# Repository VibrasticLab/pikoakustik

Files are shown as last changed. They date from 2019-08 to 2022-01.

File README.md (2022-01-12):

This is audiometri tool project (still in heavy development).
Main chip are STM32F401RE and Audio-DAC MAX98357A.

### Update:

After a year or so development struggle, now we move to some higher level development stage.
Therefor this repository will be archived and exist only for documentation.

Next development will be moved into new repository: [Pikoakustik2](https://github.com/VibrasticLab/pikoakustik2)

---

### Short Description:

- [x] Fungsional

Mengukur Ambang Pendengaran secara mandiri tanpa perlu bantuan dokter spesialis dan tanpa datang ke klinik.

- [x] Portabel

Dapat digunakan dimana saja dan kapan saja. Baterai mudah diisi ulang.

- [x] Terstandar

Telah terkalibrasi standar Audiometri dan teruji pada ruang *un-echoic*.

- [x] Ramah Pengguna

Antar Muka hanya berupa Tombol dan Lampu LED tanpa pengaturan tambahan dan bisa langsung digunakan.

- [x] Terintergrasi

Terhubung dengan penyimpanan *dedicated server* sehingga dapat diakses dokter spesialis secara jarak jauh jika diperlukan.

---

### Marking Rules:
- [ ] Unfinished
- [x] Finished but Open to Improve
- [x] ~~Finished~~
- [ ] ~~Unused but Noted~~

---

### Implemented Features:

#### User Interaction:

- [X] ~~LED Run Mode Indicator~~
	- [x] ~~Measurement Mode: Blink fast~~
	- [x] ~~Idle Mode: Blink slow~~
	- [x] ~~No Media Mode: Blink fast every 2s~~
- [X] ~~LED TRUE/FALSE~~
- [X] ~~LED Play/MMC~~
- [x] ~~LED 3 Choices~~
- [X] ~~Button Choices~~
	- [x] ~~3 Button Choices~~
	- [x] 3 Choices Random Generator
	- [x] ~~3 Choice Answer Placement~~
- [x] ~~Button Reset~~
- [x] ~~User-Friendlyness Interface Test~~
- [ ] LCD Non-Input Interface
	- [ ] LCD SPI ILI9xxx series

---

#### Packaging

- [x] ~~Acrilic Protector~~
- [ ] Box Design
	- [x] Print 3D
	- [ ] Plastic Molding
	- [x] Brosur Promo with Good Packaging
- [ ] Battery
	- [x] Regulator TP4056
	- [x] ~~LiPo Battery~~
	- [x] ~~Main Power Button~~
	- [ ] Charge/Discharge Test
	- [ ] Battery Manager
	- [x] No Cap except Run Elco

---

#### Data Communication:

- [ ] Serial Data
	- [x] ~~ACM USB-CDC Protocol~~
	- [x] ~~Basic Serial commands~~
	- [x] ~~Media handling commands~~
	- [x] ~~Audiometri control commands~~
	- [ ] HTTP Data control commands

- [x] ~~Media Storage~~
	- [x] ~~MMC Connector Slot~~
	- [x] ~~MMC readyness checking~~
	- [x] ~~FATFS as FAT32 handler~~
	- [x] ~~Via SPI protocol~~

- [ ] IoT Exchanges
	- [x] ESP-12E slot on PCB
	- [x] ESP-12E power jumper
	- [x] WiFi handling
	- [x] Access Point handling
	- [ ] Wifi/AP switch command
	- [ ] HTTP Data exchange
	- [ ] HTTP Data JSON/Format

---

#### Audiometri:

- [ ] Tone Generator
	- [x] ~~Generic I2S Protocol~~
	- [x] ~~Pure Single Tone~~
	- [x] Calibrated Frequency array
	- [x] Pop-Click Suppression
	- [x] Calibrated SPL range
	- [x] Calibrated SPL scaling
	- [x] Left/Right Isolation
	- [ ] Number Headphones
		- [ ] Embedded Tone Model
		- [ ] External Tone Model

- [ ] Hearing Test
	- [x] User Test Flow
	- [ ] **Convinient Level Test**
	- [ ] Random starting SPL
	- [x] Up/Down SPL scaling
	- [ ] Lowest Tone still too loud
	- [ ] Suffle Block
		- [ ] 1 Block is 1 Freq in 1 Channel
		- [ ] Left/Right suffle

- [ ] Microphone Input
	- [ ] Environment Noise Capture
	- [ ] Environment Noise Compensation

- [ ] Mass Production
	- [ ] PCB Electronic
		- [ ] Seeed Studio
		- [ ] ~~DigiKey~~
		- [ ] Xirca
		- [ ] Gerai-Cerdas
		- [ ] ~~Maxtron~~
	- [ ] Packaging

---

### Future Development:

- [ ] Migrate to ESP32
	- [ ] Advantage: Bluetooth Audio A2DP Sources
	- [ ] Advantage: Dual Core CPU as fast as ARM
	- [ ] Advantage: Touch Sensor (replace button)
	- [ ] Disadvantage: Less GPIO pin available
	- [ ] Disadvantage: Re-working all current design
	- [ ] Disadvantage: Re-calibrate and re-test everything

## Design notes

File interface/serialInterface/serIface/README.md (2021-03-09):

# serIface

A new Flutter project.

## Getting Started

This project is a starting point for a Flutter application.

A few resources to get you started if this is your first Flutter project:

- [Lab: Write your first Flutter app](https://flutter.dev/docs/get-started/codelab)
- [Cookbook: Useful Flutter samples](https://flutter.dev/docs/cookbook)

For help getting started with Flutter, view our
[online documentation](https://flutter.dev/docs), which offers tutorials,
samples, guidance on mobile development, and a full API reference.

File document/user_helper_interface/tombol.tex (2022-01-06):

\documentclass[12pt,]{article}
\usepackage[utf8]{inputenc}
\usepackage[T1]{fontenc}
\usepackage{mathptmx}
\usepackage{geometry}
\usepackage{mathtools}
\usepackage[english]{babel}
\usepackage{graphicx}
\usepackage{stackengine}
\usepackage[os=win]{menukeys}
\usepackage{hyperref}
\usepackage{minted}
\usepackage{xcolor}
\usepackage{tikz}
\usepackage[yyyymmdd,hhmmss]{datetime}
\usepackage{etoolbox}
\usepackage{booktabs}

\patchcmd{\thebibliography}{\section*{\refname}}{}{}{}

\newcommand{\ShowOsVersion}{
	\immediate\write18{\unexpanded{foo=`uname -sro` && echo "${foo}" > tmp.tex}}
	\input{tmp}\immediate\write18{rm tmp.tex}
}

\newcommand{\ShowTexVersion}{
	\immediate\write18{\unexpanded{foo=`pdflatex -version | head -n1 | cut -d' ' -f1,2` && echo "${foo}" > tmp.tex}}
	\input{tmp}\immediate\write18{rm tmp.tex}
}

\addto\captionsenglish{\renewcommand{\contentsname}{Daftar Isi}}

\hypersetup{
	colorlinks=true, %set true if you want colored links
	linktoc=all,     %set to all if you want both sections and subsections linked
	linkcolor=blue,  %choose some color if you want links to stand out
	urlcolor=blue,	 %url color
}

\geometry{
	legalpaper,
	left=15mm,
	right=10mm,
	top=10mm,
	bottom=15mm,
}

\title{\Large \bf
	Draft Design Tombol\\
}

\author{Achmadi ST MT}

\date{}

\hypersetup{citecolor=black}

\definecolor{LightGray}{gray}{0.95}

%\pagecolor[rgb]{0.1,0.1,0.1}
%\color[rgb]{1,1,1}

\begin{document}
	\maketitle
	\thispagestyle{empty}
	
	\vspace*{600pt}
	
	\noindent This document written using: \\
	OS : \ShowOsVersion \\
	TeX : \ShowTexVersion \\
	Update: {\today} at \currenttime \\
	
	%%%%%%%%%%%%%%%%%%%%%%%%%%%%%%%%%%%%%%%%%%%%%%%%%%%%%%%%%%%%%%%%%
	
	\newpage
	\begin{figure}[!ht]
		\centering
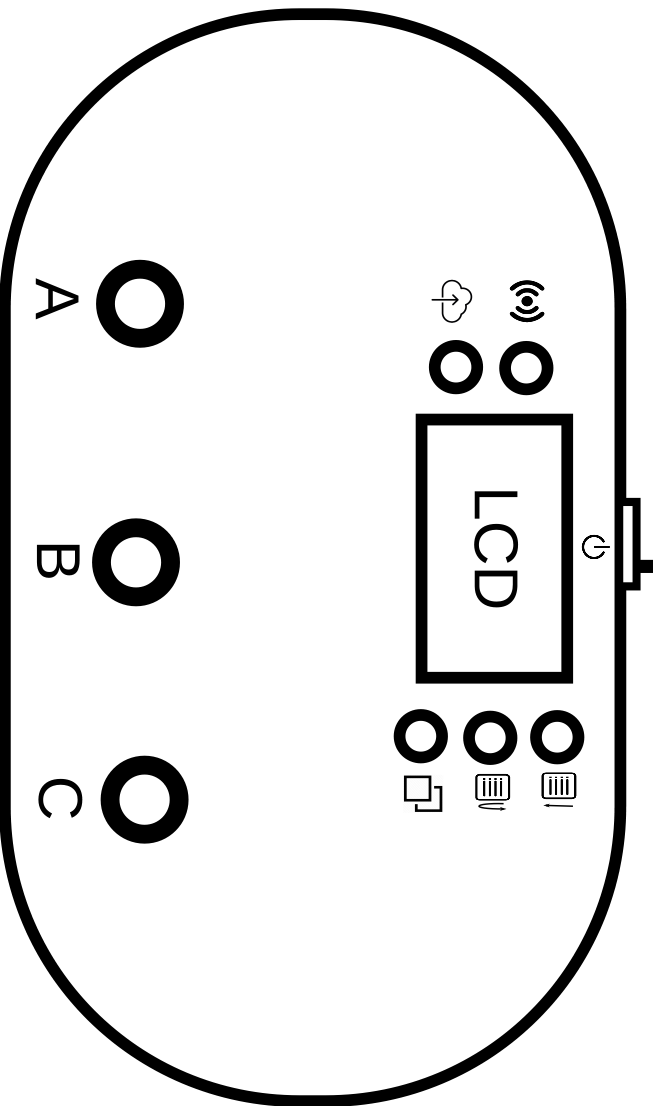
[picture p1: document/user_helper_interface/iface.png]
		
		\caption{Tombol Pengguna}
	\end{figure}

	%%%%%%%%%%%%%%%%%%%%%%%%%%%%%%%%%%%%%%%%%%%%%%%%%%%%%%%%%%%%%%%%%
	
	\newpage
	\section{Daftar Tombol}
	
	Berikut Daftar Tombol untuk Pengguna (diluar Tombol Audiometri):
	
	\begin{table}[H]
		\begin{tabular}{|c|c|}
			\toprule
			
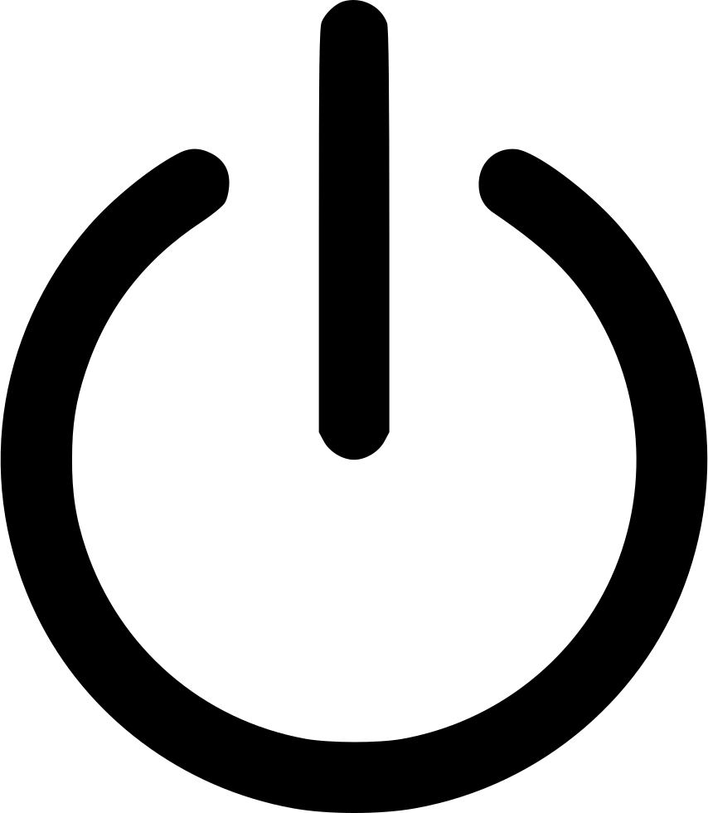
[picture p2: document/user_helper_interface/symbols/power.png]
			\raisebox{-\totalheight}{} & SMD Slide Switch untuk power\textbf{*}
			\\ \midrule
			
			\raisebox{-\totalheight}{} & Seleksi file rekaman langsung memilih rekaman terakhir
			\\ \midrule
			
			\raisebox{-\totalheight}{} & Seleksi file rekaman secara berurutan berulang
			\\ \midrule
			
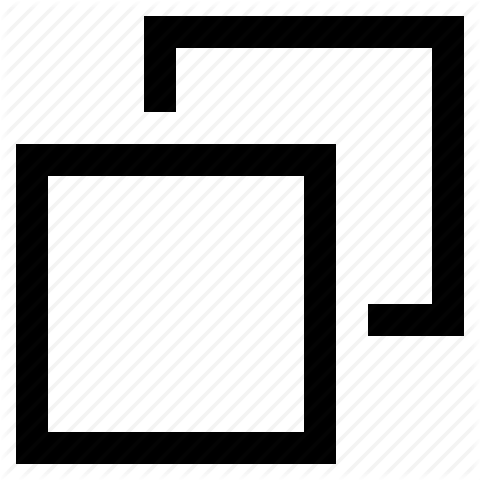
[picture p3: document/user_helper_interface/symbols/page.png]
			\raisebox{-\totalheight}{} & Berpindah halaman yang ditampilkan LCD\textbf{**}
			\\ \midrule
			
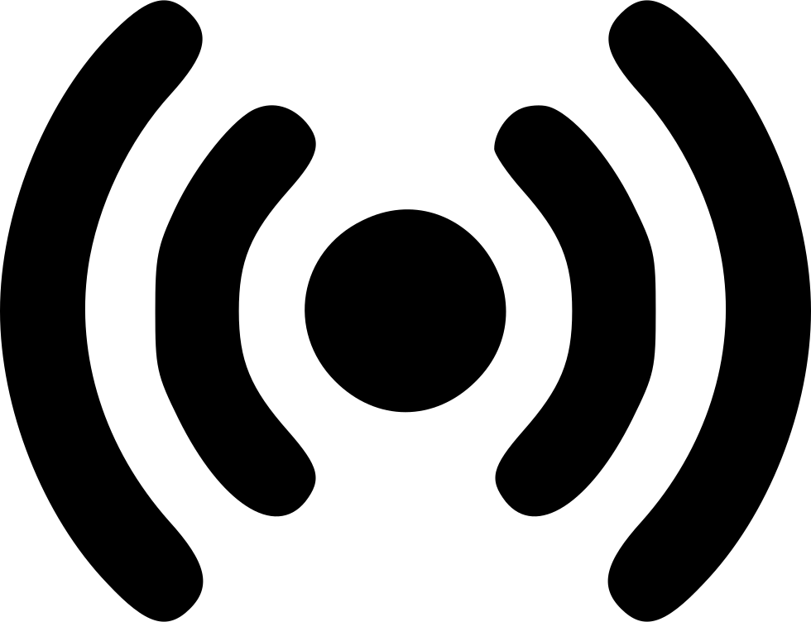
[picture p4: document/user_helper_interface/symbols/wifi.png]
			\raisebox{-\totalheight}{} & Berpindah mode ESP dari Access-Point ke Station atau sebaliknya
			\\ \midrule
			
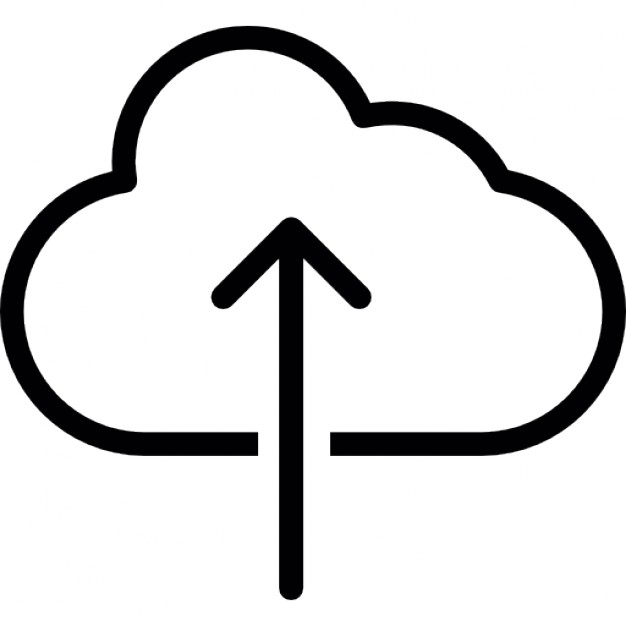
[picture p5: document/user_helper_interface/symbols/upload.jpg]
			\raisebox{-\totalheight}{} & POST request JSON data rekaman ke server
			\\ \midrule
		\end{tabular}
	\end{table}

	\textbf{*}) Contoh SMD Power Switch Slide yang dipilih:
	
	\begin{figure}[!ht]
		\centering
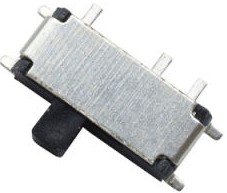
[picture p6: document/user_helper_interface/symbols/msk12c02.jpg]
		
		\caption{MSK12C02}
	\end{figure}

	\textbf{**}) Rencana halaman yang akan ditampilkan di LCD:
	\begin{itemize}
		\item \textbf{Home}. Sebagai halaman pertama yang muncul setelah power on.
		Menampilkan informasi antara lain:
		\begin{itemize}
			\item Persen Battery
			\item Mode ESP sedang dalam Station atau Access Point
			\item Informasi Koneksi seperti IP dan SSID
			\item Mode Audiometri sedang Idle atau Session\\
			Notes: Saat mode Session, maka tampilan dikunci pada halaman Home
		\end{itemize}
		Dapat diakses dengan tombol Pindah Halaman.
	
		\item \textbf{Daftar File}. Menampilkan daftar file untuk dipilih secara berurutan berulang.\\
		Hanya dapat diakses melalu tombol Seleksi File.
		
		\item \textbf{Upload}. Menampilkan proses kirim data file rekaman terpilih.\\
		Hanya dapat diakses melalu tombol Upload.
		
		\item \textbf{Audiogram}. Menampilkan preview data Audiogram dari file rekaman terpilih.\\
		Dapat diakses dengan tombol Pindah Halaman.
		
		\item \textbf{Metadata}. Menampilkan metadata dari file rekaman terpilih.\\
		Dapat diakses dengan tombol Pindah Halaman.
	\end{itemize}

	\textbf{Tambahan:}
	\begin{itemize}
		\item Untuk tombol memulai Audiometri dan 3-Force Choice tetap menggunakan 3 tombol Audiometri \textbf{A-B-C}.
		\item Port USB untuk komunikasi serial dengan PC tetap diperlukan untuk proses debugging/kontrol selama proses development.
	\end{itemize}

\end{document}

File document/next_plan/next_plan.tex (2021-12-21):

\documentclass[12pt,]{article}
\usepackage[utf8]{inputenc}
\usepackage[T1]{fontenc}
\usepackage{mathptmx}
\usepackage{geometry}
\usepackage{mathtools}
\usepackage[english]{babel}
\usepackage{graphicx}
\usepackage{stackengine}
\usepackage[os=win]{menukeys}
\usepackage{hyperref}
\usepackage{minted}
\usepackage{xcolor}
\usepackage{tikz}
\usepackage[yyyymmdd,hhmmss]{datetime}
\usepackage{etoolbox}

\patchcmd{\thebibliography}{\section*{\refname}}{}{}{}

\newcommand{\ShowOsVersion}{
	\immediate\write18{\unexpanded{foo=`uname -sro` && echo "${foo}" > tmp.tex}}
	\input{tmp}\immediate\write18{rm tmp.tex}
}

\newcommand{\ShowTexVersion}{
	\immediate\write18{\unexpanded{foo=`pdflatex -version | head -n1 | cut -d' ' -f1,2` && echo "${foo}" > tmp.tex}}
	\input{tmp}\immediate\write18{rm tmp.tex}
}

\addto\captionsenglish{\renewcommand{\contentsname}{Daftar Isi}}

\hypersetup{
	colorlinks=true, %set true if you want colored links
	linktoc=all,     %set to all if you want both sections and subsections linked
	linkcolor=blue,  %choose some color if you want links to stand out
	urlcolor=blue,	 %url color
}

\geometry{
	legalpaper,
	left=15mm,
	right=10mm,
	top=10mm,
	bottom=15mm,
}

\title{\Large \bf
	Draft Design\\
}

\author{Achmadi ST MT}

\date{}

\hypersetup{citecolor=black}

\definecolor{LightGray}{gray}{0.95}

%\pagecolor[rgb]{0.1,0.1,0.1}
%\color[rgb]{1,1,1}

\begin{document}
	\maketitle
	\thispagestyle{empty}
	
	\vspace*{600pt}
	
	\noindent This document written using: \\
	OS : \ShowOsVersion \\
	TeX : \ShowTexVersion \\
	Update: {\today} at \currenttime \\
	
	%%%%%%%%%%%%%%%%%%%%%%%%%%%%%%%%%%%%%%%%%%%%%%%%%%%%%%%%%%%%%%%%%
	
	\newpage
	\begin{figure}[!ht]
		\centering
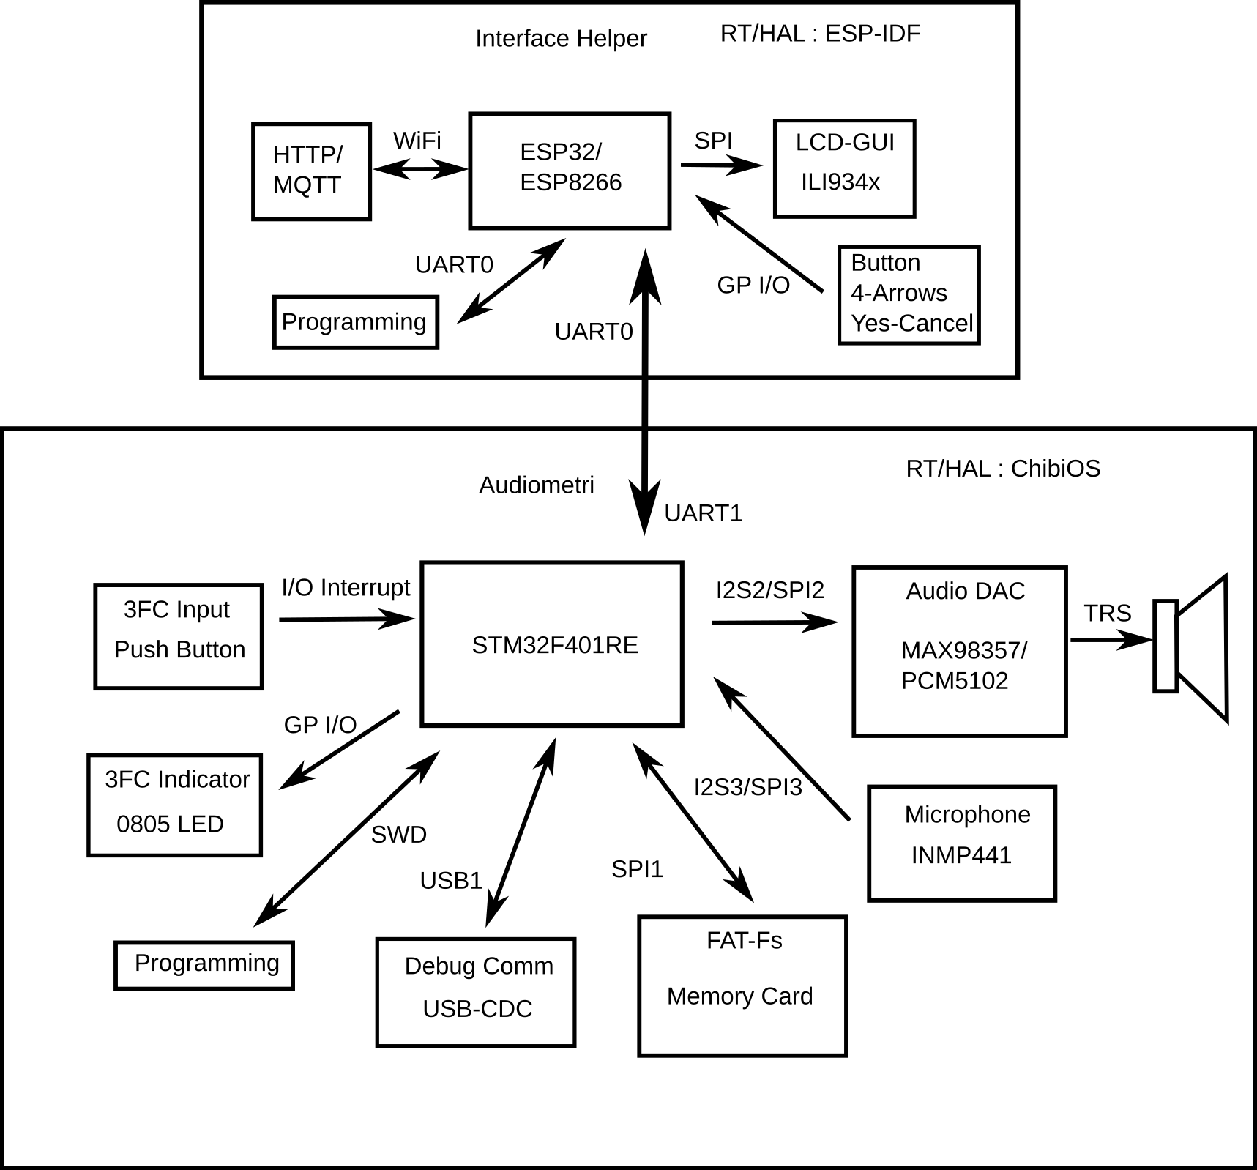
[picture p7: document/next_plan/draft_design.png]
		
		\caption{Simplified}
	\end{figure}

	Currently Developed Design:
	\begin{itemize}
		\item Circuit:\\
		\url{https://github.com/VibrasticLab/pikoakustik/tree/stm32f401re_3pin/circuit/test_3rev1}
		
		\item Audiometri (ChibiOS/RT in STM32F410RE):
		\begin{itemize}
			\item Audio DAC MAX98357A:\\
			\url{https://github.com/VibrasticLab/pikoakustik/blob/stm32f401re_3pin/firmware/ht_audio.c}
			
			\item FAT-Fs Memory Card:\\
			\url{https://github.com/VibrasticLab/pikoakustik/blob/stm32f401re_3pin/firmware/ht_mmc.c}
			
			\item Debug Communication:\\
			\url{https://github.com/VibrasticLab/pikoakustik/blob/stm32f401re_3pin/firmware/ht_comm.c}
			
			\item 3FC Audiometri:\\
			\url{https://github.com/VibrasticLab/pikoakustik/blob/stm32f401re_3pin/firmware/ht_exti.c}\\
			\url{https://github.com/VibrasticLab/pikoakustik/blob/stm32f401re_3pin/firmware/ht_led.c}\\
			\url{https://github.com/VibrasticLab/pikoakustik/blob/stm32f401re_3pin/firmware/ht_metri.c}
			
			\item Microphone INMP441:\\
			(in development)
			
		\end{itemize}
	
		\item ESP32 Interface:\\
		(in development)
	\end{itemize}
\end{document}

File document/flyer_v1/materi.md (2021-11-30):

# Materi Konten Flyer

## Acara
- Health Business Gathering Desember 3rd-4th, 2021

## GuideLines/Materi
- Dilarang Foto Unit Asli (arahan Pak Dhany)
- Gambar Sketsa 
	+ Gambar.1 Sketsa prototype di dokumen Paten (sketsa_unit.png)
	+ Gambar.2 Sketsa penggunaan Prototype di dokumen Paten (sketsa_penggunaan.png)
- Model 3D unit (tanpa keterangan apa pun) di file mockup.png
- Model Alur Data sekilas (alur_data.png)

## Emphasis
- [x] User Friendly
- [x] Handheld Portable
- [x] Embeddded IoT Based
- [x] Calibrated Tone

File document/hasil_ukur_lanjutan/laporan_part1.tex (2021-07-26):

\documentclass[12pt,]{article}
\usepackage[utf8]{inputenc}
\usepackage[T1]{fontenc}
\usepackage{mathptmx}
\usepackage{geometry}
\usepackage{mathtools}
\usepackage[english]{babel}
\usepackage{graphicx}
\usepackage{subcaption}
\usepackage{stackengine}
\usepackage[os=win]{menukeys}
\usepackage{hyperref}
\usepackage{minted}
\usepackage{xcolor}
\usepackage{tikz}
\usepackage[yyyymmdd,hhmmss]{datetime}
\usepackage{etoolbox}
\usepackage[inline]{enumitem}
\usepackage{pdfpages}

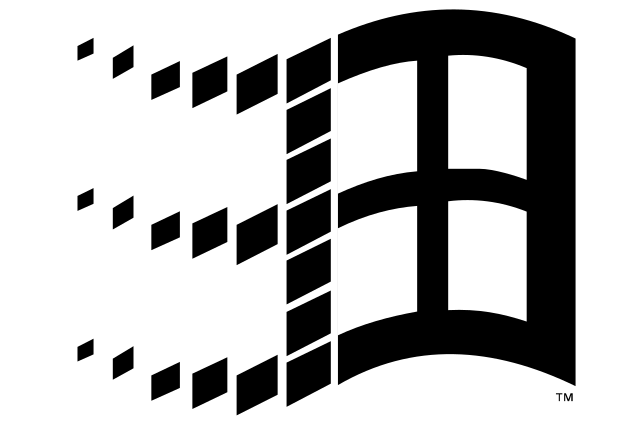
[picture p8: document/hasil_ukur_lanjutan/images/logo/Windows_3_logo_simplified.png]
\newcommand{\WindowsLogo}{\raisebox{-0.1em}{}}
%\newcommand{\PowerLogo}{\raisebox{-0.1em}{\includegraphics[height=0.8em]{images/logo/power}}}
\newcommand{\WinKey}{\keys{\WindowsLogo}}
\newcommand{\PowerKey}{\keys{\PowerLogo}}

\patchcmd{\thebibliography}{\section*{\refname}}{}{}{}

\newcommand{\ShowOsVersion}{
	\immediate\write18{\unexpanded{foo=`uname -sro` && echo "${foo}" > tmp.tex}}
	\input{tmp}\immediate\write18{rm tmp.tex}
}

\newcommand{\ShowTexVersion}{
	\immediate\write18{\unexpanded{foo=`pdflatex -version | head -n1 | cut -d' ' -f1,2` && echo "${foo}" > tmp.tex}}
	\input{tmp}\immediate\write18{rm tmp.tex}
}

\addto\captionsenglish{\renewcommand{\contentsname}{Daftar Isi}}
\addto\captionsenglish{\renewcommand{\figurename}{Gambar}}

\hypersetup{
	colorlinks=true, %set true if you want colored links
	linktoc=all,     %set to all if you want both sections and subsections linked
	linkcolor=blue,  %choose some color if you want links to stand out
	urlcolor=blue,   %url color
}

\geometry{
	a4paper,
	left=10mm,
	right=10mm,
	top=10mm,
	bottom=15mm,
}

\title{\LARGE \bf
	Laporan Pengujian Unit Prototype Handheld Audiometri (Tahap 1)\\
}

\author{Achmadi ST MT}

\date{}

\hypersetup{citecolor=black}

\definecolor{LightGray}{gray}{0.95}

%\pagecolor[rgb]{0.1,0.1,0.1}
%\color[rgb]{1,1,1}

\begin{document}
	\thispagestyle{empty}

	\begin{titlepage}
		\centering
		\vfill
		\vfill
		\maketitle
		\vfill
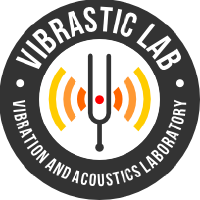
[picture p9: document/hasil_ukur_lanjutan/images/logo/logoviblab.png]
		
		\vfill
		\vfill
		Update: {\today} \currenttime \\
	\end{titlepage}

	%%%%%%%%%%%%%%%%%%%%%%%%%%%%%%%%%%%%%%%%%%%%%%%%%%%%%%%%%%%%%%%%%

	\newpage
	\tableofcontents

	%%%%%%%%%%%%%%%%%%%%%%%%%%%%%%%%%%%%%%%%%%%%%%%%%%%%%%%%%%%%%%%%%

	\newpage
	\section{Pendahuluan}

	\subsection{Tujuan Pengujian}

	Tujuan Pengujian disini adalah untuk mengetahui nilai aktual \textit{loudness} output dalam dB (SPL).

	\subsection{Waktu dan Tempat Pengujian}

	Seluruh pengujian di lakukan di Ruang Un-Echoic Chamber Laboratorium Fisika Bangunan Teknik Fisika
	Institut Teknologi Bandung. Waktu pengujian adalah minggu kedua di bulan Desember 2020.

	\subsection{Batasan Pengujian}

	Batasan pengujian adalah sebagai berikut:

	\begin{enumerate}
		\item Nilai frekuensi dan konsistensi frekuensi tidak diukur di ruang Unechoic chamber tersebut di atas
		karena telah diuji selama proses pengembangan dan perakitan unit prototype dan telah terbukti konsisten pada nilai yang diinginkan.

		\item Pengujian tidak dilakukan pada tubuh manusia sebenarnya melainkan menggunakan manekin yang diproduksi oleh GRASS KEMAR.
	\end{enumerate}

	%%%%%%%%%%%%%%%%%%%%%%%%%%%%%%%%%%%%%%%%%%%%%%%%%%%%%%%%%%%%%%%%%

	\newpage
	\section{Metode Pengujian}

	\subsection{Persiapan}

	Berikut adalah perangkat keras yang perlu disiapkan untuk pengujian ini:

	\begin{itemize}

		\item Unit Prototype Audiometri yang akan diuji.

		Pastikan unit prototype masih normal sebagaimana pada bab sebelumnya.

		\begin{figure}[!ht]
			\centering
			\begin{subfigure}[b]{0.3\textwidth}
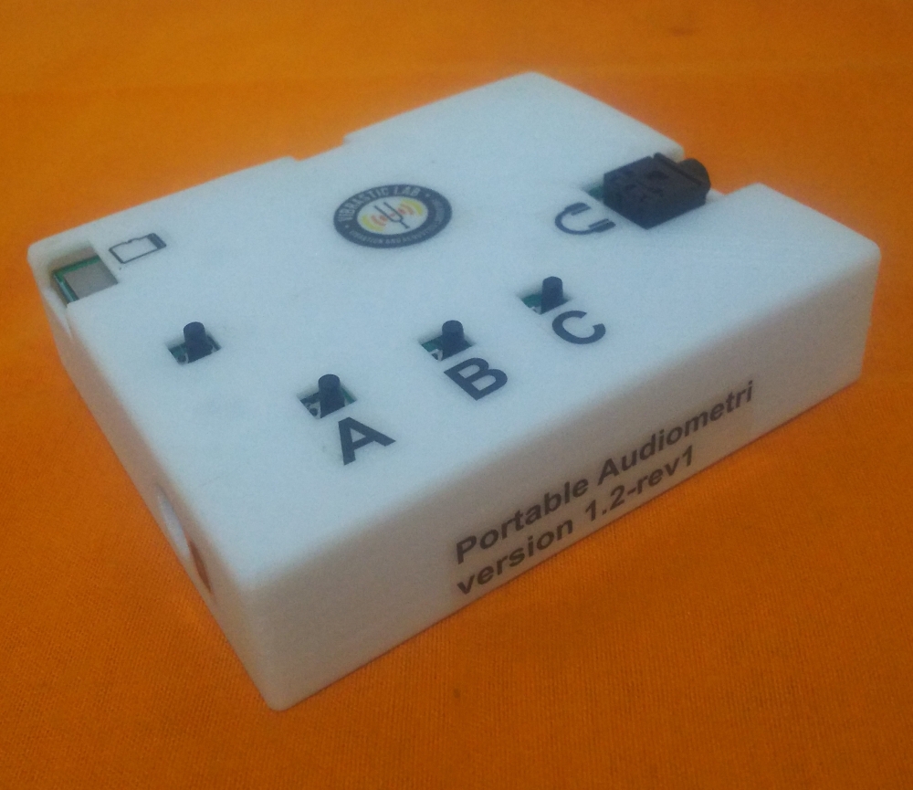
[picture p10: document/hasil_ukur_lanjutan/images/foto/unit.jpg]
				
				\caption{Unit Prototype}
			\end{subfigure}
			\begin{subfigure}[b]{0.3\textwidth}
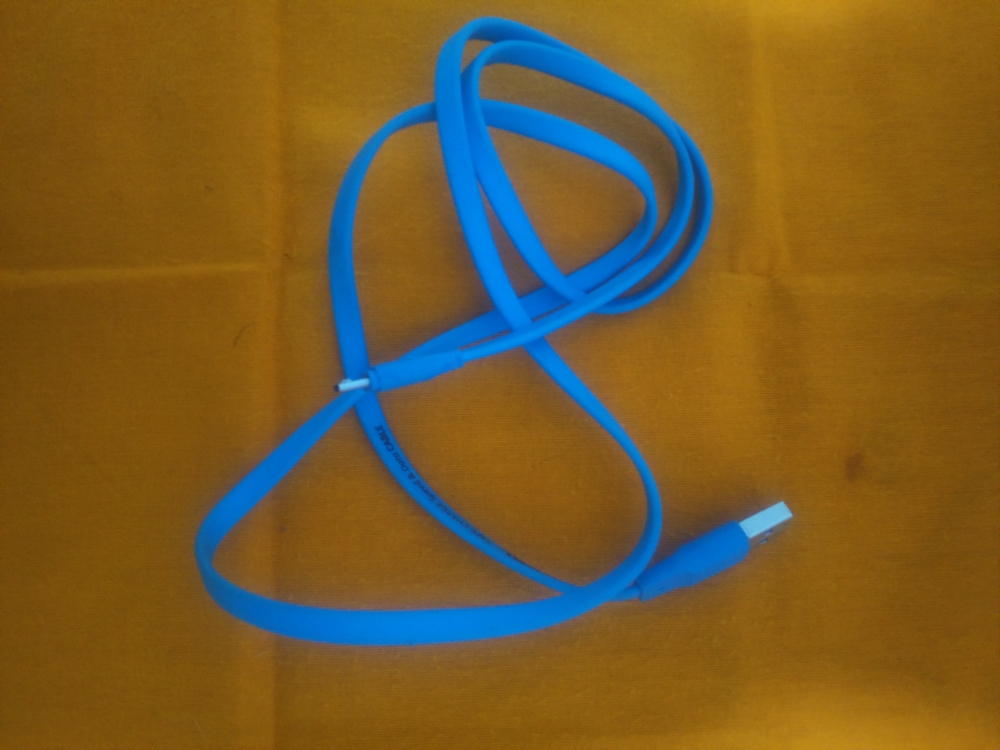
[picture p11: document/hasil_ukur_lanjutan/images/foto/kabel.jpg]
				
				\caption{Kabel USB}
			\end{subfigure}
			\caption{Prototype}
		\end{figure}

		\item Wired-Headphone dengan impedansi tiap channel antara $32\Omega$ hingga $300\Omega$

		Headphone yang digunakan disini adalah:
		\begin{itemize}
			\item Headphone Miniso (tanpa active noise cancelling)
			\item Headphone BOSE (dilengkapi active noise cancelling)
		\end{itemize}
		\begin{figure}[!ht]
			\centering
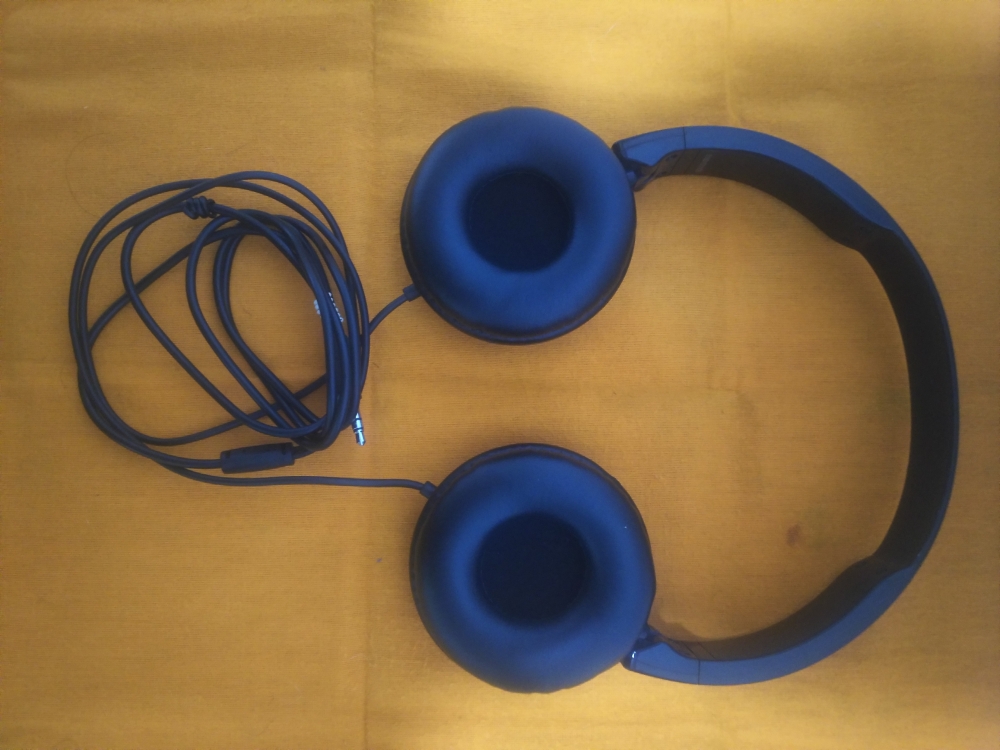
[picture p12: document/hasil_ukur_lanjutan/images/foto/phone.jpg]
			
			\caption{Wired Headphone}
		\end{figure}

		\newpage
		\item Kalibrasi Mikrofon pada manekin KEMAR menggunakan \textit{tone generator} yang tersedia pada paket GRASS KEMAR.
		Kemudian pasang Headphone pada manekin.
		\begin{figure}[!ht]
			\centering
			\begin{subfigure}[b]{0.3\textwidth}
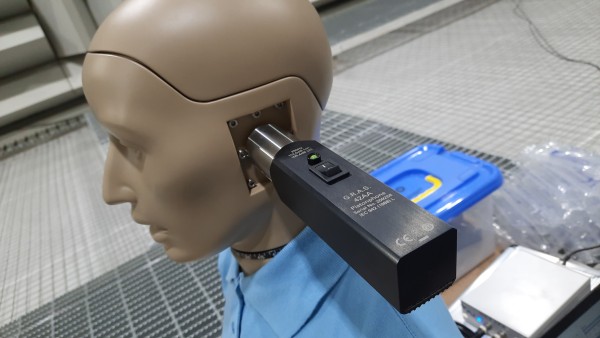
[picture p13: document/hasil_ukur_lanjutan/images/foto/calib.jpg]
				
				\caption{Kalibrasi Mikrofon}
			\end{subfigure}
			\begin{subfigure}[b]{0.3\textwidth}
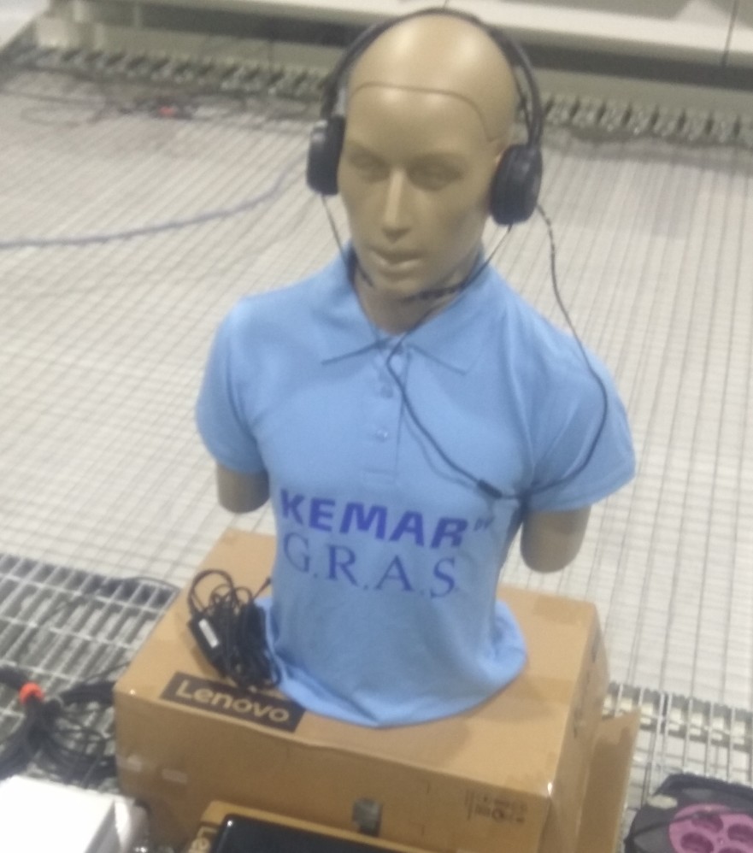
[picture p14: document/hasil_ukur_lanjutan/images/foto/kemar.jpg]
				
				\caption{Headphone Terpasang}
			\end{subfigure}
			\caption{GRASS KEMAR}
		\end{figure}

	\end{itemize}

	\subsection{Audio Analyzer}

	Mikrofon GRASS KEMAR dihubungkan dengan Audio-Box dan data Audio digital dikumpulkan dengan perangkat lunak Real-Time Analyzer via USB.
	Perangkat lunak ini merupakan bagian dari paket software DSFF3 buatan Yoshimasha.

	\begin{figure}[!ht]
		\centering
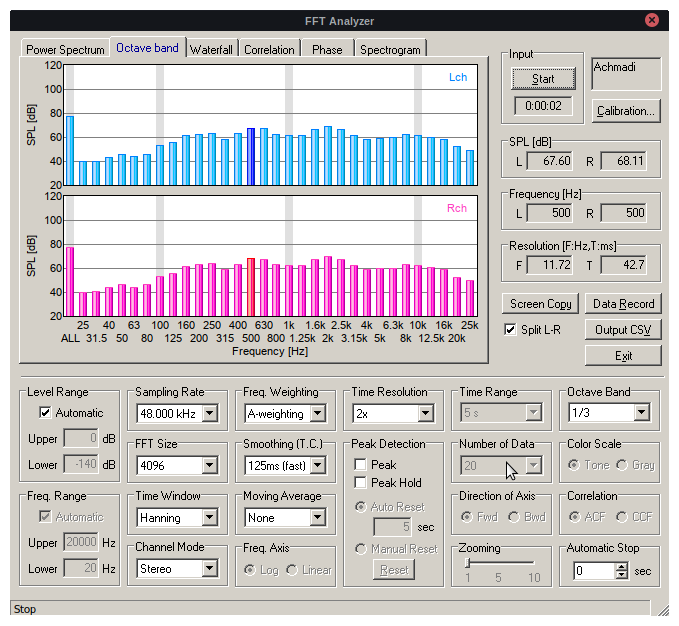
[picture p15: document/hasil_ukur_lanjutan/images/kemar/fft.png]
		
		\caption{Tampilan Audio Analyzer}
	\end{figure}

	\newpage
	\subsection{Teknis Pengujian}

	Berikut langkah proses pengujian

	\begin{itemize}
		\item Nyalakan unit prototype dan sambungkan USB protype ke komputer.
		\begin{figure}[!ht]
			\centering
			\begin{subfigure}[b]{0.3\textwidth}
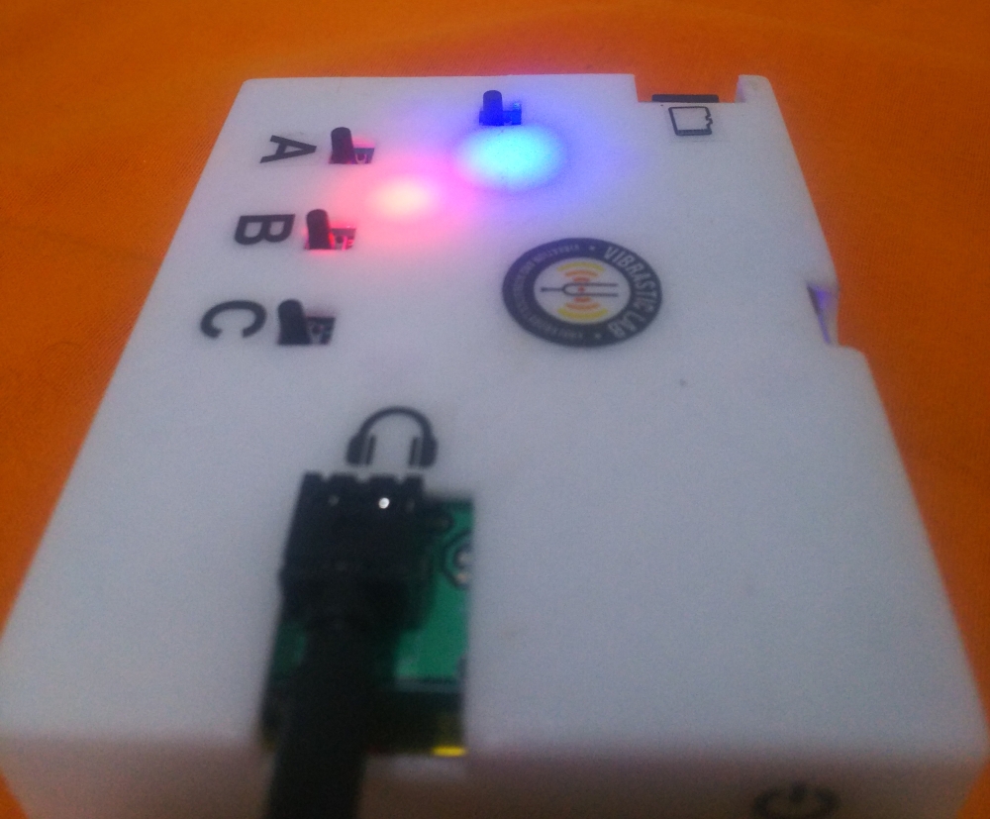
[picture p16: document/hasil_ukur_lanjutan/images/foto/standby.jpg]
				
				\caption{Prototype Standby}
			\end{subfigure}
			\begin{subfigure}[b]{0.3\textwidth}
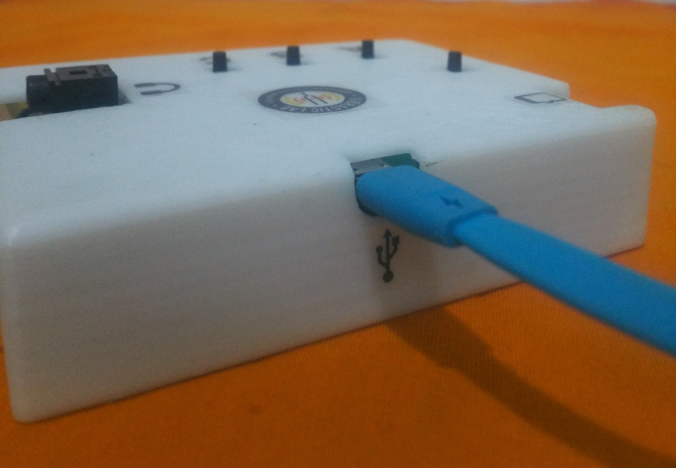
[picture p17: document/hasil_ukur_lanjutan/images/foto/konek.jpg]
				
				\caption{USB Terpasang}
			\end{subfigure}
			\caption{Menyalakan Unit Prototype}
		\end{figure}

		\item Akses prototype menggunakan serial port (semisal Hercules.exe) pada komputer.
		\begin{figure}[!ht]
			\centering
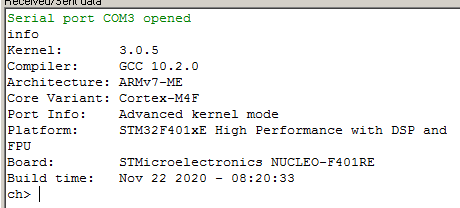
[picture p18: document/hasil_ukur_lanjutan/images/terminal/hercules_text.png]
			
			\caption{Contoh respon serial port}
		\end{figure}

		\item Perintah Serial untuk membangkitkan tone
		Perintah untuk membangkitkan tone dengan frekuensi dan skala yang diinginkan selama 5detik.

		Pola perintah serialnya adalah:
		\begin{minted}[frame=lines,framesep=2mm,fontsize=\small]{text}
out <frekuensi> <amplitudo>
		\end{minted}

		dengan:
		\begin{itemize}

			\item frekuensi adalah nilai frekuensi (dalam Hz) mulai 250, 500, 1000, 2000, 4000, dan 8000.

			\item amplitudo adalah skala amplitudo pada nilai 1, 2, 3, 4, 5, 6, 7, 8, dan 9.

		\end{itemize}

		Contoh untuk tone 500Hz pada skala amplitudo 6 (diakhiri (\keys{\return})):
		\begin{minted}[frame=lines,framesep=2mm,fontsize=\small]{text}
out 500 6
		\end{minted}

		\newpage
		Maka salah satu channel headphone yang terhubung prototype akan membangkitkan tone selama 5 detik.

		\begin{figure}[!ht]
			\centering
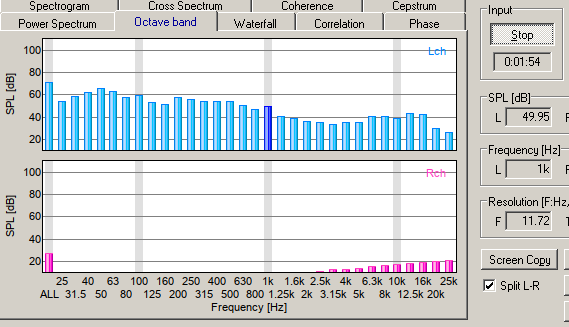
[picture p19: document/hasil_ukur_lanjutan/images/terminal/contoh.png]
			
			\caption{Contoh Nilai Uji}
		\end{figure}

		\item Hasil yang diinginkan adalah tabel dengan spesifikasi berikut:
		\begin{itemize}
			\item tabel loudness output di setiap frekuensi untuk setiap skala amplitudo, untuk 2 prototype dengan 2 headphone
			\item tabel loudness output di setiap frekuensi untuk setiap skala amplitudo, untuk 2 prototype dengan 2 headphone
		\end{itemize}

		sehingga diharapkan total 4 tabel hasil pengukuran.
	\end{itemize}

	\newpage
	\section{Hasil Pengujian}

	\subsection{Tabel Hasil}

	Tabel hasil pengujian cukuk banyak yang akan memakan tempat disini sehingga disediakan tempat di repository pemrograman Lab Vibrastic pada tautan berikut:\\
	\url{https://github.com/VibrasticLab/pikoakustik/tree/stm32f401re_3pin/document/hasil_ukur_lanjutan/tabel_hasil_ukur}.\\

	Kemudian untuk memudahkan proses pengolahan data, digunakan pula perangkat lunak Jupyter Note yang berkasnya dapat diakses di tautan:\\
	\url{https://github.com/VibrasticLab/pikoakustik/blob/stm32f401re_3pin/document/hasil_ukur_lanjutan/python/hasil_itb.ipynb}\\

	\subsection{Pengolahan Data}

	Pengolahan data hasil pengujian digunakan untuk mendapatkan model loudness.

		Dengan merata-rata matrix tabel didapat matrix untuk headphone Bose sebagai berikut:

		\[\left[
		\begin{matrix}
			34.4 & 36.5 & 40.7 & 45.7 & 51.4 & 57.4 & 63.4 & 69.5 & 75.6 \\
			32.6 & 35.8 & 40.2 & 44.9 & 50.2 & 56.6 & 62.7 & 68.8 & 74.8 \\
			37.7 & 41   & 45.5 & 51   & 56.8 & 62.9 & 69   & 75   & 81   \\
			36.3 & 38.6 & 42.4 & 47.7 & 53.2 & 59.2 & 65.4 & 71.4 & 77.4 \\
			41.1 & 43.8 & 48   & 53.2 & 59   & 64.9 & 71.1 & 77.1 & 83.1 \\
			41.8 & 42.6 & 44.9 & 49   & 54.4 & 60.2 & 66.2 & 72.2 & 78.2 \\
		\end{matrix}
		\right]\]

		Pendekatan model matematis untuk loudness terhadap skala input menggunakan polynomial:\\
		\[f(x) = ax^3 + bx^2 + cx + d\]

		Estimasi model menggunakan perangkat lunak Numpy Polyfit yang tersedia di Python.
		Hasil estimasi untuk headphone Bose pada setiap frekuensi.

		\[f_{250}(x) = 0.05x^3 - 0.46x^2 - 4.7x + 80.5\]
		\[f_{500}(x) = 0.03x^3 - 0.28x^2 - 5.4x + 80.48\]
		\[f_{1000}(x) = 0.04x^3 - 0.4x^2 - 4.8x + 86.06\]
		\[f_{2000}(x) = 0.05x^3 - 0.49x^2 - 4.59x + 82.33\]
		\[f_{4000}(x) = 0.04x^3 - 0.44x^2 - 4.72x + 88.12\]
		\[f_{8000}(x) = 0.06x^3 - 0.59x^2 - 4.37x + 83\]

		Selanjutnya untuk headphone Miniso, dilakukan metode perhitungan yang sama.

		Berikut matrix rata-rata loudness pengukuran:

		\[\left[
		\begin{matrix}
			36   & 39.5 & 44.2 & 49.7 & 55.6 & 61.4 & 67.4 & 73.4 & 79.4 \\
			36.7 & 40.5 & 45.4 & 50.8 & 56.7 & 62.6 & 68.6 & 74.6 & 80.6 \\
			39.9 & 43.6 & 48.6 & 54.2 & 60   & 65.9 & 71.8 & 77.8 & 83.8 \\
			33   & 35.4 & 39.6 & 44.7 & 50.4 & 56.4 & 62.4 & 68.3 & 74.4 \\
			32.7 & 33.4 & 35.3 & 39.2 & 44.3 & 50   & 56   & 62   & 68   \\
			35.6 & 36.2 & 38.3 & 41.8 & 47   & 52.6 & 58.6 & 64.6 & 70.5 \\
		\end{matrix}
		\right]\]

        \newpage
		Hasil estimasi untuk Headphone Miniso pada setiap frekuensi.

		\[f_{250}(x) = 0.03x^3 - 0.32x^2 - 4.99x + 84.58\]
		\[f_{500}(x) = 0.03x^3 - 0.28x^2 - 5.16x + 85.93\]
		\[f_{1000}(x) = 0.03x^3 - 0.28x^2 - 5.09x + 36.38\]
		\[f_{2000}(x) = 0.04x^3 - 0.46x^2 - 4.63x + 37.21\]
		\[f_{4000}(x) = 0.06x^3 - 0.53x^2 - 4.64x + 39.77\]
		\[f_{8000}(x) = 0.06x^3 - 0.51x^2 - 4.67x + 42.73\]

	\newpage
	\section{Lampiran}

	\subsection{Notebook Olah Data}
	\includepdf[pages=-]{python/hasil_itb.pdf}

\end{document}

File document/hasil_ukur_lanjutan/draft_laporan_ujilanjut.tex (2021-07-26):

\documentclass[12pt,]{article}
\usepackage[utf8]{inputenc}
\usepackage[T1]{fontenc}
\usepackage{mathptmx}
\usepackage{geometry}
\usepackage{mathtools}
\usepackage[english]{babel}
\usepackage{graphicx}
\usepackage{subcaption}
\usepackage{stackengine}
\usepackage[os=win]{menukeys}
\usepackage{hyperref}
\usepackage{minted}
\usepackage{xcolor}
\usepackage{tikz}
\usepackage[yyyymmdd,hhmmss]{datetime}
\usepackage{etoolbox}
\usepackage[inline]{enumitem}
\usepackage{pdfpages}

\newcommand{\WindowsLogo}{\raisebox{-0.1em}{}}
%\newcommand{\PowerLogo}{\raisebox{-0.1em}{\includegraphics[height=0.8em]{images/logo/power}}}
\newcommand{\WinKey}{\keys{\WindowsLogo}}
\newcommand{\PowerKey}{\keys{\PowerLogo}}

\patchcmd{\thebibliography}{\section*{\refname}}{}{}{}

\newcommand{\ShowOsVersion}{
	\immediate\write18{\unexpanded{foo=`uname -sro` && echo "${foo}" > tmp.tex}}
	\input{tmp}\immediate\write18{rm tmp.tex}
}

\newcommand{\ShowTexVersion}{
	\immediate\write18{\unexpanded{foo=`pdflatex -version | head -n1 | cut -d' ' -f1,2` && echo "${foo}" > tmp.tex}}
	\input{tmp}\immediate\write18{rm tmp.tex}
}

\addto\captionsenglish{\renewcommand{\contentsname}{Daftar Isi}}
\addto\captionsenglish{\renewcommand{\figurename}{Gambar}}

\hypersetup{
	colorlinks=true, %set true if you want colored links
	linktoc=all,     %set to all if you want both sections and subsections linked
	linkcolor=blue,  %choose some color if you want links to stand out
	urlcolor=blue,   %url color
}

\geometry{
	a4paper,
	left=10mm,
	right=10mm,
	top=10mm,
	bottom=15mm,
}

\title{\LARGE \bf
	Laporan Pengujian Unit Prototype Portable/Handheld Audiometri\\
}

\author{Achmadi ST MT}

\date{}

\hypersetup{citecolor=black}

\definecolor{LightGray}{gray}{0.95}

%\pagecolor[rgb]{0.1,0.1,0.1}
%\color[rgb]{1,1,1}

\begin{document}
	\thispagestyle{empty}

	\begin{titlepage}
		\centering
		\vfill
		\vfill
		\maketitle
		\vfill
		
		\vfill
		\vfill
		Update: {\today} \currenttime \\
	\end{titlepage}

	%%%%%%%%%%%%%%%%%%%%%%%%%%%%%%%%%%%%%%%%%%%%%%%%%%%%%%%%%%%%%%%%%

	\newpage
	\tableofcontents

	%%%%%%%%%%%%%%%%%%%%%%%%%%%%%%%%%%%%%%%%%%%%%%%%%%%%%%%%%%%%%%%%%

	\newpage
	\section{Pendahuluan}

	\subsection{Tujuan Pengujian}

	Tujuan Pengujian disini adalah untuk mendapatkan parameter berikut:
	\begin{enumerate}
		\item Mengetahui nilai aktual \textit{loudness} output dalam dB (SPL).
		\item Mengetahui efek histeresis terhadap konsistensi output \textit{loudness}.
	\end{enumerate}

	\subsection{Waktu dan Tempat Pengujian}

	Seluruh pengujian di lakukan di Ruang Un-Echoic Chamber Laboratorium Fisika Bangunan Teknik Fisika
	Institut Teknologi Bandung. Waktu pengujian terbagi dalam 2 periode, pertama pada bulan Desember 2020 dan Februari 2021.

	\subsection{Batasan Pengujian}

	Batasan pengujian adalah sebagai berikut:

	\begin{enumerate}
		\item Nilai frekuensi dan konsistensi frekuensi tidak diukur di ruang Unechoic chamber tersebut di atas
		karena telah diuji selama proses pengembangan dan perakitan unit prototype dan telah terbukti konsisten pada nilai yang diinginkan.

		\item Pengujian tidak dilakukan pada tubuh manusia sebenarnya melainkan menggunakan manekin yang diproduksi oleh GRASS KEMAR.
	\end{enumerate}

	%%%%%%%%%%%%%%%%%%%%%%%%%%%%%%%%%%%%%%%%%%%%%%%%%%%%%%%%%%%%%%%%%

	\newpage
	\section{Metode Pengujian}

	\subsection{Persiapan}

	Berikut adalah perangkat keras yang perlu disiapkan untuk pengujian ini:

	\begin{itemize}

		\item Unit Prototype Audiometri yang akan diuji.

		Pastikan unit prototype masih normal sebagaimana pada bab sebelumnya.

		\begin{figure}[!ht]
			\centering
			\begin{subfigure}[b]{0.3\textwidth}
				
				\caption{Unit Prototype}
			\end{subfigure}
			\begin{subfigure}[b]{0.3\textwidth}
				
				\caption{Kabel USB}
			\end{subfigure}
			\caption{Prototype}
		\end{figure}

		\item Wired-Headphone dengan impedansi tiap channel antara $32\Omega$ hingga $300\Omega$

		Headphone yang digunakan disini adalah:
		\begin{itemize}
			\item Headphone Miniso (tanpa active noise cancelling)
			\item Headphone BOSE (dilengkapi active noise cancelling)
		\end{itemize}
		\begin{figure}[!ht]
			\centering
			
			\caption{Wired Headphone}
		\end{figure}

		\newpage
		\item Kalibrasi Mikrofon pada manekin KEMAR menggunakan \textit{tone generator} yang tersedia pada paket GRASS KEMAR.
		Kemudian pasang Headphone pada manekin.
		\begin{figure}[!ht]
			\centering
			\begin{subfigure}[b]{0.3\textwidth}
				
				\caption{Kalibrasi Mikrofon}
			\end{subfigure}
			\begin{subfigure}[b]{0.3\textwidth}
				
				\caption{Headphone Terpasang}
			\end{subfigure}
			\caption{GRASS KEMAR}
		\end{figure}

	\end{itemize}

	\subsection{Audio Analyzer}

	Mikrofon GRASS KEMAR dihubungkan dengan Audio-Box dan data Audio digital dikumpulkan dengan perangkat lunak Real-Time Analyzer via USB.
	Perangkat lunak ini merupakan bagian dari paket software DSFF3 buatan Yoshimasha.

	\begin{figure}[!ht]
		\centering
		
		\caption{Tampilan Audio Analyzer}
	\end{figure}

	\newpage
	\subsection{Teknis Pengujian}

	Berikut langkah proses pengujian

	\begin{itemize}
		\item Nyalakan unit prototype dan sambungkan USB protype ke komputer.
		\begin{figure}[!ht]
			\centering
			\begin{subfigure}[b]{0.3\textwidth}
				
				\caption{Prototype Standby}
			\end{subfigure}
			\begin{subfigure}[b]{0.3\textwidth}
				
				\caption{USB Terpasang}
			\end{subfigure}
			\caption{Menyalakan Unit Prototype}
		\end{figure}

		\item Akses prototype menggunakan serial port (semisal Hercules.exe) pada komputer.
		\begin{figure}[!ht]
			\centering
			
			\caption{Contoh respon serial port}
		\end{figure}

		\item Perintah Serial untuk membangkitkan tone
		Perintah untuk membangkitkan tone dengan frekuensi dan skala yang diinginkan selama 5detik.

		Pola perintah serialnya adalah:
		\begin{minted}[frame=lines,framesep=2mm,fontsize=\small]{text}
out <frekuensi> <amplitudo>
		\end{minted}

		dengan:
		\begin{itemize}

			\item frekuensi adalah nilai frekuensi (dalam Hz) mulai 250, 500, 1000, 2000, 4000, dan 8000.

			\item amplitudo adalah skala amplitudo pada nilai 1, 2, 3, 4, 5, 6, 7, 8, dan 9.

		\end{itemize}

		Contoh untuk tone 500Hz pada skala amplitudo 6 (diakhiri (\keys{\return})):
		\begin{minted}[frame=lines,framesep=2mm,fontsize=\small]{text}
out 500 6
		\end{minted}

		\newpage
		Maka salah satu channel headphone yang terhubung prototype akan membangkitkan tone selama 5 detik.

		\begin{figure}[!ht]
			\centering
			
			\caption{Contoh Nilai Uji}
		\end{figure}

		\item Hasil yang diinginkan adalah tabel dengan spesifikasi berikut:
		\begin{itemize}
			\item tabel background noise terhadap waktu dengan KEMAR tanpa headphone (1 tabel).
			\item tabel background noise terhadap waktu dengan KEMAR menggunakan kedua headphone, yaitu BOSE dan Miniso (2 tabel).
			\item tabel loudness output di setiap frekuensi untuk setiap kenaikan skala amplitudo, untuk 2 prototype dengan 2 headphone, masing 3 tabel per hari.
			\item tabel loudness output di setiap frekuensi untuk setiap penurunan skala amplitudo, untuk 2 prototype dengan 2 headphone, masing 3 tabel per hari.
			\item pengukuran loudness output dilakukan di 3 hari berbeda.
		\end{itemize}

		sehingga diharapkan total 75 tabel hasil pengukuran.
	\end{itemize}

	\newpage
	\section{Hasil Pengujian}

	\subsection{Tabel Hasil}

	Tabel hasil pengujian cukuk banyak yang akan memakan tempat disini sehingga disediakan tempat di repository pemrograman Lab Vibrastic pada tautan berikut:\\
	\url{https://github.com/VibrasticLab/pikoakustik/tree/stm32f401re_3pin/document/hasil_ukur_lanjutan/tabel_hasil_ukur}.\\

	Untuk kemudahan dalam pengolahan, tersedia pula tabel data tersebut dalam format Python Numpy array yang dapat diakses di tautan:\\
	\url{https://github.com/VibrasticLab/pikoakustik/blob/stm32f401re_3pin/document/hasil_ukur_lanjutan/python/itb_data_pool.py}\\

	Kemudian untuk memudahkan proses pengolahan data, digunakan pula perangkat lunak Jupyter Note yang berkasnya dapat diakses di tautan:\\
	\url{https://github.com/VibrasticLab/pikoakustik/blob/stm32f401re_3pin/document/hasil_ukur_lanjutan/python/ITBDataProcess.ipynb}\\

	\subsection{Pengolahan Data}

	Pengolahan data hasil pengujian dikelompokkan pada 3 topik, yaitu loudness, efek histeresis, dan efek perbedaan hari.

	\subsubsection{Loudness}

	Untuk pengolahan data terkait loudness, terbagi dalam dua topik, yaitu loudness terendah dan model matematis skala loudness

	\begin{itemize}
		\item \textbf{Loudness Terendah.}\\

		Berikut adalah grafik \textit{surface} pengukuran bising lingkungan:

		\begin{figure}[!ht]
			\centering
			\begin{subfigure}[b]{0.3\textwidth}
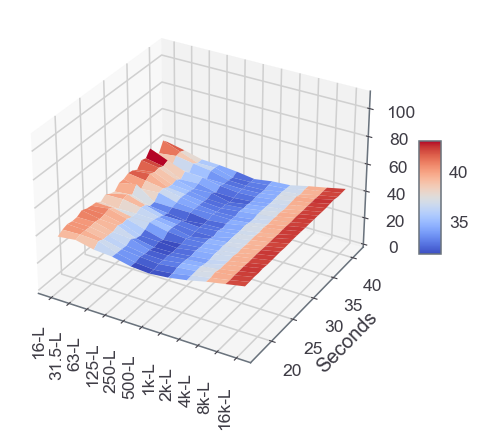
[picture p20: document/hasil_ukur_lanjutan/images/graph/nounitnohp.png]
				
				\caption{Tanpa Headphone}
			\end{subfigure}
			\begin{subfigure}[b]{0.3\textwidth}
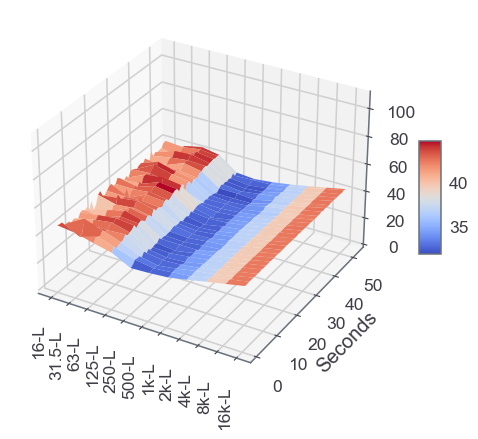
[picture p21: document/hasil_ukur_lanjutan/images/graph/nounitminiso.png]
				
				\caption{Headphone Miniso}
			\end{subfigure}
			\begin{subfigure}[b]{0.3\textwidth}
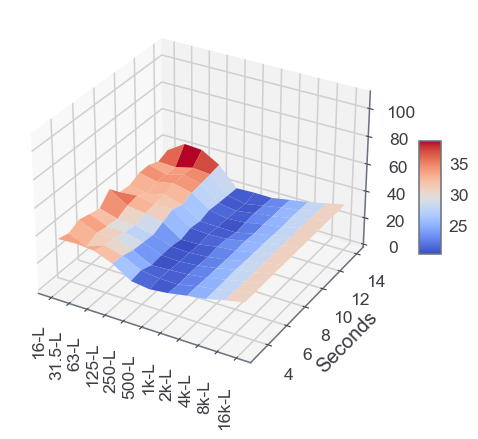
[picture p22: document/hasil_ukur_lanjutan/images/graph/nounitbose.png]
				
				\caption{Headphone BOSE}
			\end{subfigure}
			\caption{Bising Lingkungan}
		\end{figure}

		Dengan melihat skala \textit{colormap} grafik di atas terlihat bahwa headphone BOSE memiliki taraf bising paling rendah.
		Hal ini dikarenakan selain memiliki peredam bising pasif dengan struktur headphone yang melingkupi telinga secara penuh,
		juga tersedia fitur peredam bising aktif yang membatalkan bising lingkungan masuk ke mikrofon.

		\newpage
		Selanjutnya berikut adalah grafik nada terendah di setiap frekuensi dibandingkan bising lingkungan 3 detik pertama pada setiap frekuensi:

		\begin{figure}[!ht]
			\centering
			\begin{subfigure}[b]{0.5\textwidth}
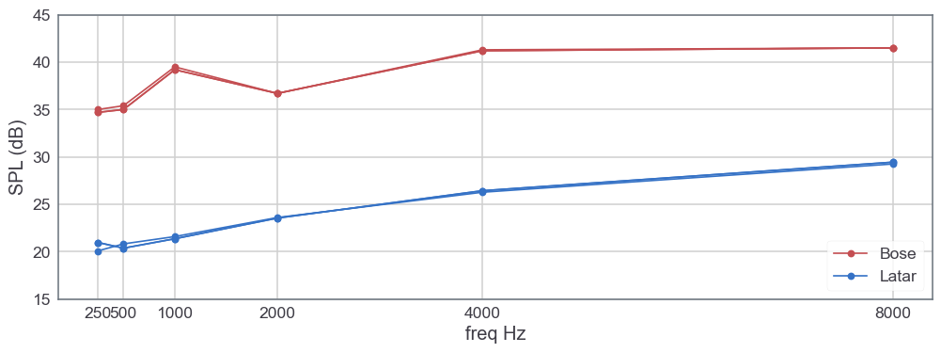
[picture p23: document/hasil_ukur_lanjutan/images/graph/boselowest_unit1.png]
				
				\caption{Prototype A}
			\end{subfigure}
			\begin{subfigure}[b]{0.5\textwidth}
				
				\caption{Prototype B}
			\end{subfigure}
			\caption{Nada terendah BOSE terhadap bising lingkungan}
		\end{figure}

		\begin{figure}[!ht]
			\centering
			\begin{subfigure}[b]{0.5\textwidth}
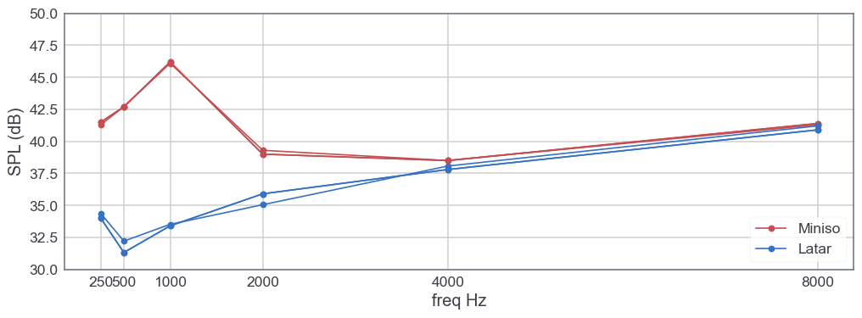
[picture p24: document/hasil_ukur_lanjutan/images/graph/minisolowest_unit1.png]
				
				\caption{Prototype A}
			\end{subfigure}
			\begin{subfigure}[b]{0.5\textwidth}
				
				\caption{Prototype B}
			\end{subfigure}
			\caption{Nada terendah Miniso terhadap bising lingkungan}
		\end{figure}

		\begin{figure}[!ht]
			\centering
			
			\caption{Nada terendah BOSE vs Miniso}
		\end{figure}

		\newpage
		Berdasarkan grafik di atas, dapat disimpulkan bahwa penggunaan headphone BOSE dianggap lebih baik
		dibandingkan Miniso dengan pertimbangan:
		\begin{enumerate}
			\item Loudness terendah BOSE cenderung lebih rendah dibandinhkan Miniso.
			\item Loudness terendah Miniso cenderung tenggelam pada bising lingkungan.
		\end{enumerate}

		Untuk selanjutnya, pengolahan data hanya difokuskan pada BOSE Headphone yang direncanakan akan
		digunakan sebagai default headphone.

		\item \textbf{Model skala loudness.}

		Dengan merata-rata seluruh matrix tabel didapat matrix untuk prototype Unit A sebagai berikut:

		\[\left[
		\begin{matrix}
			34.9 & 36.4 & 40. &  44.6 & 52. &  56.1 & 62.1 & 68.2 & 74.2\\
			35.3 & 37.4 & 41.4 & 46.6 & 52.2 & 58.2 & 64.2 & 70.3 & 76.4\\
			39.2 & 42.4 & 47. & 52.5 & 58.3 & 64.3 & 70.3 & 76.4 & 82.4\\
			36.8 & 38.2 & 41.2 & 45.8 & 51.2 & 57.2 & 63.2 & 69.3 & 75.3\\
			41.4 & 44. &  48.2 & 53.4 & 59.2 & 65.1 & 71.2 & 77.2 & 83.2\\
			42. &  43.1 & 45.9 & 50.2 & 55.7 & 61.5 & 67.5 & 73.5 & 79.6\\
		\end{matrix}
		\right]\]

		Kemudian dengan memperhatikan pola grafik tiap frekuensi (baris) pada matrix unit A:
		\begin{figure}[!ht]
			\centering
			
			\caption{Grafik loudness setiap frekuensi}
		\end{figure}

		Pendekatan model matematis untuk loudness terhadap skala input menggunakan polynomial:\\
		\[f(x) = ax^3 + bx^2 + cx + d\]

		Estimasi model menggunakan perangkat lunak Numpy Polyfit yang tersedia di Python.
		Hasil estimasi untuk prototype A pada setiap frekuensi.

		\[f_{250}(x) = -0.05x^3 + 1.03x^2 - 0.59x + 34.21\]
		\[f_{500}(x) = -0.05x^3 + 0.93x^2 + 0.09x + 34.15\]
		\[f_{1000}(x) = -0.04x^3 + 0.69x^2 + 1.72x + 36.69\]
		\[f_{2000}(x) = -0.06x^3 + 1.15x^2 - 1.58x + 37.22\]
		\[f_{4000}(x) = -0.04x^3 + 0.85x^2 + 0.68x + 39.78\]
		\[f_{8000}(x) = -0.06x^3 + 1.2x^2 - 1.99x + 42.79\]

		Model matematis ini yang akan di implementasikan ke prototype.

		\newpage
		Selanjutnya untuk prototype B, dilakukan metode perhitungan yang sama.

		Berikut matrix rata-rata loudness pengukuran:

		\[\left[
		\begin{matrix}
			34.8&36.&39.8&44.6&49.9&55.8&61.9&68.&74.&\\
			35.2&37.2&41.2&46.4&52.&58.&64.1&70.2&76.2\\
			38.9&42.1&46.8&52.2&58.&64.&70.1&76.1&82.1\\
			36.7&38.&41.&45.5&51.&56.9&63.&69.&75.1\\
			41.3&43.8&47.9&53.2&59.&64.9&70.9&77.&83.&\\
			41.8&43.&45.6&49.8&55.2&61.&67.&73.&79.&\\
		\end{matrix}
		\right]\]

		Hasil estimasi untuk prototype B pada setiap frekuensi.

		\[f_{250}(x) = -0.05x^3 + 1.08x^2 - 1x + 34.56\]
		\[f_{500}(x) = -0.05x^3 + 0.98x^2 - 0.12x + 34.21\]
		\[f_{1000}(x) = -0.04x^3 + 0.69x^2 + 1.74x + 36.38\]
		\[f_{2000}(x) = -0.06x^3 + 1.17x^2 - 1.69x + 37.21\]
		\[f_{4000}(x) = -0.04x^3 + 0.87x^2 + 0.55x + 39.77\]
		\[f_{8000}(x) = -0.06x^3 - 2.06x^2 - 1.99x + 42.73\]

		Terakhir, jika diselisih matrix koefisien didapat matrix bernilai kecil:

		\[\left[
		\begin{matrix}
			0.  & -0.05 &  0.41 & -0.35\\
			0.  & -0.05 &  0.21 & -0.06\\
			0.  &  0.   & -0.02 &  0.31\\
			0.  & -0.02 &  0.11 &  0.01\\
			0.  & -0.02 &  0.13 &  0.01\\
			0.  &  0.01 &  0.07 &  0.06\\
		\end{matrix}
		\right]\]

		dimana ini menunjukkan bahwa kedua prototype yang diuji saling identik dan saling representatif.
	\end{itemize}

	\subsubsection{Efek Histeresis}

	Selanjutnya, dengan menghitung standar deviasi di setiap elemen matrix hasil (setiap loudness dan frekuensi) sebagai array,
	didapat matriks standar deviasi di setiap unit prototype di setiap hari untuk headphone BOSE sebagai berikut:

	\begin{enumerate}
		\item Unit A. Diurut dari kiri atas, hari-1, hari-2, dan hari-3
		\[ \left( \begin{matrix}
			0.2&0.3&0.2&0.2&11.8&0.1&0.1&0.&0.1\\
			0.2&0.&0.2&0.1&0.&0.&0.&0.1&0.&\\
			0.1&0.1&0.&0.&0.&0.&0.&0.&0.&\\
			0.&0.&0.1&0.1&0.1&0.&0.&0.&0.&\\
			0.1&0.1&0.1&0.&0.&0.&0.&0.&0.&\\
			0.1&0.1&0.1&0.1&0.&0.&0.&0.&0.&\\
		\end{matrix} \right)
		%
		\left( \begin{matrix}
			0.1&0.1&0.2&0.1&0.1&0.&0.&0.&0.&\\
			0.1&0.1&0.1&0.1&0.1&0.&0.&0.&0.&\\
			0.1&0.1&0.&0.&0.&0.&0.&0.&0.&\\
			0.1&0.1&0.1&0.1&0.&0.&0.&0.&0.&\\
			0.1&0.1&0.1&0.&0.&0.&0.&0.&0.&\\
			0.1&0.1&0.1&0.1&0.&0.&0.&0.&0.&\\
		\end{matrix} \right)
		\]

		\[\left[
		\begin{matrix}
			0.1&0.2&0.2&0.1&0.2&0.&0.&0.&0.&\\
			0.2&0.1&0.1&0.1&0.1&0.1&0.&0.&0.&\\
			0.1&0.1&0.1&0.&0.&0.&0.&0.&0.&\\
			0.1&0.1&0.1&0.1&0.&0.&0.&0.&0.&\\
			0.2&0.1&0.1&0.&0.&0.&0.&0.&0.&\\
			0.1&0.&0.1&0.&0.1&0.&0.&0.&0.&\\
		\end{matrix}
		\right]\]

		\newpage
		\item Unit B, Diurut dari kiri atas, hari-1, hari-2, dan hari-3

		\[ \left( \begin{matrix}
			0.3&0.1&0.2&0.1&0.1&0.1&0.&0.&0.&\\
			0.2&0.1&0.1&0.1&0.1&0.&0.&0.1&0.&\\
			0.1&0.1&0.1&0.1&0.&0.&0.&0.&0.&\\
			0.1&0.1&0.1&0.&0.1&0.&0.&0.&0.&\\
			0.1&0.1&0.1&0.&0.&0.&0.&0.&0.&\\
			0.1&0.1&0.1&0.1&0.&0.&0.&0.&0.&\\
		\end{matrix} \right)
		%
		\left( \begin{matrix}
			0.1&0.2&0.2&0.2&0.1&0.1&0.&0.1&0.1\\
			0.2&0.1&0.1&0.1&0.1&0.&0.&0.&0.&\\
			0.1&0.1&0.1&0.1&0.&0.&0.&0.&0.&\\
			0.1&0.1&0.1&0.1&0.1&0.&1.1&0.&0.&\\
			0.1&0.1&0.1&0.1&0.&0.&0.&0.&0.&\\
			0.1&0.1&0.1&0.1&0.&0.&0.&0.&0.&\\
		\end{matrix} \right)
		\]

		\[\left[
		\begin{matrix}
			0.1&0.2&0.1&0.1&0.1&0.1&0.1&0.&0.&\\
			0.&0.4&0.2&0.2&0.&0.&0.&0.&0.&\\
			0.2&0.1&0.&0.&0.1&0.&0.&0.&0.&\\
			0.1&0.1&0.&0.1&0.&0.&0.&0.&0.&\\
			0.1&0.1&0.1&0.&0.&0.&0.&0.&0.&\\
			0.1&0.1&0.&0.&0.&0.&0.&0.&0.&\\
		\end{matrix}
		\right]\]

	\end{enumerate}

	Dengan memperhatikan matrix standar deviasi di atas, dapat terlihat bahwa output loudness cenderung konsisten
	baik terkait efek histeresis maupun perbedaan hari pengukuran.

	\newpage
	\section{Lampiran}

	\subsection{Notebook Olah Data}
	\includepdf[pages=-]{python/ITBDataProcess.pdf}

\end{document}

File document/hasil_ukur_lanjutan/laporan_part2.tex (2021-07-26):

\documentclass[12pt,]{article}
\usepackage[utf8]{inputenc}
\usepackage[T1]{fontenc}
\usepackage{mathptmx}
\usepackage{geometry}
\usepackage{mathtools}
\usepackage[english]{babel}
\usepackage{graphicx}
\usepackage{subcaption}
\usepackage{stackengine}
\usepackage[os=win]{menukeys}
\usepackage{hyperref}
\usepackage{minted}
\usepackage{xcolor}
\usepackage{tikz}
\usepackage[yyyymmdd,hhmmss]{datetime}
\usepackage{etoolbox}
\usepackage[inline]{enumitem}
\usepackage{pdfpages}

\newcommand{\WindowsLogo}{\raisebox{-0.1em}{}}
%\newcommand{\PowerLogo}{\raisebox{-0.1em}{\includegraphics[height=0.8em]{images/logo/power}}}
\newcommand{\WinKey}{\keys{\WindowsLogo}}
\newcommand{\PowerKey}{\keys{\PowerLogo}}

\patchcmd{\thebibliography}{\section*{\refname}}{}{}{}

\newcommand{\ShowOsVersion}{
	\immediate\write18{\unexpanded{foo=`uname -sro` && echo "${foo}" > tmp.tex}}
	\input{tmp}\immediate\write18{rm tmp.tex}
}

\newcommand{\ShowTexVersion}{
	\immediate\write18{\unexpanded{foo=`pdflatex -version | head -n1 | cut -d' ' -f1,2` && echo "${foo}" > tmp.tex}}
	\input{tmp}\immediate\write18{rm tmp.tex}
}

\addto\captionsenglish{\renewcommand{\contentsname}{Daftar Isi}}
\addto\captionsenglish{\renewcommand{\figurename}{Gambar}}

\hypersetup{
	colorlinks=true, %set true if you want colored links
	linktoc=all,     %set to all if you want both sections and subsections linked
	linkcolor=blue,  %choose some color if you want links to stand out
	urlcolor=blue,   %url color
}

\geometry{
	a4paper,
	left=10mm,
	right=10mm,
	top=10mm,
	bottom=15mm,
}

\title{\LARGE \bf
	Laporan Pengujian Unit Prototype Handheld Audiometri (Tahap 2)\\
}

\author{Achmadi ST MT}

\date{}

\hypersetup{citecolor=black}

\definecolor{LightGray}{gray}{0.95}

%\pagecolor[rgb]{0.1,0.1,0.1}
%\color[rgb]{1,1,1}

\begin{document}
	\thispagestyle{empty}

	\begin{titlepage}
		\centering
		\vfill
		\vfill
		\maketitle
		\vfill
		
		\vfill
		\vfill
		Update: {\today} \currenttime \\
	\end{titlepage}

	%%%%%%%%%%%%%%%%%%%%%%%%%%%%%%%%%%%%%%%%%%%%%%%%%%%%%%%%%%%%%%%%%

	\newpage
	\tableofcontents

	%%%%%%%%%%%%%%%%%%%%%%%%%%%%%%%%%%%%%%%%%%%%%%%%%%%%%%%%%%%%%%%%%

	\newpage
	\section{Pendahuluan}

	\subsection{Tujuan Pengujian}

	Tujuan Pengujian disini adalah untuk mendapatkan parameter berikut:
	\begin{enumerate}
		\item Mengetahui nilai aktual \textit{loudness} output dalam dB (SPL).
		\item Mengetahui efek histeresis terhadap konsistensi output \textit{loudness}.
	\end{enumerate}

	\subsection{Waktu dan Tempat Pengujian}

	Seluruh pengujian di lakukan di Ruang Un-Echoic Chamber Laboratorium Fisika Bangunan Teknik Fisika
	Institut Teknologi Bandung. Waktu pengujian adalah minggu terakhir di bulan Februari 2021.

	\subsection{Batasan Pengujian}

	Batasan pengujian adalah sebagai berikut:

	\begin{enumerate}
		\item Nilai frekuensi dan konsistensi frekuensi tidak diukur di ruang Unechoic chamber tersebut di atas
		karena telah diuji selama proses pengembangan dan perakitan unit prototype dan telah terbukti konsisten pada nilai yang diinginkan.

		\item Pengujian tidak dilakukan pada tubuh manusia sebenarnya melainkan menggunakan manekin yang diproduksi oleh GRASS KEMAR.
	\end{enumerate}

	%%%%%%%%%%%%%%%%%%%%%%%%%%%%%%%%%%%%%%%%%%%%%%%%%%%%%%%%%%%%%%%%%

	\newpage
	\section{Metode Pengujian}

	\subsection{Persiapan}

	Berikut adalah perangkat keras yang perlu disiapkan untuk pengujian ini:

	\begin{itemize}

		\item Unit Prototype Audiometri yang akan diuji.

		Pastikan unit prototype masih normal sebagaimana pada bab sebelumnya.

		\begin{figure}[!ht]
			\centering
			\begin{subfigure}[b]{0.3\textwidth}
				
				\caption{Unit Prototype}
			\end{subfigure}
			\begin{subfigure}[b]{0.3\textwidth}
				
				\caption{Kabel USB}
			\end{subfigure}
			\caption{Prototype}
		\end{figure}

		\item Wired-Headphone dengan impedansi tiap channel antara $32\Omega$ hingga $300\Omega$

		Headphone yang digunakan disini adalah:
		\begin{itemize}
			\item Headphone Miniso (tanpa active noise cancelling)
			\item Headphone BOSE (dilengkapi active noise cancelling)
		\end{itemize}
		\begin{figure}[!ht]
			\centering
			
			\caption{Wired Headphone}
		\end{figure}

		\newpage
		\item Kalibrasi Mikrofon pada manekin KEMAR menggunakan \textit{tone generator} yang tersedia pada paket GRASS KEMAR.
		Kemudian pasang Headphone pada manekin.
		\begin{figure}[!ht]
			\centering
			\begin{subfigure}[b]{0.3\textwidth}
				
				\caption{Kalibrasi Mikrofon}
			\end{subfigure}
			\begin{subfigure}[b]{0.3\textwidth}
				
				\caption{Headphone Terpasang}
			\end{subfigure}
			\caption{GRASS KEMAR}
		\end{figure}

	\end{itemize}

	\subsection{Audio Analyzer}

	Mikrofon GRASS KEMAR dihubungkan dengan Audio-Box dan data Audio digital dikumpulkan dengan perangkat lunak Real-Time Analyzer via USB.
	Perangkat lunak ini merupakan bagian dari paket software DSFF3 buatan Yoshimasha.

	\begin{figure}[!ht]
		\centering
		
		\caption{Tampilan Audio Analyzer}
	\end{figure}

	\newpage
	\subsection{Teknis Pengujian}

	Berikut langkah proses pengujian

	\begin{itemize}
		\item Nyalakan unit prototype dan sambungkan USB protype ke komputer.
		\begin{figure}[!ht]
			\centering
			\begin{subfigure}[b]{0.3\textwidth}
				
				\caption{Prototype Standby}
			\end{subfigure}
			\begin{subfigure}[b]{0.3\textwidth}
				
				\caption{USB Terpasang}
			\end{subfigure}
			\caption{Menyalakan Unit Prototype}
		\end{figure}

		\item Akses prototype menggunakan serial port (semisal Hercules.exe) pada komputer.
		\begin{figure}[!ht]
			\centering
			
			\caption{Contoh respon serial port}
		\end{figure}

		\item Perintah Serial untuk membangkitkan tone
		Perintah untuk membangkitkan tone dengan frekuensi dan skala yang diinginkan selama 5detik.

		Pola perintah serialnya adalah:
		\begin{minted}[frame=lines,framesep=2mm,fontsize=\small]{text}
out <frekuensi> <amplitudo>
		\end{minted}

		dengan:
		\begin{itemize}

			\item frekuensi adalah nilai frekuensi (dalam Hz) mulai 250, 500, 1000, 2000, 4000, dan 8000.

			\item amplitudo adalah skala amplitudo pada nilai 1, 2, 3, 4, 5, 6, 7, 8, dan 9.

		\end{itemize}

		Contoh untuk tone 500Hz pada skala amplitudo 6 (diakhiri (\keys{\return})):
		\begin{minted}[frame=lines,framesep=2mm,fontsize=\small]{text}
out 500 6
		\end{minted}

		\newpage
		Maka salah satu channel headphone yang terhubung prototype akan membangkitkan tone selama 5 detik.

		\begin{figure}[!ht]
			\centering
			
			\caption{Contoh Nilai Uji}
		\end{figure}

		\item Hasil yang diinginkan adalah tabel dengan spesifikasi berikut:
		\begin{itemize}
			\item tabel background noise terhadap waktu dengan KEMAR tanpa headphone (1 tabel).
			\item tabel background noise terhadap waktu dengan KEMAR menggunakan kedua headphone, yaitu BOSE dan Miniso (2 tabel).
			\item tabel loudness output di setiap frekuensi untuk setiap kenaikan skala amplitudo, untuk 2 prototype dengan 2 headphone, masing 3 tabel per hari.
			\item tabel loudness output di setiap frekuensi untuk setiap penurunan skala amplitudo, untuk 2 prototype dengan 2 headphone, masing 3 tabel per hari.
			\item pengukuran loudness output dilakukan di 3 hari berbeda.
		\end{itemize}

		sehingga diharapkan total 75 tabel hasil pengukuran.
	\end{itemize}

	\newpage
	\section{Hasil Pengujian}

	\subsection{Tabel Hasil}

	Tabel hasil pengujian cukuk banyak yang akan memakan tempat disini sehingga disediakan tempat di repository pemrograman Lab Vibrastic pada tautan berikut:\\
	\url{https://github.com/VibrasticLab/pikoakustik/tree/stm32f401re_3pin/document/hasil_ukur_lanjutan/tabel_hasil_ukur}.\\

	Untuk kemudahan dalam pengolahan, tersedia pula tabel data tersebut dalam format Python Numpy array yang dapat diakses di tautan:\\
	\url{https://github.com/VibrasticLab/pikoakustik/blob/stm32f401re_3pin/document/hasil_ukur_lanjutan/python/itb_data_pool.py}\\

	Kemudian untuk memudahkan proses pengolahan data, digunakan pula perangkat lunak Jupyter Note yang berkasnya dapat diakses di tautan:\\
	\url{https://github.com/VibrasticLab/pikoakustik/blob/stm32f401re_3pin/document/hasil_ukur_lanjutan/python/ITBDataProcess.ipynb}\\

	\subsection{Pengolahan Data}

	Pengolahan data hasil pengujian dikelompokkan pada 3 topik, yaitu loudness, efek histeresis, dan efek perbedaan hari.

	\subsubsection{Loudness}

	Untuk pengolahan data terkait loudness, terbagi dalam dua topik, yaitu loudness terendah dan model matematis skala loudness

	\begin{itemize}
		\item \textbf{Loudness Terendah.}\\

		Berikut adalah grafik \textit{surface} pengukuran bising lingkungan:

		\begin{figure}[!ht]
			\centering
			\begin{subfigure}[b]{0.3\textwidth}
				
				\caption{Tanpa Headphone}
			\end{subfigure}
			\begin{subfigure}[b]{0.3\textwidth}
				
				\caption{Headphone Miniso}
			\end{subfigure}
			\begin{subfigure}[b]{0.3\textwidth}
				
				\caption{Headphone BOSE}
			\end{subfigure}
			\caption{Bising Lingkungan}
		\end{figure}

		Dengan melihat skala \textit{colormap} grafik di atas terlihat bahwa headphone BOSE memiliki taraf bising paling rendah.
		Hal ini dikarenakan selain memiliki peredam bising pasif dengan struktur headphone yang melingkupi telinga secara penuh,
		juga tersedia fitur peredam bising aktif yang membatalkan bising lingkungan masuk ke mikrofon.

		\newpage
		Selanjutnya berikut adalah grafik nada terendah di setiap frekuensi dibandingkan bising lingkungan 3 detik pertama pada setiap frekuensi:

		\begin{figure}[!ht]
			\centering
			\begin{subfigure}[b]{0.5\textwidth}
				
				\caption{Prototype A}
			\end{subfigure}
			\begin{subfigure}[b]{0.5\textwidth}
				
				\caption{Prototype B}
			\end{subfigure}
			\caption{Nada terendah BOSE terhadap bising lingkungan}
		\end{figure}

		\begin{figure}[!ht]
			\centering
			\begin{subfigure}[b]{0.5\textwidth}
				
				\caption{Prototype A}
			\end{subfigure}
			\begin{subfigure}[b]{0.5\textwidth}
				
				\caption{Prototype B}
			\end{subfigure}
			\caption{Nada terendah Miniso terhadap bising lingkungan}
		\end{figure}

		\begin{figure}[!ht]
			\centering
			
			\caption{Nada terendah BOSE vs Miniso}
		\end{figure}

		\newpage
		Berdasarkan grafik di atas, dapat disimpulkan bahwa penggunaan headphone BOSE dianggap lebih baik
		dibandingkan Miniso dengan pertimbangan:
		\begin{enumerate}
			\item Loudness terendah BOSE cenderung lebih rendah dibandinhkan Miniso.
			\item Loudness terendah Miniso cenderung tenggelam pada bising lingkungan.
		\end{enumerate}

		Untuk selanjutnya, pengolahan data hanya difokuskan pada BOSE Headphone yang direncanakan akan
		digunakan sebagai default headphone.

		\item \textbf{Model skala loudness.}

		Dengan merata-rata seluruh matrix tabel didapat matrix untuk prototype Unit A sebagai berikut:

		\[\left[
		\begin{matrix}
			34.9 & 36.4 & 40. &  44.6 & 52. &  56.1 & 62.1 & 68.2 & 74.2\\
			35.3 & 37.4 & 41.4 & 46.6 & 52.2 & 58.2 & 64.2 & 70.3 & 76.4\\
			39.2 & 42.4 & 47. & 52.5 & 58.3 & 64.3 & 70.3 & 76.4 & 82.4\\
			36.8 & 38.2 & 41.2 & 45.8 & 51.2 & 57.2 & 63.2 & 69.3 & 75.3\\
			41.4 & 44. &  48.2 & 53.4 & 59.2 & 65.1 & 71.2 & 77.2 & 83.2\\
			42. &  43.1 & 45.9 & 50.2 & 55.7 & 61.5 & 67.5 & 73.5 & 79.6\\
		\end{matrix}
		\right]\]

		Kemudian dengan memperhatikan pola grafik tiap frekuensi (baris) pada matrix unit A:
		\begin{figure}[!ht]
			\centering
			
			\caption{Grafik loudness setiap frekuensi}
		\end{figure}

		Pendekatan model matematis untuk loudness terhadap skala input menggunakan polynomial:\\
		\[f(x) = ax^3 + bx^2 + cx + d\]

		Estimasi model menggunakan perangkat lunak Numpy Polyfit yang tersedia di Python.
		Hasil estimasi untuk prototype A pada setiap frekuensi.

		\[f_{250}(x) = -0.05x^3 + 1.03x^2 - 0.59x + 34.21\]
		\[f_{500}(x) = -0.05x^3 + 0.93x^2 + 0.09x + 34.15\]
		\[f_{1000}(x) = -0.04x^3 + 0.69x^2 + 1.72x + 36.69\]
		\[f_{2000}(x) = -0.06x^3 + 1.15x^2 - 1.58x + 37.22\]
		\[f_{4000}(x) = -0.04x^3 + 0.85x^2 + 0.68x + 39.78\]
		\[f_{8000}(x) = -0.06x^3 + 1.2x^2 - 1.99x + 42.79\]

		Model matematis ini yang akan di implementasikan ke prototype.

		\newpage
		Selanjutnya untuk prototype B, dilakukan metode perhitungan yang sama.

		Berikut matrix rata-rata loudness pengukuran:

		\[\left[
		\begin{matrix}
			34.8&36.&39.8&44.6&49.9&55.8&61.9&68.&74.&\\
			35.2&37.2&41.2&46.4&52.&58.&64.1&70.2&76.2\\
			38.9&42.1&46.8&52.2&58.&64.&70.1&76.1&82.1\\
			36.7&38.&41.&45.5&51.&56.9&63.&69.&75.1\\
			41.3&43.8&47.9&53.2&59.&64.9&70.9&77.&83.&\\
			41.8&43.&45.6&49.8&55.2&61.&67.&73.&79.&\\
		\end{matrix}
		\right]\]

		Hasil estimasi untuk prototype B pada setiap frekuensi.

		\[f_{250}(x) = -0.05x^3 + 1.08x^2 - 1x + 34.56\]
		\[f_{500}(x) = -0.05x^3 + 0.98x^2 - 0.12x + 34.21\]
		\[f_{1000}(x) = -0.04x^3 + 0.69x^2 + 1.74x + 36.38\]
		\[f_{2000}(x) = -0.06x^3 + 1.17x^2 - 1.69x + 37.21\]
		\[f_{4000}(x) = -0.04x^3 + 0.87x^2 + 0.55x + 39.77\]
		\[f_{8000}(x) = -0.06x^3 - 2.06x^2 - 1.99x + 42.73\]

		Terakhir, jika diselisih matrix koefisien didapat matrix bernilai kecil:

		\[\left[
		\begin{matrix}
			0.  & -0.05 &  0.41 & -0.35\\
			0.  & -0.05 &  0.21 & -0.06\\
			0.  &  0.   & -0.02 &  0.31\\
			0.  & -0.02 &  0.11 &  0.01\\
			0.  & -0.02 &  0.13 &  0.01\\
			0.  &  0.01 &  0.07 &  0.06\\
		\end{matrix}
		\right]\]

		dimana ini menunjukkan bahwa kedua prototype yang diuji saling identik dan saling representatif.
	\end{itemize}

	\subsubsection{Efek Histeresis}

	Selanjutnya, dengan menghitung standar deviasi di setiap elemen matrix hasil (setiap loudness dan frekuensi) sebagai array,
	didapat matriks standar deviasi di setiap unit prototype di setiap hari untuk headphone BOSE sebagai berikut:

	\begin{enumerate}
		\item Unit A. Diurut dari kiri atas, hari-1, hari-2, dan hari-3
		\[ \left( \begin{matrix}
			0.2&0.3&0.2&0.2&11.8&0.1&0.1&0.&0.1\\
			0.2&0.&0.2&0.1&0.&0.&0.&0.1&0.&\\
			0.1&0.1&0.&0.&0.&0.&0.&0.&0.&\\
			0.&0.&0.1&0.1&0.1&0.&0.&0.&0.&\\
			0.1&0.1&0.1&0.&0.&0.&0.&0.&0.&\\
			0.1&0.1&0.1&0.1&0.&0.&0.&0.&0.&\\
		\end{matrix} \right)
		%
		\left( \begin{matrix}
			0.1&0.1&0.2&0.1&0.1&0.&0.&0.&0.&\\
			0.1&0.1&0.1&0.1&0.1&0.&0.&0.&0.&\\
			0.1&0.1&0.&0.&0.&0.&0.&0.&0.&\\
			0.1&0.1&0.1&0.1&0.&0.&0.&0.&0.&\\
			0.1&0.1&0.1&0.&0.&0.&0.&0.&0.&\\
			0.1&0.1&0.1&0.1&0.&0.&0.&0.&0.&\\
		\end{matrix} \right)
		\]

		\[\left[
		\begin{matrix}
			0.1&0.2&0.2&0.1&0.2&0.&0.&0.&0.&\\
			0.2&0.1&0.1&0.1&0.1&0.1&0.&0.&0.&\\
			0.1&0.1&0.1&0.&0.&0.&0.&0.&0.&\\
			0.1&0.1&0.1&0.1&0.&0.&0.&0.&0.&\\
			0.2&0.1&0.1&0.&0.&0.&0.&0.&0.&\\
			0.1&0.&0.1&0.&0.1&0.&0.&0.&0.&\\
		\end{matrix}
		\right]\]

		\newpage
		\item Unit B, Diurut dari kiri atas, hari-1, hari-2, dan hari-3

		\[ \left( \begin{matrix}
			0.3&0.1&0.2&0.1&0.1&0.1&0.&0.&0.&\\
			0.2&0.1&0.1&0.1&0.1&0.&0.&0.1&0.&\\
			0.1&0.1&0.1&0.1&0.&0.&0.&0.&0.&\\
			0.1&0.1&0.1&0.&0.1&0.&0.&0.&0.&\\
			0.1&0.1&0.1&0.&0.&0.&0.&0.&0.&\\
			0.1&0.1&0.1&0.1&0.&0.&0.&0.&0.&\\
		\end{matrix} \right)
		%
		\left( \begin{matrix}
			0.1&0.2&0.2&0.2&0.1&0.1&0.&0.1&0.1\\
			0.2&0.1&0.1&0.1&0.1&0.&0.&0.&0.&\\
			0.1&0.1&0.1&0.1&0.&0.&0.&0.&0.&\\
			0.1&0.1&0.1&0.1&0.1&0.&1.1&0.&0.&\\
			0.1&0.1&0.1&0.1&0.&0.&0.&0.&0.&\\
			0.1&0.1&0.1&0.1&0.&0.&0.&0.&0.&\\
		\end{matrix} \right)
		\]

		\[\left[
		\begin{matrix}
			0.1&0.2&0.1&0.1&0.1&0.1&0.1&0.&0.&\\
			0.&0.4&0.2&0.2&0.&0.&0.&0.&0.&\\
			0.2&0.1&0.&0.&0.1&0.&0.&0.&0.&\\
			0.1&0.1&0.&0.1&0.&0.&0.&0.&0.&\\
			0.1&0.1&0.1&0.&0.&0.&0.&0.&0.&\\
			0.1&0.1&0.&0.&0.&0.&0.&0.&0.&\\
		\end{matrix}
		\right]\]

	\end{enumerate}

	Dengan memperhatikan matrix standar deviasi di atas, dapat terlihat bahwa output loudness cenderung konsisten
	baik terkait efek histeresis maupun perbedaan hari pengukuran.

	\newpage
	\section{Lampiran}

	\subsection{Notebook Olah Data}
	\includepdf[pages=-]{python/ITBDataProcess.pdf}

\end{document}

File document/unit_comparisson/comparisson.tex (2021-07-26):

\documentclass[12pt,a4paper,landscape]{article}
\usepackage[utf8]{inputenc}
\usepackage[T1]{fontenc}
\usepackage{mathptmx}
\usepackage{geometry}
\usepackage{mathtools}
\usepackage[english]{babel}
\usepackage{graphicx}
\usepackage{subcaption}
\usepackage{stackengine}
\usepackage[os=win]{menukeys}
\usepackage{hyperref}
\usepackage{minted}
\usepackage{xcolor}
\usepackage{tikz}
\usepackage[yyyymmdd,hhmmss]{datetime}
\usepackage{etoolbox}
\usepackage[inline]{enumitem}
\usepackage{pdfpages}
\usepackage{booktabs}

\newcommand{\WindowsLogo}{\raisebox{-0.1em}{}}
%\newcommand{\PowerLogo}{\raisebox{-0.1em}{\includegraphics[height=0.8em]{images/logo/power}}}
\newcommand{\WinKey}{\keys{\WindowsLogo}}
\newcommand{\PowerKey}{\keys{\PowerLogo}}

\patchcmd{\thebibliography}{\section*{\refname}}{}{}{}

\newcommand{\ShowOsVersion}{
	\immediate\write18{\unexpanded{foo=`uname -sro` && echo "${foo}" > tmp.tex}}
	\input{tmp}\immediate\write18{rm tmp.tex}
}

\newcommand{\ShowTexVersion}{
	\immediate\write18{\unexpanded{foo=`pdflatex -version | head -n1 | cut -d' ' -f1,2` && echo "${foo}" > tmp.tex}}
	\input{tmp}\immediate\write18{rm tmp.tex}
}

\addto\captionsenglish{\renewcommand{\contentsname}{Daftar Isi}}
\addto\captionsenglish{\renewcommand{\figurename}{Gambar}}

\geometry{
	a4paper,
	left=5mm,
	right=5mm,
	top=10mm,
	bottom=10mm,
}

\setlist{leftmargin=5mm}

\hypersetup{
	colorlinks=true, %set true if you want colored links
	linktoc=all,     %set to all if you want both sections and subsections linked
	linkcolor=blue,  %choose some color if you want links to stand out
	urlcolor=blue,   %url color
}

\title{\LARGE \bf
	Perbandingan prototype BRIN dan RISPRO\\
}

\author{Achmadi ST MT}

\date{}

\hypersetup{citecolor=black}

\definecolor{LightGray}{gray}{0.95}

%\pagecolor[rgb]{0.1,0.1,0.1}
%\color[rgb]{1,1,1}

\begin{document}
	\pagestyle{empty}
	
	\begin{titlepage}
		\centering
		\vfill
		\vfill
		\maketitle
		\vfill
		
		\vfill
		\vfill
		Update: {\today} \currenttime \\
	\end{titlepage}
	
	%%%%%%%%%%%%%%%%%%%%%%%%%%%%%%%%%%%%%%%%%%%%%%%%%%%%%%%%%%%%%%%%%
	
	\newpage
	\begin{table}[H]
		\begin{center}
			\begin{tabular}{|p{3cm}|c|p{4cm}|c|p{4cm}|}
				\toprule
				Topik & BRIN & Keterangan & RISPRO & Keterangan \\ 
				\midrule
				
				Ukuran Unit &
				\raisebox{-\totalheight}{} &
				\begin{itemize}[topsep=0pt]
					\item Cukup Besar
					\item Perlu di atas meja
					\item Dimensi: 240x140x50 mm
				\end{itemize} &
				\raisebox{-\totalheight}{} &
				\begin{itemize}[topsep=0pt]
					\item Handheld
					\item Bisa dipegang tanpa meja
					\item Dimensi: 105x85x35 mm
				\end{itemize}
				\\ \midrule
				
				\textit{System Core} &
				\raisebox{-\totalheight}{} &
				\begin{itemize}[topsep=0pt]
					\item Berbasis Raspberry-Pi
					\item Berorientasi sebagai \textit{Mini-Computer}
				\end{itemize} &
				\raisebox{-\totalheight}{} &
				\begin{itemize}[topsep=0pt]
					\item Berbasis STM32F4
					\item Berorientasi sebagai \textit{Embedded System}
				\end{itemize}
				\\ \midrule
				
				Sumber Daya &
				\raisebox{-\totalheight}{} &
				\begin{itemize}[topsep=0pt]
					\item 5v-USB Adaptor (min. 1.5A) 
					\item Tidak ada battery
					\item \textit{Core chip} Raspberry dan layar sentuh membutuhkan daya besar
				\end{itemize} &
				\raisebox{-\totalheight}{} &
				\begin{itemize}[topsep=0pt]
					\item Battery LiPO single-cell (3.7v) 
					\item Dilengkapi \textit{charging-manager} TC4056
					\item Konsumsi daya signifikan hanya chip utama STM32F4
				\end{itemize}
				\\
				
				\bottomrule
			\end{tabular}
			\end{center}
	\end{table}

	%%%%%%%%%%%%%%%%%%%%%%%%%%%%%%%%%%%%%%%%%%%%%%%%%%%%%%%%%%%%%%%%%
	
	\newpage
	\begin{table}[H]
		\begin{center}
			\begin{tabular}{|p{3cm}|c|p{4cm}|c|p{4cm}|}
				\toprule
				Topik & BRIN & Keterangan & RISPRO & Keterangan \\ 
				\midrule
				
				\textit{Operating System} &
				\raisebox{-\totalheight}{} &
				\begin{itemize}[topsep=0pt]
					\item Mengunakan Linux armhf
					\item \textit{Booting time} berkisar 2-5 menit
					\item Tidak ada \textit{checking routine}
				\end{itemize} &
				\raisebox{-\totalheight}{} &
				\begin{itemize}[topsep=0pt]
					\item Mengunakan ChibiOS/RT (Real-Time OS)
					\item Tidak ada \textit{booting-time}
					\item \textit{Checking routine} hanya 5 detik
				\end{itemize}
				\\ \midrule
				
				\textit{Default Usage} &
				\raisebox{-\totalheight}{} &
				\begin{itemize}[topsep=0pt]
					\item Membutuhkan pengaturan sebelum digunakan
					\item Tidak ada default saat program \textit{fresh-install}
				\end{itemize} &
				\raisebox{-\totalheight}{} &
				\begin{itemize}[topsep=0pt]
					\item Pengaturan sudah disiapkan internal
					\item Dapat langsung digunakan secara default
				\end{itemize}
				\\ \midrule
				
				\textit{Blueprint} &
				\raisebox{-\totalheight}{} &
				\begin{itemize}[topsep=0pt]
					\item Komponen modular buatan vendor lain
					\item Blueprint modul kembali kepada vendor RaspberryPi dan Waveshare
				\end{itemize} &
				\raisebox{-\totalheight}{} &
				\begin{itemize}[topsep=0pt]
					\item Standar file Gerber dan BoM siap dikirim ke fabrikasi elektronik
					\item Blueprint dapat direview di \href{https://github.com/VibrasticLab/pikoakustik/tree/stm32f401re_3pin/circuit/test_3rev1/fabricate_PCB}{tautan ini}.
				\end{itemize}
				\\ \midrule
				
				\bottomrule
			\end{tabular}
		\end{center}
	\end{table}
	
	\newpage
	\Large{Lampiran: Preview Blueprint Papan Elektronik}
	\begin{figure}[!ht]
		\centering
		
		\caption{Skematik Unit Prototype}
	\end{figure}
	\newpage
	\begin{figure}[!ht]
		\centering
		
		\caption{Top Wiring Layout}
	\end{figure}
	\newpage
	\begin{figure}[!ht]
		\centering
		
		\caption{Bottom Wiring Layout}
	\end{figure}
	\newpage
	\Large{Lampiran: Bill of Material Papan Elektronik}
	\begin{center}
		\resizebox{0.8\textwidth}{!}{
			\begin{tabular}{|l|l|l|l|}
				\hline
				"Id"&"Package"&"Qty"&"Value"
\\ \hline
				1&"C\_0805\_2012Metric\_Pad1.15x1.40mm\_HandSolder"&3&"220pF"\\ \hline
				2&"CP\_EIA-3216-18\_Kemet-A"&1&"4.7uF"\\ \hline
				3&"C\_0805\_2012Metric\_Pad1.15x1.40mm\_HandSolder"&5&"C"\\ \hline
				4&"LED\_1206\_3216Metric\_Pad1.42x1.75mm\_HandSolder"&7&"LED"\\ \hline
				5&"D\_SMA\_Handsoldering"&1&"D"\\ \hline
				6&"MountingHole\_2.5mm\_Pad\_Via"&4&"MountingHole"\\ \hline
				7&"MicroUSB"&1&"USB\_B\_Micro"\\ \hline
				8&"Tayda\_3.5mm\_stereo\_TRS\_jack\_A-853"&1&"AudioJack3\_Ground"\\ \hline
				9&"PinHeader\_1x06\_P2.54mm\_Vertical"&1&"Conn\_01x06\_Male"\\ \hline
				10&"PinHeader\_1x05\_P2.54mm\_Vertical"&1&"Conn\_01x05\_Male"\\ \hline
				11&"vpin-x1"&1&"Conn\_01x01\_Male"\\ \hline
				12&"vpin-x2"&1&"Conn\_01x02\_Male"\\ \hline
				13&"L\_0805\_2012Metric\_Pad1.15x1.40mm\_HandSolder"&4&"100uH"\\ \hline
				14&"R\_0805\_2012Metric\_Pad1.15x1.40mm\_HandSolder"&12&"10K"\\ \hline
				15&"R\_0805\_2012Metric\_Pad1.15x1.40mm\_HandSolder"&2&"100K"\\ \hline
				16&"R\_0805\_2012Metric\_Pad1.15x1.40mm\_HandSolder"&4&"330"\\ \hline
				17&"R\_0805\_2012Metric\_Pad1.15x1.40mm\_HandSolder"&2&"1M"\\ \hline
				18&"R\_0805\_2012Metric\_Pad1.15x1.40mm\_HandSolder"&1&"4K7"\\ \hline
				19&"R\_0805\_2012Metric\_Pad1.15x1.40mm\_HandSolder"&2&"68"\\ \hline
				20&"R\_0805\_2012Metric\_Pad1.15x1.40mm\_HandSolder"&3&"0"\\ \hline
				21&"MICRO-SD9+4P-SMD-16.1X14.5X1.85MM"&1&"MICRO-SD-CARD-SOCKET-9P\_ST-TF-003A"\\ \hline
				22&"SW\_PUSH\_6mm"&4&"SW\_Push"\\ \hline
				23&"QFN-16-1EP\_3x3mm\_P0.5mm\_EP1.7x1.7mm"&2&"MAX98357"\\ \hline
				24&"LQFP-64\_10x10mm\_P0.5mm"&1&"STM32F401RETx"\\ \hline
				25&"SOT-223-3\_TabPin2"&1&"AMS1117-3.3"\\ \hline
				26&"ESP-12E"&1&"ESP-12E"\\ \hline
				27&"sph0645"&1&"SPH0645"\\ \hline
				28&"Crystal\_HC49-4H\_Vertical"&1&"16MHz"\\ \hline
				29&"MountingHole\_2.5mm\_Pad\_Via"&1&"MountHole"\\ \hline
			\end{tabular}
}
	\end{center}
	
\end{document}

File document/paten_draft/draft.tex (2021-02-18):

\documentclass[12pt,]{article}
\usepackage[utf8]{inputenc}
\usepackage[T1]{fontenc}
\usepackage{mathptmx}
\usepackage{geometry}
\usepackage{mathtools}
\usepackage[english]{babel}
\usepackage{graphicx}
\usepackage{stackengine}
\usepackage[os=win]{menukeys}
\usepackage{hyperref}
\usepackage{minted}
\usepackage{xcolor}
\usepackage{tikz}
\usepackage[yyyymmdd,hhmmss]{datetime}
\usepackage{etoolbox}
\usepackage{enumitem}

\patchcmd{\thebibliography}{\section*{\refname}}{}{}{}

\newcommand{\ShowOsVersion}{
	\immediate\write18{\unexpanded{foo=`uname -sro` && echo "${foo}" > tmp.tex}}
	\input{tmp}\immediate\write18{rm tmp.tex}
}

\newcommand{\ShowTexVersion}{
	\immediate\write18{\unexpanded{foo=`pdflatex -version | head -n1 | cut -d' ' -f1,2` && echo "${foo}" > tmp.tex}}
	\input{tmp}\immediate\write18{rm tmp.tex}
}

\addto\captionsenglish{\renewcommand{\contentsname}{Daftar Isi}}

\hypersetup{
	colorlinks=true, %set true if you want colored links
	linktoc=all,     %set to all if you want both sections and subsections linked
	linkcolor=blue,  %choose some color if you want links to stand out
	urlcolor=blue,	 %url color
}

\geometry{
	legalpaper,
	left=15mm,
	right=10mm,
	top=10mm,
	bottom=15mm,
}

\title{\Large \bf
	Patent Claim Draft\\
}

\author{Achmadi ST MT}

\date{}

\hypersetup{citecolor=black}

\definecolor{LightGray}{gray}{0.95}

%\pagecolor[rgb]{0.1,0.1,0.1}
%\color[rgb]{1,1,1}

\begin{document}
	\thispagestyle{empty}
	
	\begin{figure}[!ht]
		\centering
		
		\caption{Layout Dasar Audiometri}
	\end{figure}

	Antarmuka utama audiometri adalah:
	\begin{enumerate}
		\item Jack Audio untuk output nada murni
		\item 3 Lampu indikator untuk 3-Force Choice
		\item 3 Tombol untuk input 3-Force Choice
		\item LED Merah indikator jawaban salah
		\item LED Hijau indikator jawaban benar
		\item LED Biru indikator mode yang sedang berjalan
	\end{enumerate}

	\noindent\makebox[\linewidth]{\rule{\paperwidth}{0.4pt}}\\

	\textbf{Poin klaim:}

	Poin utama paten adalah: Kesederhanaan (\textit{Simplicity}). 
	Simplicity disini ditandai oleh 2 poin:

	\begin{itemize}
		\item Ukuran unit yang portable dan handheld, 110mm X 85mm
		\item Antar Muka ke penggunaa yang sedikit, hanya 3 tombol dan 6 LED.			
	\end{itemize}

	\noindent\makebox[\linewidth]{\rule{\paperwidth}{0.4pt}}\\
	
	Antarmuka tombol dan LED disini memiliki 2 fungsi sekaligus:
	\begin{itemize}
		\item Untuk memulai proses Audiometri dengan urutan tombol agar proses sesi tidak dimulai tanpa disengaja
		\item Untuk proses input 3-Force Choice
	\end{itemize}

	\newpage
	Berikut penjelasan urutan memulai proses sesi Audiometri:
	
	\begin{enumerate}
		\item pastikan LED Biru (no. 6 pada gambar) berkedip sekali setiap 1 detik, sedangkan LED lain mati.
		\item Tekan salah satu tombol di grup tombol 3
		\item LED terdekat tombol akan menyala
		\item Tekan tombol lain selain tombol sebelumnya
		\item LED dekat tombol sebelumnya akan mati, sedangkan LED Hijau/Benar (no. 5 pada gambar) menyala.
		\item Tekan tombol selain dua tombol sebelumnya, maka proses Audiometri dimulai.
		\item LED Biru akan berkedip lebih cepat sebagai indikator proses sesi Audiometri sedang berlangsung	
	\end{enumerate}

	\noindent\makebox[\linewidth]{\rule{\paperwidth}{0.4pt}}\\

	Berikut adalah urutan langkah interaksi 3-Force Choice saat proses Audiometri.
	\begin{enumerate}
		\item Pastikan poin berikut telah siap. Jika belum maka reset kembali unit
		dan ulangi kembali langkah startup.
		\begin{enumerate}
			\renewcommand{\theenumi}{\Alph{enumi}}
			
			\item LED Indikator pada posisi 6 berkedip cepat.
			\item Headphone telah terpasang.
		\end{enumerate}
		
		\item \textbf{Perhatikan} output dari unit.
		\begin{enumerate}
			\renewcommand{\theenumi}{\Alph{enumi}}
			
			\item LED pada baris no.2 akan berkedip sekali bergantian
			\item Nada murni pada output no. 1 akan terdengar,
			bersamaan salah satu LED baris no. 2.
		\end{enumerate}
		
		\item Tekan satu tombol pada baris no.3 dimana LED baris 2 menyala bersamaan dengan terdengar nada murni.
		
		\item LED no. 4 akan menyala satu detik sebagai respon jawaban salah.

		\item LED no. 5 akan menyala satu detik sebagai respon jawaban benar.
		
		\item Lanjutkan hingga LED Mode pada nomor 6 kembali berkedip lambat satu kali setiap satu detik, yang menandakan sesi uji Audiometri selesai.
	\end{enumerate}
	
\end{document}

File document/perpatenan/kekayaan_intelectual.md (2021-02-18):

## Audiometri STM32 (RISPRO)

### Sirkuit Terpadu (DTLST)
- [ ] Simpaki sudah dipahami
- [x] Blueprint PCB siap

---------------------------------------------------------

### Paten

#### Layak Paten
- Serial Commands:
	- Audio Speaker Test. [Source](https://github.com/VibrasticLab/pikoakustik/blob/stm32f401re_3pin/firmware/ht_comm.c#L58-L105)
	- Audio Tone Test. [Source](https://github.com/VibrasticLab/pikoakustik/blob/stm32f401re_3pin/firmware/ht_comm.c#L243-L323)
- Usage:
	- Start Up Sequence Button
	- Three-Force Choice Input method
- Filesystem:
	- MMC Readyness Indicator

---------------------------------------------------------

#### Common Design, Ambigu, atau Kurang Layak
- Audio methods:
	- Konstanta Persamaan Tone. [Source](https://github.com/VibrasticLab/pikoakustik/blob/stm32f401re_3pin/firmware/ht_audio.c#L78-L109)
	- Algoritma Tone Generation. [Source](https://github.com/VibrasticLab/pikoakustik/blob/stm32f401re_3pin/firmware/ht_audio.c#L111-L124)
	- L/R Control. [Source](https://github.com/VibrasticLab/pikoakustik/blob/stm32f401re_3pin/firmware/ht_audio.c#L131-L139)
- Serial Commands:
	- Audio Zero. [Source](https://github.com/VibrasticLab/pikoakustik/blob/stm32f401re_3pin/firmware/ht_comm.c#L113-L134)
	- Audio Max. [Source](https://github.com/VibrasticLab/pikoakustik/blob/stm32f401re_3pin/firmware/ht_audio.c#L140-L161)
	- MMC List. [Source](https://github.com/VibrasticLab/pikoakustik/blob/stm32f401re_3pin/firmware/ht_audio.c#L402-L407)
	- MMC Show Files. [Source](https://github.com/VibrasticLab/pikoakustik/blob/stm32f401re_3pin/firmware/ht_audio.c#L413-L420)
	- MMC Show Contents. [Source](https://github.com/VibrasticLab/pikoakustik/blob/stm32f401re_3pin/firmware/ht_audio.c#L413-L420)
	- MMC Check MMC. [Source](https://github.com/VibrasticLab/pikoakustik/blob/stm32f401re_3pin/firmware/ht_audio.c#L450-L456)
	- IoT MQTT Subscribe. [Source](https://github.com/VibrasticLab/pikoakustik/blob/stm32f401re_3pin/firmware/ht_audio.c#L464-L570)
	- IoT MQTT Publish. [Source](https://github.com/VibrasticLab/pikoakustik/blob/stm32f401re_3pin/firmware/ht_audio.c#L476-L482)
	- IoT HTTP JSON Send. [Source](https://github.com/VibrasticLab/pikoakustik/blob/stm32f401re_3pin/firmware/ht_audio.c#L488-L495)
	- IoT MQTT Send Log. [Source](https://github.com/VibrasticLab/pikoakustik/blob/stm32f401re_3pin/firmware/ht_audio.c#L501-L512)
- Filesystem:
	- MMC Saving
	- String Parser
- Wifi:
	- Mode Switching
	- MQTT Transfer
	- MQTT JSON Data
	- HTTP JSON Data
- Handheld:
	- Handpalm size
	- Battery Operated Device

##

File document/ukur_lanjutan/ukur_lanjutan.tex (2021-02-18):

\documentclass[12pt,]{article}
\usepackage[utf8]{inputenc}
\usepackage[T1]{fontenc}
\usepackage{mathptmx}
\usepackage{geometry}
\usepackage{mathtools}
\usepackage[english]{babel}
\usepackage{graphicx}
\usepackage{stackengine}
\usepackage[os=win]{menukeys}
\usepackage{hyperref}
\usepackage{minted}
\usepackage{xcolor}
\usepackage{tikz}
\usepackage[yyyymmdd,hhmmss]{datetime}
\usepackage{etoolbox}
\usepackage[inline]{enumitem}

\newcommand{\WindowsLogo}{\raisebox{-0.1em}{}}
%\newcommand{\PowerLogo}{\raisebox{-0.1em}{\includegraphics[height=0.8em]{images/logo/power}}}
\newcommand{\WinKey}{\keys{\WindowsLogo}}       
\newcommand{\PowerKey}{\keys{\PowerLogo}}       

\patchcmd{\thebibliography}{\section*{\refname}}{}{}{}

\newcommand{\ShowOsVersion}{
        \immediate\write18{\unexpanded{foo=`uname -sro` && echo "${foo}" > tmp.tex}}
        \input{tmp}\immediate\write18{rm tmp.tex}
}

\newcommand{\ShowTexVersion}{
        \immediate\write18{\unexpanded{foo=`pdflatex -version | head -n1 | cut -d' ' -f1,2` && echo "${foo}" > tmp.tex}}
        \input{tmp}\immediate\write18{rm tmp.tex}
}

\addto\captionsenglish{\renewcommand{\contentsname}{Daftar Isi}}
\addto\captionsenglish{\renewcommand{\figurename}{Gambar}}

\hypersetup{
        colorlinks=true, %set true if you want colored links
        linktoc=all,     %set to all if you want both sections and subsections linked
        linkcolor=blue,  %choose some color if you want links to stand out
        urlcolor=blue,   %url color
}

\geometry{
        a4paper,
        left=15mm,
        right=10mm,
        top=10mm,
        bottom=15mm,
}

\title{\LARGE \bf
        Panduan Pengujian Lanjutan\\
        \small{(Handheld Audiometri Prototype)}
}

\author{Achmadi ST MT}

\date{}

\hypersetup{citecolor=black}

\definecolor{LightGray}{gray}{0.95}

%\pagecolor[rgb]{0.1,0.1,0.1}
%\color[rgb]{1,1,1}

\begin{document}
	\thispagestyle{empty}
	
	\begin{titlepage}
		\centering
		\vfill
		\vfill
		\maketitle
		\vfill
		
		\vfill
		\vfill
		Update: {\today} \currenttime \\
	\end{titlepage}
	
	%%%%%%%%%%%%%%%%%%%%%%%%%%%%%%%%%%%%%%%%%%%%%%%%%%%%%%%%%%%%%%%%%
	
	\newpage
	\tableofcontents
	
	%%%%%%%%%%%%%%%%%%%%%%%%%%%%%%%%%%%%%%%%%%%%%%%%%%%%%%%%%%%%%%%%%
	
	\newpage
	\section{Pendahuluan}
	
	\subsection{Hasil Sebelumnya}
	
	Berikut ditampilkan rangkuman dari hasil pengukuran sebelumnya:
	
	\subsubsection{Headphone BOSE}
	
	Berikut tabel nilai (dalam dB-SPL) dan respon Sine-Sweep.
	Nilai didapat dari pengukuran berulang dengan diambil nilai paling sering muncul.
	
	Hasil dari Prototype Box-1 (dB-SPL):
	
	\begin{center}
		\begin{tabular}{|l|l|l|l|l|l|l|l|l|l|}
			\hline
			\textbf{Fq/Amp}  & \textbf{9} & \textbf{8} & \textbf{7} & \textbf{6} & \textbf{5} & \textbf{4} & \textbf{3} & \textbf{2} & \textbf{1} \\ \hline
			\textbf{250 Hz}  & 75.0       & 68.9       & 62.8       & 56.8       & 50.7       & 45.1       & 40.2       & 35.4       & 32.5       \\ \hline
			\textbf{500 Hz}  & 74.5       & 68.4       & 62.4       & 56.3       & 50.3       & 44.5       & 39.4       & 35.1       & 31.5       \\ \hline
			\textbf{1000 Hz} & 81.2       & 75.2       & 69.2       & 63.1       & 57.1       & 51.2       & 45.5       & 40.8       & 37.2       \\ \hline
			\textbf{2000 Hz} & 78.0       & 71.9       & 65.9       & 59.8       & 53.8       & 48.2       & 42.7       & 38.2       & 35.2       \\ \hline
			\textbf{4000 Hz} & 82.9       & 76.9       & 70.9       & 64.8       & 58.8       & 53.0       & 47.8       & 43.8       & 41.0       \\ \hline
			\textbf{8000 Hz} & 79.1       & 73.0       & 67.0       & 60.9       & 55.2       & 49.6       & 45.4       & 42.8       & 42.0       \\ \hline
		\end{tabular}
	\end{center}

	Hasil dari Prototype Box-2 (dB-SPL):
	
	\begin{center}
		\begin{tabular}{|l|l|l|l|l|l|l|l|l|l|}
			\hline
			\textbf{Fq/Amp}  & \textbf{9} & \textbf{8} & \textbf{7} & \textbf{6} & \textbf{5} & \textbf{4} & \textbf{3} & \textbf{2} & \textbf{1} \\ \hline
			\textbf{250 Hz}  & 76.1       & 70.1       & 64.1       & 58.0       & 52.1       & 46.3       & 41.2       & 37.6       & 36.2       \\ \hline
			\textbf{500 Hz}  & 75.1       & 69.1       & 63.0       & 56.9       & 50.1       & 45.3       & 41.0       & 36.5       & 33.6       \\ \hline
			\textbf{1000 Hz} & 80.8       & 74.8       & 68.8       & 62.7       & 56.6       & 50.8       & 45.5       & 41.1       & 38.1       \\ \hline
			\textbf{2000 Hz} & 76.9       & 70.8       & 64.8       & 58.7       & 52.7       & 47.1       & 42.2       & 39.0       & 37.4       \\ \hline
			\textbf{4000 Hz} & 83.2       & 77.2       & 71.2       & 65.1       & 59.2       & 53.4       & 48.1       & 43.9       & 41.2       \\ \hline
			\textbf{8000 Hz} & 77.4       & 71.5       & 65.4       & 59.4       & 53.7       & 48.5       & 44.4       & 42.3       & 41.5       \\ \hline
		\end{tabular}
	\end{center}

	Respon Sine-Sweep:
	
	\begin{figure}[!ht]
		\centering
		
		\caption{Respon Sine-Sweep BOSE}
	\end{figure}

	\newpage
	\subsubsection{Headphone Miniso}
	
	Berikut tabel nilai (dalam dB-SPL) dan respon Sine-Sweep.
	Nilai didapat dari pengukuran berulang dengan diambil nilai paling sering muncul.
	
	Hasil dari Prototype Box-1 (dB-SPL):
	
	\begin{center}
		\begin{tabular}{|l|l|l|l|l|l|l|l|l|l|}
			\hline
			\textbf{Fq/Amp}  & \textbf{9} & \textbf{8} & \textbf{7} & \textbf{6} & \textbf{5} & \textbf{4} & \textbf{3} & \textbf{2} & \textbf{1} \\ \hline
			\textbf{250 Hz}  & 73.7       & 67.7       & 61.7       & 55.7       & 49.9       & 44.1       & 38.7       & 33.7       & 30.5       \\ \hline
			\textbf{500 Hz}  & 74.8       & 68.8       & 62.9       & 56.9       & 51.0       & 45.2       & 39.8       & 34.9       & 31.1       \\ \hline
			\textbf{1000 Hz} & 78.0       & 72.0       & 66.0       & 60.1       & 54.2       & 48.4       & 43.0       & 38.0       & 34.3       \\ \hline
			\textbf{2000 Hz} & 68.7       & 62.6       & 56.7       & 50.7       & 44.9       & 39.1       & 34.0       & 29.9       & 27.2       \\ \hline
			\textbf{4000 Hz} & 62.2       & 56.2       & 50.2       & 44.3       & 38.7       & 33.6       & 29.6       & 27.7       & 27.0       \\ \hline
			\textbf{8000 Hz} & 65.0       & 59.0       & 53.0       & 47.2       & 41.5       & 36.3       & 32.7       & 30.4       & 29.6       \\ \hline
		\end{tabular}
	\end{center}
	
	Hasil dari Prototype Box-2 (dB-SPL):
	
	\begin{center}
		\begin{tabular}{|l|l|l|l|l|l|l|l|l|l|}
			\hline
			\textbf{Fq/Amp}  & \textbf{9} & \textbf{8} & \textbf{7} & \textbf{6} & \textbf{5} & \textbf{4} & \textbf{3} & \textbf{2} & \textbf{1} \\ \hline
			\textbf{250 Hz}  & 85.2       & 79.2       & 73.2       & 67.2       & 61.2       & 55.3       & 49.7       & 45.3       & 41.6       \\ \hline
			\textbf{500 Hz}  & 86.4       & 80.4       & 74.4       & 68.4       & 62.4       & 56.5       & 51.1       & 46.1       & 42.3       \\ \hline
			\textbf{1000 Hz} & 89.7       & 83.7       & 77.7       & 71.7       & 65.8       & 59.9       & 54.3       & 49.3       & 45.5       \\ \hline
			\textbf{2000 Hz} & 80.1       & 74.0       & 68.0       & 62.0       & 56.0       & 50.2       & 45.1       & 41.0       & 38.7       \\ \hline
			\textbf{4000 Hz} & 73.7       & 67.7       & 61.7       & 55.7       & 49.9       & 44.8       & 41.0       & 39.0       & 38.4       \\ \hline
			\textbf{8000 Hz} & 76.0       & 70.1       & 64.1       & 58.1       & 52.4       & 47.3       & 43.9       & 42.0       & 41.5       \\ \hline
		\end{tabular}
	\end{center}
	
	Respon Sine-Sweep:
	
	\begin{figure}[!ht]
		\centering
		
		\caption{Respon Sine-Sweep Miniso}
	\end{figure}

	\newpage
	\subsection{Pengukuran Lanjutan}
	Sebagai salah satu poin penting dalam pengembangan prototype adalah konsistensi unit.
	Pengukuran lanjutan ini dimaksudkan untuk menguji konsistensi prototype saat menghasilkan nada murni:
	Ketidak-konsistensi yang dapat timbul antara lain:
	\begin{itemize}
		\item Pemasangan Headphone yang berubah.
		\item Daya baterai yang berubah sehingga suplay arus berubah.
		\item Efek histeresis pada komponen semisal induktor filter output atau impedansi headphone.
	\end{itemize}

	\newpage
	\section{Pengecekan}
	
	\subsection{PENTING}
	
	Sebelum melanjutkan pengukuran, diperlukan pengecekan kondisi unit prototype,
	mengingat prototype merupakan \textit{hand-made} yang belum reliable untuk ditinggalkan dalam
	kondisi tanpa pengawasan dalam jangka waktu lama.
	
	Beberapa poin yang perlu dilakukan pengecekan unit:
	\begin{itemize}
		\item Unit masih bisa menyala.
		\item Unit tidak mengeluarkan asap saat dinyalakan.
		\item LED biru sebagai indikator masih menyala dan berkedip.
		\item Pasang Headphone, kemudian matikan dan nyalakan kembali unit. Sesaat setelah menyala
		akan dihasilkan nada murni 500Hz sebanyak dua kali bergantian kanan dan kiri.
	\end{itemize}
	
	Jika muncul kegagalan (\textit{failure}) dari salah satu poin di atas maka pengukuran tidak bisa dilakukan
	dan unit prototype harus kembali (\textit{return to base}).
	
	\newpage
	\section{Panduan}
	
	Berikut adalah panduan ringkas pengukuran.
	Panduan ini pada dasarnya sama dengan dokumen panduan sebelumnya namun tanpa \textit{charging} dan beberapa tambahan terkait pengukuran lanjutan.
	
	\subsection{Persiapan}
	
	\subsubsection{Hardware}
	
	Berikut adalah perangkat keras yang perlu disiapkan untuk pengujian ini:
	\begin{enumerate}
		\item Unit Prototype Audiometri yang akan diuji.
		Pastikan unit prototype masih normal sebagaimana pada bab sebelumnya.
		\begin{figure}[!ht]
			\centering
			
			\caption{Unit Prototype}
		\end{figure}
		
		\item Kabel Micro-USB ke USB-A.
		\begin{figure}[!ht]
			\centering
			
			\caption{Kabel USB}
		\end{figure}
		
		\item Wired-Headphone dengan impedansi tiap channel antara $32\Omega$ hingga $300\Omega$
		\begin{figure}[!ht]
			\centering
			
			\caption{Wired Headphone}
		\end{figure}
		
		\newpage
		\item Setup Uji KEMAR dan telah terkalibrasi.\\
		\textbf{Catatan}: Diasumsikan bahwa operator telah cukup familiar dalam detil teknis persiapan
		maupun penggunaan unit uji KEMAR.
		\begin{figure}[!ht]
			\centering
			
			\caption{Setup Kemar}
		\end{figure}
		
	\end{enumerate}
	
	\subsubsection{Software: Windows}
	
	Berikut adalah perangkat lunak yang perlu disiapkan untuk pengujian ini
	(panduan ini menggunakan Windows-7 32-bit sebagai contoh):
	
	\begin{enumerate}
		\item Install driver ARM USB-CDC.\\
		Untuk dapat menghubungkan unit prototype dengan komputer,
		diperlukan driver ARM USB-CDC untuk komunikasi serial.
		
		\begin{itemize}
			\item File installer (sesuaikan dengan bit OS).
			Dapat didownload di \url{http://intip.in/stm32tools}
			\begin{figure}[!ht]
				\centering
				
				\caption{Installer Driver}
			\end{figure}
			
			\item Instalasi driver (tanpa unit prototype terhubung) cukup mudah sebagaimana umumnya.
			\begin{figure}[!ht]
				\centering
				
				\caption{Mulai instal driver}
			\end{figure}
		\end{itemize}
		
		\newpage
		\item Nyalakan dan hubungkan unit ke komputer.\\
		
		Berikut langkah-langkahnya:
		\begin{itemize}
			\item Hidupkan dengan switch pada sisi samping casing.
			\begin{figure}[!ht]
				\centering
				
				\caption{Power Switch}
			\end{figure}
			
			\item Tunggu hingga LED biru, hijau, dan merah menyala
			bergantian sebagai tanda unit sudah standby
			
			\begin{figure}[!ht]
				\centering
				
				\caption{Unit Standby}
			\end{figure}
			
			\item Sambungkan unit prototype dengan komputer via kabel USB.
			
			\begin{figure}[!ht]
				\centering
				
				\caption{Konek Kabel USB}
			\end{figure}
			
		\end{itemize}
		
		\newpage
		\item Tunggu hingga driver selesai mengkonfigurasi otomatis
		
		\item Cek \textit{Device Manager} untuk mengetahui Nomor Serial-Port
		\begin{itemize}
			\item Buka run-command dialog dengan kombinasi keyboard (\keys{\WinKey + r})
			
			\item masukkan perintah \textbf{devmgmt.msc}.
			\begin{figure}[!ht]
				\centering
				
				\caption{Memanggil Device Manager}
			\end{figure}
			
			\item Tekan (\keys{\return}) atau klik OK
			
			\item Cari entry \textit{Ports (COM and LPT)}.
			Catat nomor port untuk entry \textit{STMicroelectronics Virtual COM Port}.
			Dalam contoh ini, terkonfigurasi pada COM3.
			
			\begin{figure}[!ht]
				\centering
				
				\caption{Serial Komunikasi pada COM3}
			\end{figure}
		\end{itemize}
		
		\item Install Serial Terminal.
		Untuk dapat berkomunikasi via serial port, perlu diinstall serial terminal.
		Disini dicontohkan menggunakan \textit{Hercules}.
		
		\begin{itemize}
			\item Program terminal Hercules. Dapat didownload di \url{http://intip.in/stm32tools}
			\begin{figure}[!ht]
				\centering
				
				\caption{Hercules Terminal}
			\end{figure}
			
			\item Jalankan program Hercules.
			Jika muncul konfirmasi lisensi, cukup \textit{Close} saja.
			
			\item Pilih tab \textit{Serial}.
			\begin{figure}[!ht]
				\centering
				
				\caption{Serial Terminal}
			\end{figure}
			
		\end{itemize}
		
		\newpage
		\item Test Komunikasi Serial
		\begin{itemize}
			\item Hercules Serial Terminal
			\begin{figure}[!ht]
				\centering
				
				\caption{Hercules Serial Terminal}
			\end{figure}
			
			\item Setting Port pada Serial Terminal sebagai berikut
			\begin{itemize}
				\item Name     : COM3
				\item Baud     : 9600
				\item Data size: 8
				\item Parity   : none
			\end{itemize}
			
			\begin{figure}[!ht]
				\centering
				
				\caption{Pengaturan serial port}
			\end{figure}
			
			\item Klik Open (pastikan unit prototype sudah standby dan terhubung
			serta nama COM port sudah sesuai)
			
			\begin{figure}[!ht]
				\centering
				
				\caption{Open Serial Port}
			\end{figure}
			
			\item Kolom terminal akan menampilkan pesan:
			\begin{minted}[frame=lines,framesep=2mm,fontsize=\small]{text}
			Serial port COM3 opened
			\end{minted}
			
			\newpage
			\item Selanjutnya, pada kolom terminal,
			masukkan perintah berikut dan diakhiri dengan (\keys{\return})
			\begin{minted}[frame=lines,framesep=2mm,fontsize=\small]{text}
			info
			\end{minted}
			Serial akan menampilkan informasi kernel dan platform
			\begin{figure}[!ht]
				\centering
				
				\caption{Informasi Platform}
			\end{figure}
		\end{itemize}
	\end{enumerate}
	
	\subsubsection{Audio Analyzer}
	
	Untuk perangkat lunak Audio Analyzer, digunakan program \textit{Real-Time Analyzer}
	yang merupakan bagian dari paket software DSFF3 buatan Yoshimasha.
	Jika membutuhkan versi trial dapat didownload di \url{http://intip.in/stm32tools}.
	
	Antar-muka Real-Time Analyzer yang digunakan adalah \textit{FFT-Analyzer} pada tab \textit{Octave band}.
	
	\begin{figure}[!ht]
		\centering
		
		\caption{Octave band pada FFT analyzer}
	\end{figure}
	
	Pada tampilan Octave-Band, klik satu bar frekuensi untuk mengetahui nilai SPL (dB)
	yang terisolasi dengan frekuensi lain.
	
	\newpage
	\subsubsection{Test Tone-Generation}
	Berikut adalah prosedur untuk mencoba \textit{tone-generation}:
	\begin{enumerate}
		\item Nyalakan unit prototype dan tunggu standby.
		Pastikan USB belum terhubung ke komputer.
		\item Sambungkan unit dengan headphone yang disiapkan
		\item Sambungkan USB ke komputer
		\item Cek nomor COM port pada Device manager
		\item Jalankan Hercules terminal
		\item Atur nama port sesuai COM port
		\item Klik \textbf{Open} pada Hercules terminal
		\item Masukkan perintah berikut:
		\begin{minted}[frame=lines,framesep=2mm,fontsize=\small]{text}
out 500 5
		\end{minted}
		\item Setelah tekan (\keys{\return}), maka pada salah satu headphone
		akan membangkitkan tone selama kurang lebih 5detik.
		\item Jika setelah selesai, tekan \textbf{Close} pada terminal,
		lepas USB, dan matikan unit prototype.
		
	\end{enumerate}
	
	\subsubsection{Perintah yang Tersedia}
	
	Berikut beberapa perintah yang dapat diinputkan ke unit prototype:
	
	\begin{itemize}
		\item \textbf{test}.
		Perintah ini untuk mencoba headphone dengan mengeluakan tone singkat kanan-kiri bergantian.
		Perintahnya adalah (diakhiri (\keys{\return})):
		\begin{minted}[frame=lines,framesep=2mm,fontsize=\small]{text}
test
		\end{minted}
		
		\item \textbf{info}.
		Perintah ini untuk menampilkan informasi platform.
		Dapat digunakan sebagai perintah uji untuk melihat serial dan chip sudah berkerja atau tidak.
		Perintahnya adalah (diakhiri (\keys{\return})):
		\begin{minted}[frame=lines,framesep=2mm,fontsize=\small]{text}
info
		\end{minted}
		
		\item \textbf{out}.
		Perintah untuk membangkitkan tone dengan frekuensi dan skala yang diinginkan selama 5detik.
		Perintah adalah perintah utama dalam proses pengujian ini.
		Pola perintahnya adalah (diakhiri (\keys{\return})):
		\begin{minted}[frame=lines,framesep=2mm,fontsize=\small]{text}
out <frekuensi> <amplitudo>
		\end{minted}
		dengan:
		\begin{itemize}
			\item frekuensi adalah nilai frekuensi (dalam Hz) antara 250 sampai 8000.
			\item amplitudo adalah skala amplitudo antara 1 sampai 9
		\end{itemize}
		Contoh untuk tone 500Hz pada skala amplitudo 6 (diakhiri (\keys{\return})):
		\begin{minted}[frame=lines,framesep=2mm,fontsize=\small]{text}
out 500 6
		\end{minted}
	\end{itemize}
	
	\newpage
	\subsubsection{Troubleshoot}
	
	Berikut beberapa masalah yang terkadang sering muncul:
	\begin{enumerate}
		\item Perintah serial tidak merespon apapun kecuali hanya menampilkan prompt seperti:
		\begin{minted}[frame=lines,framesep=2mm,fontsize=\small]{text}
ch>
		\end{minted}
		Ini bukanlah masalah melainkan hanya respon saat baru selesai startup.
		Solusinya cukup masukkan perintah yang diinginkan sekali lagi.
		
		\item Serial USB tidak terdaftar pada \textit{Device-Manager}.\\
		Kemungkinan sumber masalah:
		\begin{itemize}
			\item Kabel USB tidak tersambung baik atau tidak menyediakan jalur data D+/D-.\\
			\textbf{Solusi}: ganti kabel USB
			
			\item Kabel USB terhubung ke komputer sebelum unit nyala dan standby.\\
			\textbf{Solusi}: lepas kabel USB dari komputer kemudian matikan dan nyalakan ulang unit.
			Setelah standby maka baru disambungkan ke komputer.
		\end{itemize}
		
		\item Unit prototype frezze atau hank.\\
		Ditandai dengan LED yang tidak lagi berkedip bergantian atau perintah serial tidak lagi merespon.\\
		Kemungkinan sumber masalah adalah kondisi \textit{race} pada threading dan interrupt.\\
		\textbf{Solusi}: lepas kabel USB dari komputer kemudian matikan dan nyalakan ulang unit.
		Setelah standby maka baru disambungkan ke komputer.
	\end{enumerate}
	
	\newpage
	\subsection{Pengujian}
	
	\subsubsection{Hasil}
	
	Hasil yang diharapkan adalah tabel SPL (dB) untuk setiap matrik frekuensi dan skala amplitudo.
	Dengan hasil tabel ini maka diharapkan ada acuan untuk pengaturan unit prototype sesuai standar yang digunakan pada nantinya.
	
	Berikut contoh tabel yang diharapkan:
	
	\begin{center}
		\begin{tabular}{|c|c|c|c|c|c|c|c|c|c|}
			\hline
			Fq/Ap & 9 & 8 & 7 & 6 & 5 & 4 & 3 & 2 & 1\\ [0.5ex]
			\hline\hline
			250Hz & X dB & X dB & X dB & X dB & X dB & X dB & X dB & X dB & X dB\\
			\hline
			500Hz & X dB & X dB & X dB & X dB & X dB & X dB & X dB & X dB & X dB\\
			\hline
			1000Hz & X dB & X dB & X dB & X dB & X dB & X dB & X dB & X dB & X dB\\
			\hline
			2000Hz & X dB & X dB & X dB & X dB & X dB & X dB & X dB & X dB & X dB\\
			\hline
			4000Hz & X dB & X dB & X dB & X dB & X dB & X dB & X dB & X dB & X dB\\
			\hline
			8000Hz & X dB & X dB & X dB & X dB & X dB & X dB & X dB & X dB & X dB\\
			\hline
		\end{tabular}
	\end{center}
	
	Tabel dalam format Excel 2003 (xls) dapat didownload di \url{https://intip.in/UjiAudiometri}.
	
	\subsubsection{Perintah Serial}
	
	Perintah serial yang digunakan sebagaimana telah dijelaskan pada bab sebelumnya adalah perintah \textbf{out},
	dengan pola perintah:
	\begin{minted}[frame=lines,framesep=2mm,fontsize=\small]{text}
out <frekuensi> <amplitudo>
	\end{minted}
	dengan:
	\begin{itemize}
		\item frekuensi adalah nilai frekuensi (dalam Hz) mulai 250, 500, 1000, 2000, 4000, dan 8000.
		\item amplitudo adalah skala amplitudo pada nilai 1, 2, 3, 4, 5, 6, 7, 8, dan 9.
	\end{itemize}
	
	\newpage
	\subsubsection{Contoh Prosedur}
	
	Berikut adalah contoh prosedur untuk satu nilai uji pada satu frekuensi dan satu skala amplitudo.
	Sebagai contoh disini pada frekuensi 1000Hz pada skala amplitudo 6.
	Sebelum pengujian, kembali cek ulang persiapan meliputi:
	\begin{itemize}
		\item Nyalakan unit prototype. Pastikan LED biru menyala dan berkedip.
		\item Unit prototype telah standby dan terhubung laptop via USB.
		\item Serial terminal telah bisa mengirim perintah dan mendapat respon.
		\item Headphone telah terpasang ke unit uji KEMAR dan terhubung unit prototype.
		\item Komputer dan unit KEMAR sudah terhubung dengan Audio Capture Device.
		\item Real-Time Analyzer pada window FFT Octave-band telah terkalibrasi dan sudah start.
	\end{itemize}
	
	Berikut contoh prosedur satu nilai:
	\begin{enumerate}
		\item masukkan perintah tone untuk nilai frekuensi dan skala amplitudo yang ditentukan.
		Contoh (1000Hz skala 6):
		\begin{minted}[frame=lines,framesep=2mm,fontsize=\small]{text}
out 1000 6
		\end{minted}
		
		\item Tone akan dibangkitkan selama 5detik.
		
		\item Pada window Octave-band, klik bar pada frekuensi 1000Hz.
		
		\begin{figure}[!ht]
			\centering
			
			\caption{Contoh Nilai Uji}
		\end{figure}
		
		Terlihat bahwa nilai hasil uji adalah 49.95 dB (atau 50dB).\\
		\textbf{Catatan}: Contoh gambar di atas dilakukan pada ruangan biasa dengan penuh gangguan.
		
		\item Catat nilai SPL tersebut pada tabel Hasil sesuai frekuensi dan skala amplitudo
		
		\item Setelah 5detik, tone akan berhenti.
		
		\item Pengujian dapat dilanjutkan pada kombinasi frekuensi dan skala amplitudo lainnya.
	\end{enumerate}

	\newpage
	\subsubsection{Uji Konsistensi: Histeresis}
	
	Untuk uji histeresis, pada dasarnya adalah mengulang pengujian dengan membalik urutan skala output.
	Sebagai contoh:
	\begin{itemize}
		\item Pengujian telah dilakukan dengan skala output naik mulai dari 1 hingga 9 di setiap frekuensi.
		\item Pengujian selanjutanya dilakukan skala output turun mulai dari 9 hingga 1 di setiap frekuensi.
	\end{itemize}
	
	\subsubsection{Uji Konsistensi: Daya Baterai}
	
	Untuk uji baterai, maka dilakukan pengulangan uji seperti sebelumnya namun dengan hari yang berbeda.
	Selama unit tidak di-recharge, maka dengan memperhatikan:
	\begin{itemize}
		\item arus kerja chip STM32F401RE
		\item arus kerja chip MAX98357A
		\item arus kerja regulator TP0645
	\end{itemize}
	maka dapat diasumsikan bahwa daya baterai telah berkurang saat pengujian dibandingkan hari sebelumnya.
	Selanjutnya dapat dilakukan pengujian ulang sebagaimana panduan sebelumnya.
	
	\subsubsection{Jumlah Hasil}
	Jumlah hasil tabel yang diharapkan dengan memperhatikan
	\begin{itemize}
		\item Headphone 2 unit (Bose dan Miniso)
		\item Unit prototype 2 unit (telah diberi Label A dan B)
		\item Pengujian histeris 6 kali, dengan rincian:
		\begin{itemize}
			\item skala yang semakin naik sebanyak 3 kali
			\item skala yang semakin turun sebanyak 3 kali
			\item naik dan turun dilakukan bergantian
		\end{itemize}
		\item Semua di atas pengujian 3 kali dengan perbedaan daya baterai (diukur pada hari yang berbeda)
	\end{itemize}
	
	maka diharapkan akan ada 72 tabel hasil di akhir pengujian.
	
	\vspace{30pt}\centering \textbf{--- Selesai ---}

\end{document}

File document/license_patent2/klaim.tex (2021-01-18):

\documentclass[12pt,]{article}
\usepackage[utf8]{inputenc}
\usepackage[T1]{fontenc}
\usepackage{mathptmx}
\usepackage{geometry}
\usepackage{mathtools}
\usepackage[english]{babel}
\usepackage{graphicx}
\usepackage{stackengine}
\usepackage[os=win]{menukeys}
\usepackage{hyperref}
\usepackage{minted}
\usepackage{xcolor}
\usepackage{tikz}
\usepackage[yyyymmdd,hhmmss]{datetime}
\usepackage{etoolbox}
\usepackage{enumitem}

\patchcmd{\thebibliography}{\section*{\refname}}{}{}{}

\newcommand{\ShowOsVersion}{
	\immediate\write18{\unexpanded{foo=`uname -sro` && echo "${foo}" > tmp.tex}}
	\input{tmp}\immediate\write18{rm tmp.tex}
}

\newcommand{\ShowTexVersion}{
	\immediate\write18{\unexpanded{foo=`pdflatex -version | head -n1 | cut -d' ' -f1,2` && echo "${foo}" > tmp.tex}}
	\input{tmp}\immediate\write18{rm tmp.tex}
}

\addto\captionsenglish{\renewcommand{\contentsname}{Daftar Isi}}

\hypersetup{
	colorlinks=true, %set true if you want colored links
	linktoc=all,     %set to all if you want both sections and subsections linked
	linkcolor=blue,  %choose some color if you want links to stand out
	urlcolor=blue,	 %url color
}

\geometry{
	legalpaper,
	left=15mm,
	right=10mm,
	top=10mm,
	bottom=15mm,
}

\title{\Large \bf
	Patent Claim Draft\\
}

\author{Achmadi ST MT}

\date{}

\hypersetup{citecolor=black}

\definecolor{LightGray}{gray}{0.95}

%\pagecolor[rgb]{0.1,0.1,0.1}
%\color[rgb]{1,1,1}

\begin{document}
	\maketitle
	\thispagestyle{empty}
	
	\newpage
	\section{Daftar Klaim}
	
	\subsection{Fitur Utama}
	
	Berikut fitur utama dan penempatannya:
	\begin{enumerate}
		\item Power Switch, untuk mematikan/menghidupkan unit.
		\item Jack Audio 3.5mm, untuk output ke headphone.
		\item Tombol-tombol, untuk interaksi user.
		\item Lampu-lampu LED, untuk interaksi user.
		\item Lampu indikator jawaban salah-benar.
		\item Port USB untuk Charging
		\item Tombol Reset, untuk memulai ulang unit
		\item Lampu LED Indikator Mode
		\item Slot Memory MicroSD
		\item Port USB untuk koneksi data dengan PC/Android
	\end{enumerate}

	\begin{figure}[!ht]
		\centering
		
		\caption{Layout penempatan fitur-fitur untuk interaksi dengan pengguna}
	\end{figure}

	\textbf{Poin Klaim:} Pola penempatan (layout) fitur-fitur pada box sedemikian ditunjukkan oleh Figure 1.
	
	\newpage
	\subsection{Start Sequence}
	
	Berikut urutan langkah mudah untuk memulai proses Audiometri pada unit
	\begin{enumerate}
		\item Pastikan bahwa unit Audimetri pada status siap.
		\begin{enumerate}
			\renewcommand{\theenumi}{\Alph{enumi}}
			
			\item Nyalakan unit pada switch power
			\item Headphone telah tersambung
			\item MicroSD telah terpasang
		\end{enumerate}
	
		\item LED Mode akan berkedip satu kali setiap satu detik
		\item Tekan satu kali tombol nomor 3 
		\item LED Indikator nomor 4 akan menyala
		\item Tekan satu kali tombol nomor 5
		\item LED nomer 4 akan mati dan LED nomor 6 akan menyala
		\item Tekan satu kali tombol nomor 7
		\item Semua LED akan mati kecuali LED nomor 2 atau 8 akan berkedip cepat.
	\end{enumerate}

	Proses Audiometri telah dimulai.

	\begin{figure}[!ht]
		\centering
		
		\caption{Urutan langkah memulai proses Audiometri}
	\end{figure}

	\textbf{Poin Klaim:} Urutan langkah interaksi pengguna untuk memulai proses Audimetri sebagaimana dijelaskan
	pada penjelasan di atas dan pada Figure 2
	
	\newpage
	\subsection{Interaksi Audiometri}
	
	Berikut adalah urutan langkah interaksi pengguna saat proses Audiometri.
	\begin{enumerate}
		\item Pastikan poin berikut telah siap. Jika belum maka reset kembali unit
		dan ulangi kembali langkah startup.
		\begin{enumerate}
			\renewcommand{\theenumi}{\Alph{enumi}}
			
			\item LED Indikator pada posisi 1a berkedip cepat.
			\item Headphone telah terpasang.
		\end{enumerate}
	
		\item \textbf{Perhatikan} output dari unit.
		\begin{enumerate}
			\renewcommand{\theenumi}{\Alph{enumi}}
			
			\item LED pada baris 2a akan berkedip sekali bergantian
			\item Nada murni pada output 2a akan terdengar,
			bersamaan salah satu LED baris 2a.
		\end{enumerate}
	
		\item Tekan satu tombol dimana LED baris 2a menyala bersamaan dengan terdengar nada murni.
		
		\item LED pada baris 4 akan menyala sebagai respon jawaban.
		Hijau jika benar atau Merah jika salah.
		
		\item Lanjutkan hingga LED Mode pada nomor 5 kembali berkedip satu setiap satu detik,
		yang menandakan sesi uji Audiometri selesai.
	\end{enumerate}
	
	\begin{figure}[!ht]
		\centering
		
		\caption{Interaksi Proses Audiometri}
	\end{figure}

	\textbf{Poin Klaim:} Urutan langkah interaksi pengguna untuk selama proses Audimetri sebagaimana dijelaskan
	pada penjelasan di atas dan pada Figure 3.
	
	\newpage
	\subsection{Merek dan Logo}
	
	Belum terdefinisi dan bukan poin klaim Paten melainkan Merek Dagang.
	
\end{document}

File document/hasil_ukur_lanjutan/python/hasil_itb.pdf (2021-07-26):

## hasil_itb

July 26, 2021

[1]: %load_ext autoreload
%autoreload 2
#%matplotlib notebook

from jupyterthemes import jtplot jtplot.style(theme='grade3')

[2]: import numpy as np

from matplotlib import cm
import matplotlib.pyplot as plt import matplotlib.ticker as mticker from mpl_toolkits.mplot3d import Axes3D

from tabulate import tabulate

np.set_printoptions(suppress=True)

[3]: # Measurement
Ukur_Freq = np.array([250, 500, 1000, 2000, 4000, 8000]) Ukur_OutUp = np.array([1, 2, 3, 4, 5, 6, 7, 8, 9]) Ukur_OutDown = np.array([9, 8, 7, 6, 5, 4, 3, 2, 1])

[4]: def PlotSPLEachFreq(array_in,judul='grafik'):
fig, axs = plt.subplots(3,2,figsize=(12,6)) axs[0, 0].plot(Ukur_OutUp, array_in[0,:]) axs[0, 0].set_title("250 Hz")
axs[1, 0].plot(Ukur_OutUp, array_in[1,:]) axs[1, 0].set_title("500 Hz")
axs[2, 0].plot(Ukur_OutUp, array_in[2,:]) axs[2, 0].set_title("1000 Hz")
axs[0, 1].plot(Ukur_OutUp, array_in[3,:]) axs[0, 1].set_title("2000 Hz")
axs[1, 1].plot(Ukur_OutUp, array_in[4,:]) axs[1, 1].set_title("4000 Hz")
axs[2, 1].plot(Ukur_OutUp, array_in[5,:]) axs[2, 1].set_title("8000 Hz") fig.tight_layout()

plt.show()

[5]: def FreqEstim(array_in): c0 = np.polyfit(Ukur_OutUp, array_in[0,:], deg=3) print(250,np.around(c0,2))
c1 = np.polyfit(Ukur_OutUp, array_in[1,:], deg=3) print(500,np.around(c1,2))
c2 = np.polyfit(Ukur_OutUp, array_in[2,:], deg=3) print(1000,np.around(c2,2))
c3 = np.polyfit(Ukur_OutUp, array_in[3,:], deg=3) print(2000,np.around(c3,2))
c4 = np.polyfit(Ukur_OutUp, array_in[4,:], deg=3) print(4000,np.around(c4,2))
c5 = np.polyfit(Ukur_OutUp, array_in[5,:], deg=3) print(8000,np.around(c5,2))

model = np.around(np.array([c0,c1,c2,c3,c4,c5]),2)

return model

[6]: def TexTable(array_in, header_in): print(tabulate(array_in, header_in, tablefmt="latex"))

[7]: freq = np.array([250,500,1000,2000,4000,8000]) levl = np.array([9,8,7,6,5,4,3,2,1])

[8]: bose_1 = np.array([
[75.0,68.9,62.8,56.8,50.7,45.1,40.2,35.4,32.5], [74.5,68.4,62.4,56.3,50.3,44.5,39.4,35.1,31.5], [81.2,75.2,69.2,63.1,57.1,51.2,45.5,40.8,37.2], [78.0,71.9,65.9,59.8,53.8,48.2,42.7,38.2,35.2], [82.9,76.9,70.9,64.8,58.8,53.0,47.8,43.8,41.0], [79.1,73.0,67.0,60.9,55.2,49.6,45.4,42.8,42.0] ])

bose_2 = np.array([
[76.1,70.1,64.1,58.0,52.1,46.3,41.2,37.6,36.2], [75.1,69.1,63.0,56.9,50.1,45.3,41.0,36.5,33.6], [80.8,74.8,68.8,62.7,56.6,50.8,45.5,41.1,38.1], [76.9,70.8,64.8,58.7,52.7,47.1,42.2,39.0,37.4], [83.2,77.2,71.2,65.1,59.2,53.4,48.1,43.9,41.2], [77.4,71.5,65.4,59.4,53.7,48.5,44.4,42.3,41.5] ])

[9]: miniso_1 = np.array([ [73.7,67.7,61.7,55.7,49.9,44.1,38.7,33.7,30.5], [74.8,68.8,62.9,56.9,51.0,45.2,39.8,34.9,31.1],

[78.0,72.0,66.0,60.1,54.2,48.4,43.0,38.0,34.3], [68.7,62.6,56.7,50.7,44.9,39.1,34.0,29.9,27.2], [62.2,56.2,50.2,44.3,38.7,33.6,29.6,27.7,27.0], [65.0,59.0,53.0,47.2,41.5,36.3,32.7,30.4,29.6] ])

miniso_2 = np.array([
[85.2,79.2,73.2,67.2,61.2,55.3,49.7,45.3,41.6], [86.4,80.4,74.4,68.4,62.4,56.5,51.1,46.1,42.3], [89.7,83.7,77.7,71.7,65.8,59.9,54.3,49.3,45.5], [80.1,74.0,68.0,62.0,56.0,50.2,45.1,41.0,38.7], [73.7,67.7,61.7,55.7,49.9,44.8,41.0,39.0,38.4], [76.0,70.1,64.1,58.1,52.4,47.3,43.9,42.0,41.5] ])

[10]: PlotSPLEachFreq(bose_1[:,::-1], "Prototype A with Bose")


[11]: PlotSPLEachFreq(bose_2[:,::-1], "Prototype B with Bose")


[12]: PlotSPLEachFreq(miniso_1[:,::-1], "Prototype A with Miniso")

[13]: PlotSPLEachFreq(miniso_2[:,::-1], "Prototype B with Miniso")


[14]: avg_bose = np.around((bose_1+bose_2)/2,1) print(avg_bose)

[[75.6 69.5 63.4 57.4 51.4 45.7 40.7 36.5 34.4] [74.8 68.8 62.7 56.6 50.2 44.9 40.2 35.8 32.6] [81. 75. 69. 62.9 56.8 51. 45.5 41. 37.7] [77.4 71.4 65.4 59.2 53.2 47.7 42.4 38.6 36.3] [83.1 77.1 71.1 64.9 59. 53.2 48. 43.8 41.1] [78.2 72.2 66.2 60.2 54.4 49. 44.9 42.6 41.8]]

[15]: model_bose = FreqEstim(avg_bose)

250 [ 0.05 -0.46 -4.7 80.58]
500 [ 0.03 -0.28 -5.41 80.48] 1000 [ 0.04 -0.4 -4.8 86.06] 2000 [ 0.05 -0.49 -4.59 82.33]
4000 [ 0.04 -0.44 -4.72 88.12]
8000 [ 0.06 -0.59 -4.37 83. ]

[16]: avg_miniso = np.around((miniso_1+miniso_2)/2,1) print(avg_miniso)

[[79.4 73.4 67.4 61.4 55.6 49.7 44.2 39.5 36. ] [80.6 74.6 68.6 62.6 56.7 50.8 45.4 40.5 36.7] [83.8 77.8 71.8 65.9 60. 54.2 48.6 43.6 39.9] [74.4 68.3 62.4 56.4 50.4 44.7 39.6 35.4 33. ] [68. 62. 56. 50. 44.3 39.2 35.3 33.4 32.7] [70.5 64.6 58.6 52.6 47. 41.8 38.3 36.2 35.6]]

[17]: model_miniso = FreqEstim(avg_miniso)

250 [ 0.03 -0.32 -4.99 84.58] 500 [ 0.03 -0.28 -5.16 85.93] 1000 [ 0.03 -0.28 -5.09 89.04] 2000 [ 0.04 -0.46 -4.63 79.29]
4000 [ 0.06 -0.53 -4.64 73.05]
8000 [ 0.06 -0.51 -4.67 75.59]

[18]: TexTable(avg_bose[:,::-1],['1','2','3','4','5','6','7','8','9'])

\begin{tabular}{rrrrrrrrr}
\hline
1 & | 2 & | 3 & | 4 & | 5 & | 6 & | 7 & | 8 & | 9 \\
\hline
34.4 & 36.5 & 40.7 & 45.7 & 51.4 & 57.4 & 63.4 & 69.5 & 75.6 \\ 32.6 & 35.8 & 40.2 & 44.9 & 50.2 & 56.6 & 62.7 & 68.8 & 74.8 \\
37.7 & 41 | & 45.5 & 51 | & 56.8 & 62.9 & 69 | & 75 | & 81 | \\
36.3 & 38.6 & 42.4 & 47.7 & 53.2 & 59.2 & 65.4 & 71.4 & 77.4 \\
41.1 & 43.8 & 48 | & 53.2 & 59 | & 64.9 & 71.1 & 77.1 & 83.1 \\
41.8 & 42.6 & 44.9 & 49 | & 54.4 & 60.2 & 66.2 & 72.2 & 78.2 \\
\hline
\end{tabular}

[19]: TexTable(avg_miniso[:,::-1],['1','2','3','4','5','6','7','8','9'])

\begin{tabular}{rrrrrrrrr}
\hline
1 & | 2 & | 3 & | 4 & | 5 & | 6 & | 7 & | 8 & | 9 \\
\hline
36 & 39.5 & 44.2 & 49.7 & 55.6 & 61.4 & 67.4 & 73.4 & 79.4 \\ 36.7 & 40.5 & 45.4 & 50.8 & 56.7 & 62.6 & 68.6 & 74.6 & 80.6 \\
39.9 & 43.6 & 48.6 & 54.2 & 60 | & 65.9 & 71.8 & 77.8 & 83.8 \\
33 | & 35.4 & 39.6 & 44.7 & 50.4 & 56.4 & 62.4 & 68.3 & 74.4 \\
32.7 & 33.4 & 35.3 & 39.2 & 44.3 & 50 | & 56 | & 62 | & 68 | \\
35.6 & 36.2 & 38.3 & 41.8 & 47 | & 52.6 & 58.6 & 64.6 & 70.5 \\
\hline
\end{tabular}

[ ]:

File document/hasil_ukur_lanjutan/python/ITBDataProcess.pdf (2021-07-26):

## ITBDataProcess

July 26, 2021

### 0.0.1 Import some jupyter spesific modules

[1]: %load_ext autoreload
%autoreload 2
#%matplotlib notebook

from jupyterthemes import jtplot jtplot.style(theme='grade3')

### 0.0.2 Import some necessary modules

[2]: import numpy as np

from matplotlib import cm
import matplotlib.pyplot as plt import matplotlib.ticker as mticker from mpl_toolkits.mplot3d import Axes3D

from tabulate import tabulate

### 0.0.3 Import data from Data Pool Class

[3]: from itb_data_pool import ITBDataPool
datpol = ITBDataPool()

print((' '.join(datpol.All_Vars[0:2]).replace('self.', ''))) print((' '.join(datpol.All_Vars[2:6]).replace('self.', ''))) print('\n')
print((' '.join(datpol.All_Vars[6:9]).replace('self.', ''))) print('\n')
print((' '.join(datpol.All_Vars[9:13]).replace('self.', ''))) print((' '.join(datpol.All_Vars[13:17]).replace('self.', ''))) print('\n')
print((' '.join(datpol.All_Vars[17:21]).replace('self.', ''))) print((' '.join(datpol.All_Vars[21:25]).replace('self.', ''))) print('\n')
print((' '.join(datpol.All_Vars[25:29]).replace('self.', ''))) print((' '.join(datpol.All_Vars[29:33]).replace('self.', '')))

NoUnitNoHP_Second NoUnitNoHP_Data
NoUnitMiniso_Second NoUnitMiniso_Data NoUnitBose_Second NoUnitBose_Data

Ukur_Freq Ukur_OutUp Ukur_OutDown

Day1_Bose1_Up Day1_Bose1_Down Day1_Bose2_Up Day1_Bose2_Down Day1_Miniso1_Up Day1_Miniso1_Down Day1_Miniso2_Up Day1_Miniso2_Down

Day2_Bose1_Up Day2_Bose1_Down Day2_Bose2_Up Day2_Bose2_Down Day2_Miniso1_Up Day2_Miniso1_Down Day2_Miniso2_Up Day2_Miniso2_Down

Day3_Bose1_Up Day3_Bose1_Down Day3_Bose2_Up Day3_Bose2_Down Day3_Miniso1_Up Day3_Miniso1_Down Day3_Miniso2_Up Day3_Miniso2_Down

### 0.0.4 Plot 3D in dB [SPL] function

[4]: def PlotSPL3D(xlabel, ydata, zdata):
Xlabel = xlabel
Xtick = np.arange(len(Xlabel)) X = Xtick
Y = ydata
Z = zdata

X, Y = np.meshgrid(X,Y)

fig = plt.figure(figsize=(8,5), dpi= 100, facecolor='w', edgecolor='k') ax = plt.axes(projection='3d')
surf = ax.plot_surface(X, Y, Z, cmap=cm.coolwarm) ax.set_xticks(Xtick.tolist())
ax.set_xticklabels(Xlabel,rotation=90) #ax.set_xlabel('Frequency') ax.set_ylabel('Seconds')
#ax.set_zlabel('dB [SPL]') ax.set_zlim(0,110)

fig.colorbar(surf, shrink=0.3, aspect=5) plt.show()
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

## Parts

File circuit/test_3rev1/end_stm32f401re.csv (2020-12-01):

Id | Designator | Package | Quantity | Designation | Supplier | Code
1 | C-SN1,C-SPL1,C-SPR1 | C_0805_2012Metric_Pad1.15x1.40mm_HandSolder | 3 | 220pF
2 | C-VCAP1 | CP_EIA-3216-18_Kemet-A | 1 | 4.7uF
3 | C-VREG1,C-VREG2,C-VREG3,C-XTAL1,C-XTAL2 | C_0805_2012Metric_Pad1.15x1.40mm_HandSolder | 5 | C
4 | D-ANS1,D-ANS2,D-BTN1,D-BTN2,D-BTN3,D-IND1,D-LEDWIFI1 | LED_1206_3216Metric_Pad1.42x1.75mm_HandSolder | 7 | LED | Digiware | 255-099:10, 255-036:10, 255-026:10, 255-096:30
5 | D-VREG1 | D_SMA_Handsoldering | 1 | D
6 | H1,H2,H3,H4 | MountingHole_2.5mm_Pad_Via | 4 | MountingHole
7 | J2 | MicroUSB | 1 | USB_B_Micro
8 | J-AUDIO1 | Tayda_3.5mm_stereo_TRS_jack_A-853 | 1 | AudioJack3_Ground | Digiware | 325-008:5
9 | J-ESP-12E1 | PinHeader_1x06_P2.54mm_Vertical | 1 | Conn_01x06_Male
10 | J-SWD1 | PinHeader_1x05_P2.54mm_Vertical | 1 | Conn_01x05_Male
11 | J-VDD1 | vpin-x1 | 1 | Conn_01x01_Male
12 | J-VPWR1 | vpin-x2 | 1 | Conn_01x02_Male
13 | L-DACN1,L-DACN2,L-DACP1,L-DACP2 | L_0805_2012Metric_Pad1.15x1.40mm_HandSolder | 4 | 100uH
14 | R-ANS1,R-ANS2,R-ANS3,R-ESP12E1,R-ESP12E2,R-ESP12E3,R-ESP12E4,R-ESP12E5,R-RST1,R-SD1,R-SD2,R-SD3 | R_0805_2012Metric_Pad1.15x1.40mm_HandSolder | 12 | 10K
15 | R-GAIN1,R-GAIN2 | R_0805_2012Metric_Pad1.15x1.40mm_HandSolder | 2 | 100K
16 | R-IND1,R-LEDWIFI1,RL-ANS1,RL-BTN1 | R_0805_2012Metric_Pad1.15x1.40mm_HandSolder | 4 | 330
17 | R-SD_L1,R-SD_R1 | R_0805_2012Metric_Pad1.15x1.40mm_HandSolder | 2 | 1M
18 | R-USB1 | R_0805_2012Metric_Pad1.15x1.40mm_HandSolder | 1 | 4K7
19 | R-USB2,R-USB3 | R_0805_2012Metric_Pad1.15x1.40mm_HandSolder | 2 | 68
20 | R-VDDESP1,R-WIFI1,R-WIFI2 | R_0805_2012Metric_Pad1.15x1.40mm_HandSolder | 3 | 0
21 | SD1 | MICRO-SD9+4P-SMD-16.1X14.5X1.85MM | 1 | MICRO-SD-CARD-SOCKET-9P
22 | SW-ANS1,SW-ANS2,SW-ANS3,SW-RST1 | SW_PUSH_6mm | 4 | SW_Push
23 | U1,U4 | QFN-16-1EP_3x3mm_P0.5mm_EP1.7x1.7mm | 2 | MAX98357
24 | U2 | LQFP-64_10x10mm_P0.5mm | 1 | STM32F401RETx
25 | U3 | SOT-223-3_TabPin2 | 1 | AMS1117-3.3
26 | U5 | ESP-12E | 1 | ESP-12E | Digiware | 432-242:3
27 | U6 | sph0645 | 1 | SPH0645
28 | Y-XTAL1 | Crystal_HC49-4H_Vertical | 1 | 16MHz
29 | H5 | MountingHole_2.5mm_Pad_Via | 1 | CableHole

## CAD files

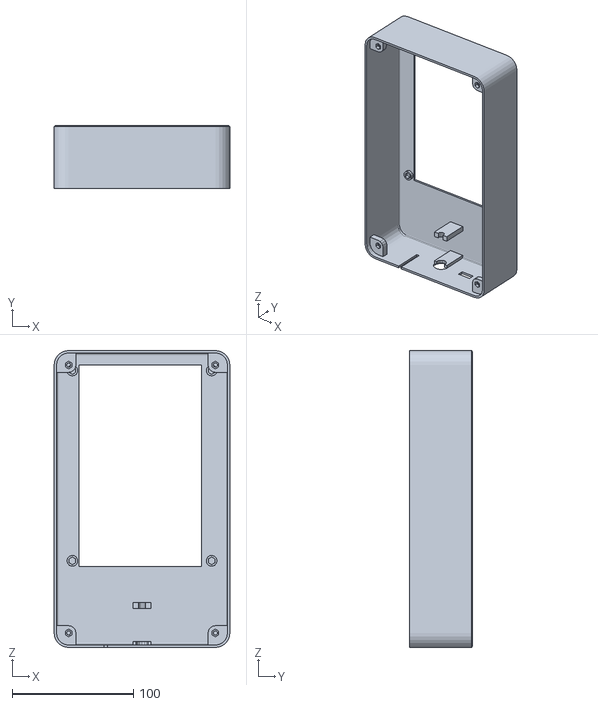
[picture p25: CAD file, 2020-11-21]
casing/rpi/top-rpi.stl
145.0 x 52.0 x 245.0

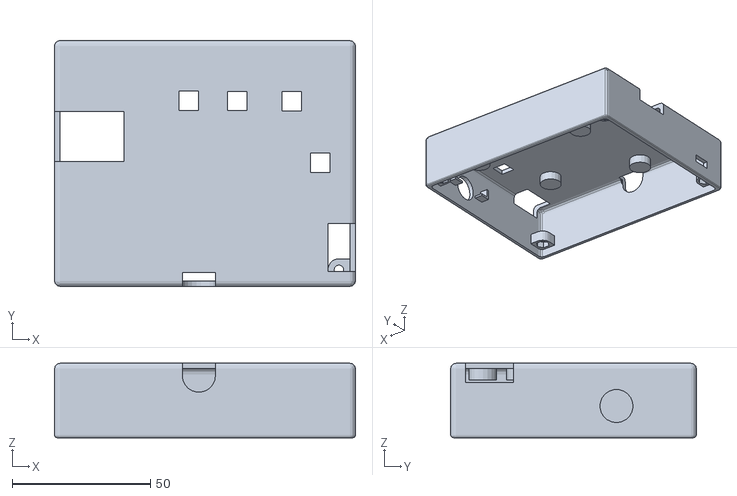
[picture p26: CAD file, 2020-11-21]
casing/stm32/top.stl
109.0 x 89.0 x 27.0

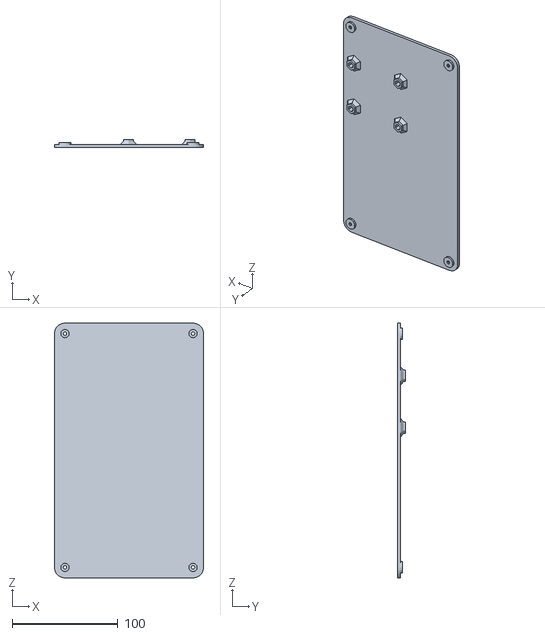
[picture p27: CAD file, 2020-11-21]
casing/rpi/bottom-rpi.stl
141.0 x 8.00 x 241.0

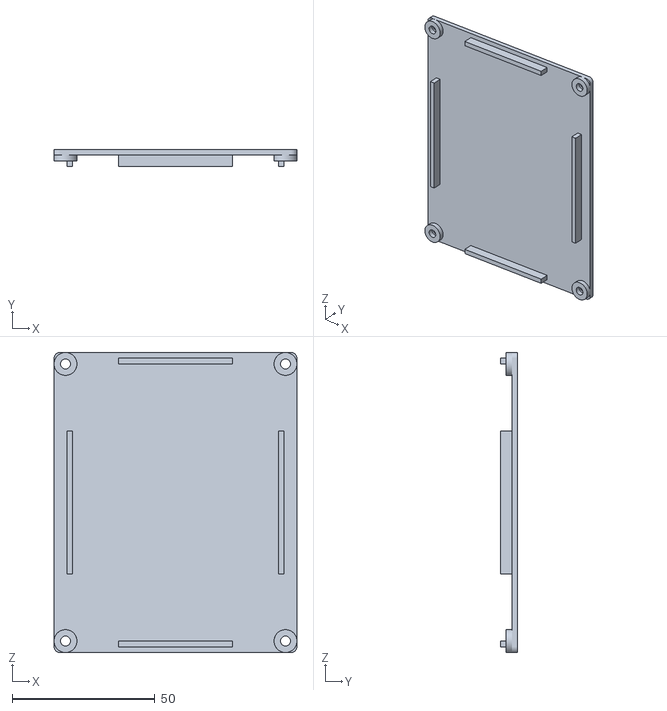
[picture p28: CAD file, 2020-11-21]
casing/stm32/bottom.stl
85.0 x 6.00 x 105.0

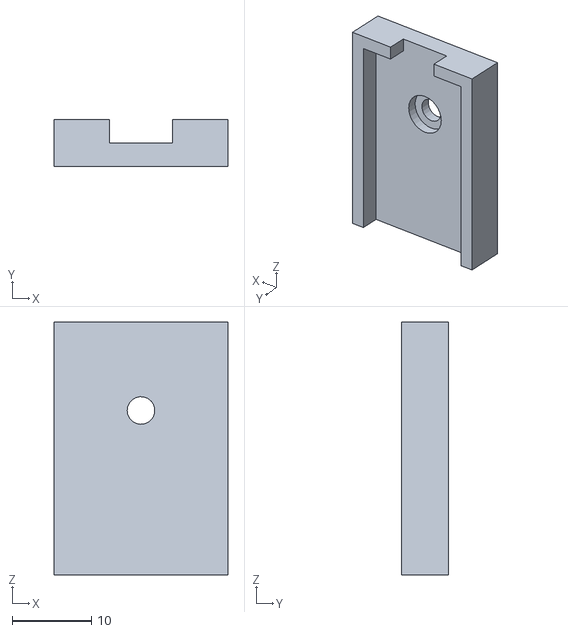
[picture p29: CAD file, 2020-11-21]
casing/stm32/tp0645.stl
22.0 x 6.00 x 32.0

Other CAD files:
casing/stm32/unit_mockup/mockup.FCStd
document/license_patent2/box/box.FCStd
document/license_patent2/box/top_noholder.stl

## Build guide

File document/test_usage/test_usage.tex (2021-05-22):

\documentclass[12pt,]{article}
\usepackage[utf8]{inputenc}
\usepackage[T1]{fontenc}
\usepackage{mathptmx}
\usepackage{geometry}
\usepackage{mathtools}
\usepackage[english]{babel}
\usepackage{graphicx}
\usepackage{stackengine}
\usepackage[os=win]{menukeys}
\usepackage{hyperref}
\usepackage{minted}
\usepackage{xcolor}
\usepackage{tikz}
\usepackage[yyyymmdd,hhmmss]{datetime}
\usepackage{etoolbox}
\usepackage[inline]{enumitem}
\usepackage[figurename=Gambar-]{caption}

\patchcmd{\thebibliography}{\section*{\refname}}{}{}{}

\addto\captionsenglish{\renewcommand{\contentsname}{Daftar Isi}}

\hypersetup{
	colorlinks=true, %set true if you want colored links
	linktoc=all,     %set to all if you want both sections and subsections linked
	linkcolor=blue,  %choose some color if you want links to stand out
	urlcolor=blue,	 %url color
}

\geometry{
	a5paper,
	left=15mm,
	right=10mm,
	top=10mm,
	bottom=15mm,
}

\title{\Large \bf
	Quick Usage Manual\\
}

\author{Achmadi ST MT}

\date{}

\hypersetup{citecolor=black}

\definecolor{LightGray}{gray}{0.95}

\begin{document}
	\maketitle
	\thispagestyle{empty}
	
	\vspace*{300pt}
	
	Update: {\today} at \currenttime \\
	
	%%%%%%%%%%%%%%%%%%%%%%%%%%%%%%%%%%%%%%%%%%%%%%%%%%%%%%%%%%%%%%%%%
	
	\newpage
	\tableofcontents
	
	%%%%%%%%%%%%%%%%%%%%%%%%%%%%%%%%%%%%%%%%%%%%%%%%%%%%%%%%%%%%%%%%%
	
	\newpage
	\section{Pendahuluan}
	
	Berikut beberapa poin pendahuluan yang selayaknya diperhatikan sebelum penggunaan.
	
	\subsection{Antarmuka}
	
	Berikut ilustrasi antar muka unit Audiometri (untuk selanjutnya disebut Unit saja):
	
	\begin{figure}[!ht]
		\centering
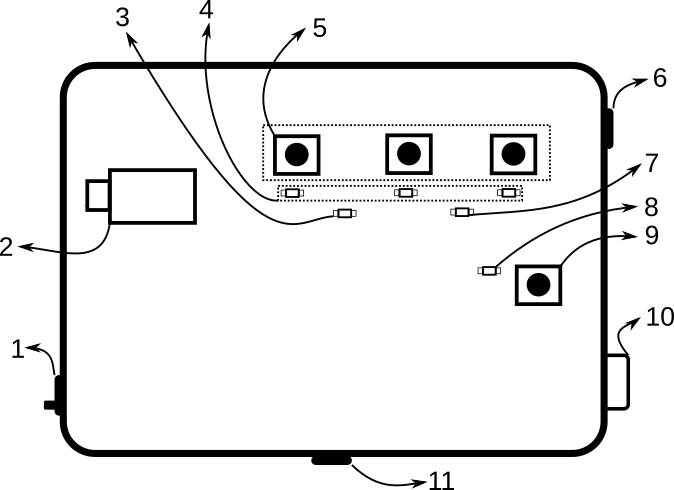
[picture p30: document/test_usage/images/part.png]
		
		\caption{Antar muka Unit}
	\end{figure}

	\newpage
	\textbf{Keterangan:}
	\begin{enumerate}
		\item Power Switch untuk ON/OFF Unit.
		\item Jack 3.5mm untuk Ouput Nada Murni.
		\item LED Merah (Indikator Jawaban Salah).
		\item Grup LED Kuning (Indikator Pilihan Jawaban).
		\item Grup Tombol Pilihan Jawaban.
		\item Port USB untuk Charging.
		\item LED Hijau (Indikator Jawaban Benar).
		\item LED Biru (Indikator Mode Unit).
		\item Tombol Reset untuk memulai ulang Unit.
		\item Slot Micro SDCard untuk penyimpanan.
		\item Port USB untuk Data dan Setting.
	\end{enumerate}
	
	\subsection{Charging}
	
	Untuk Charging, dapat menggunakan adaptor charger and kabel microUSB yang umum digunakan untuk mengisi daya perangkat Android.
	
	Pastikan Unit dalam \textbf{kondisi mati/OFF} saat charging. 
	Sambungkan Unit ke adaptor dengan kabel microUSB pada port nomer 6 di gambar-1. Kemudian sambungkan adaptor ke sumber AC/PLN.
	
	Unit akan menampilkan nyala \textbf{Merah} pada port USB Charging.
	Tunggu nyala tersebut berubah menjadi \textbf{Biru} sebagai tanda telah penuh.
	
	\newpage
	\section{Persiapan}
	
	\subsection{Cek Persiapan}
	
	Sebelum menghidupkan, pastikan beberapa hal berikut:
	
	\begin{itemize}
		\item Unit tidak sedang terhubung kabel-USB apapun.
		\item Micro-SDcard format FAT32 telah terpasang.
		\item Headphone yang tersedia telah terhubung Unit.
		\item Headphone telah terpakai di pengguna dan tidak terbalik
		kanan dan kiri.
	\end{itemize}

	\subsection{Menyalakan}
	
	Untuk menyalakan, perhatikan ilustrasi berikut:
	
	\begin{figure}[!ht]
		\centering
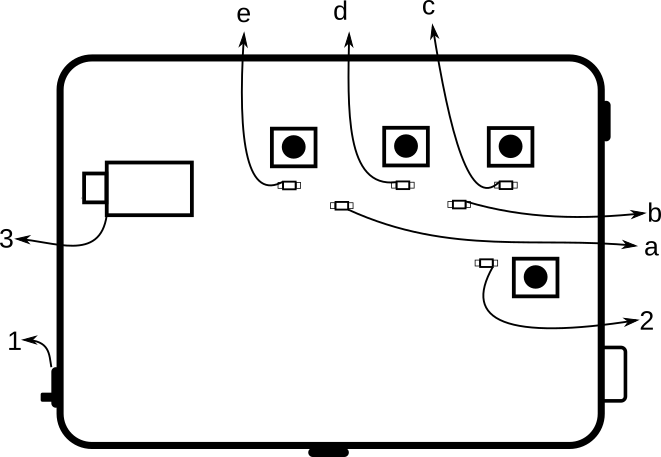
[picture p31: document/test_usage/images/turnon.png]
		
		\caption{Menyalakan Unit}
	\end{figure}
	
	\newpage
	Urutan menyalakan Unit:
	\begin{itemize}
		\item Geser Power Switch (no.1).
		\item LED Biru no.2 akan menyala.E
		\item LED no. a, b, c, d, dan e akan menyala bergantian.
		\item Tone akan terdengar 2x kiri dan kanan bergantian dari port Audio (no.3)
		\item LED Biru no.2 menjadi berkedip.
	\end{itemize}

	Jika respon Unit tidak seperti di atas saat pertama dinyalakan, maka Unit sedang tidak layak pakai
	
	\subsection{LED Indikator Biru}
	
	LED Indikator Biru adalah LED no.8 pada gambar-1, atau no.2 pada gambar-2.
	
	Berikut adalah arti dari pola berkedip LED Biru:
	\begin{itemize}
		\item Berkedip lambat.\\
		Unit dalam kondisi Idle dan siap dipakai.
		
		\item Berkedip 2x cepat dan mati dalam selang waktu.\\
		Micro-SDcard tidak dapat diakses atau tidak ada.
		
		\item Berkedip cepat.\\
		Sedang dalam sesi proses Audiometri.
		
		\item Tidak Berkedip.\\
		Unit mengalami freeze/hank. Tekan tombol Reset atau nyalakan ulang Unit.
	\end{itemize}
	
	\newpage
	\section{Audiometri}
	
	\textbf{Perhatian:} Untuk bab panduan ini, sebaiknya dipahami terlebih dahulu sebelum dipraktikan.
	
	\subsection{Memulai}
	Berikut cara memulai sesi Audiometri:
	
	\begin{figure}[!ht]
		\centering
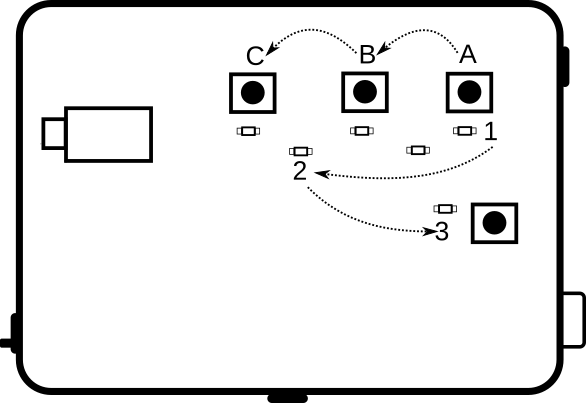
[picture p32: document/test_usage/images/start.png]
		
		\caption{Memulai Audiometri}
	\end{figure}

	\begin{itemize}
		\item Tekan tombol A, LED di no.1 akan menyala.
		\item Tekan tombol B, LED di no.2 akan berganti menyala.
		\item Tekan tombol C, LED di no.3 akan berganti berkedip cepat.
		Proses Audiometri dimulai.
	\end{itemize}
	
	\newpage
	\subsection{Sesi Audiometri}
	
		\begin{figure}[!ht]
		\centering
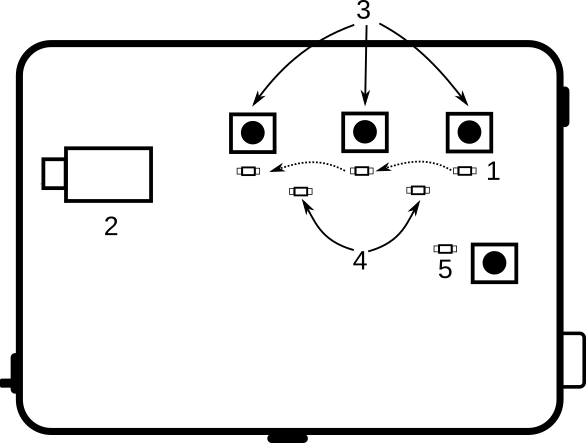
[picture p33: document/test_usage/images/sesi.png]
		
		\caption{Memulai Audiometri}
	\end{figure}
	
	Berikut interaksi saat sesi proses Audiometri:
	\begin{enumerate}
		\item LED Kuning pada baris 1 akan menyala bergantian.
		\item Nada akan terdengar pada salah satu LED Kuning tersebut.
		\item Tekan salah satu tombol di grup no.3 dimana LED menyala bersamaan dengan terdengar bunyi nada murni.
		\item LED Merah atau Hijau akan menyala tergantung salah/benar jawaban
		\item Proses Sesi Audiometri selesai saat LED Indikator Biru (no.5) berubah berkedip lambat.
	\end{enumerate}

	\newpage
	\section{Spesifikasi Teknis}
	Berikut spesifikasi teknis unit box Audiometri Portable:
	
	\begin{enumerate}
		\item Tegangan Kerja: VDD (2.5v - 4.2v)
		\item USB Charging: VCC (4.5v - 5.5v)
		\item Dimensi: mm X mm
		\item Berat: gram
		\item Minimal Impendance: 300 $\Omega$
		\item Frekuensi Nada Murni: 250 Hz - 8000 Hz
		\item Loudness Nada Murni: 35 dB(SPL) - 85 dB(SPL)
		\item USB Data: protokol STM32-VCP
		\item IoT Port: Wi-Fi Client
		
	\end{enumerate}
	
\end{document}

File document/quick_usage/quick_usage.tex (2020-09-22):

\documentclass[12pt,]{article}
\usepackage[utf8]{inputenc}
\usepackage[T1]{fontenc}
\usepackage{mathptmx}
\usepackage{geometry}
\usepackage{mathtools}
\usepackage[english]{babel}
\usepackage{graphicx}
\usepackage{stackengine}
\usepackage[os=win]{menukeys}
\usepackage{hyperref}
\usepackage{minted}
\usepackage{xcolor}
\usepackage{tikz}
\usepackage[yyyymmdd,hhmmss]{datetime}
\usepackage{etoolbox}
\usepackage[inline]{enumitem}

\patchcmd{\thebibliography}{\section*{\refname}}{}{}{}

\newcommand{\ShowOsVersion}{
	\immediate\write18{\unexpanded{foo=`uname -sro` && echo "${foo}" > tmp.tex}}
	\input{tmp}\immediate\write18{rm tmp.tex}
}

\newcommand{\ShowTexVersion}{
	\immediate\write18{\unexpanded{foo=`pdflatex -version | head -n1 | cut -d' ' -f1,2` && echo "${foo}" > tmp.tex}}
	\input{tmp}\immediate\write18{rm tmp.tex}
}

\addto\captionsenglish{\renewcommand{\contentsname}{Daftar Isi}}

\hypersetup{
	colorlinks=true, %set true if you want colored links
	linktoc=all,     %set to all if you want both sections and subsections linked
	linkcolor=blue,  %choose some color if you want links to stand out
	urlcolor=blue,	 %url color
}

\geometry{
	a5paper,
	left=15mm,
	right=10mm,
	top=10mm,
	bottom=15mm,
}

\title{\Large \bf
	Quick Usage Manual\\
	\small{(Mid-Testing Stage)}
}

\author{Achmadi ST MT}

\date{}

\hypersetup{citecolor=black}

\definecolor{LightGray}{gray}{0.95}

%\pagecolor[rgb]{0.1,0.1,0.1}
%\color[rgb]{1,1,1}

\begin{document}
	\maketitle
	\thispagestyle{empty}
	
	\vspace*{300pt}
	
	\noindent This manual written using: \\
	OS : \ShowOsVersion \\
	TeX : \ShowTexVersion \\
	Update: {\today} at \currenttime \\
	
	%%%%%%%%%%%%%%%%%%%%%%%%%%%%%%%%%%%%%%%%%%%%%%%%%%%%%%%%%%%%%%%%%
	
	\newpage
	\tableofcontents
	
	%%%%%%%%%%%%%%%%%%%%%%%%%%%%%%%%%%%%%%%%%%%%%%%%%%%%%%%%%%%%%%%%%
	
	\newpage
	\section{Quick Usage}
	
	\subsection{Power Up}
	
	Untuk menyalakan unit Audiometri, geser slide-switch di dekat power jack audio.
	Jika headphone telah terpasang, maka anda akan mendengar 2 tone berbunyi kanan-kiri secara bergantian
	
	\begin{figure}[!ht]
		\centering
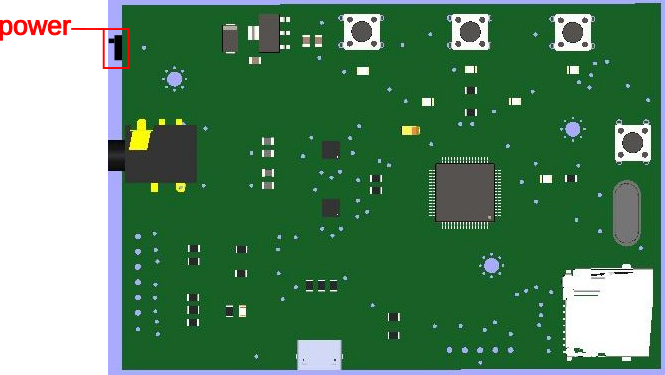
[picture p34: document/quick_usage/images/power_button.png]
		
		\caption{Posisi power switch}
	\end{figure}

	Sebelum memulai proses audiometri, pastikan beberapa hal berikut:
	
	\begin{itemize}
		\item Headphone sudah terpasang dan dipakai pengguna
		\item Memory Card telah terpasang.
		Jika belum, pasang MMC dan nyalakan ulang unit.
	\end{itemize}
	
	\newpage
	\subsection{Start Audiometri}
	
	Proses untuk memulai proses Audiometri
	
	\begin{figure}[!ht]
		\centering
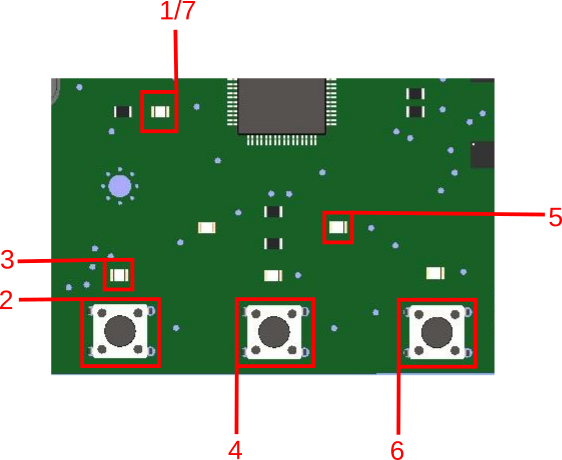
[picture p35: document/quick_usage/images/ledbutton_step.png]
		
		\caption{Urutan tombol dan LED interaksi proses Audiometri}
	\end{figure}
	
	Urutan untuk memulai proses audiometri adalah:
	
	\begin{enumerate}
		\item Saat kondisi \textit{idle}, LED pada posisi ini akan berkedip lambat.
		
		\item Tekan salah satu dari 3 tombol yang sebaris.
		
		\item LED terdekat dengan tombol menyala
		
		\item Tekan tombol lain selain tombol sebelumnya.
		
		\item LED sebelum nya akan mati dan LED Hijau menyala.
		Ini adalah kondisi standby/siap
		
		\item Tekan tombol lain selain dua tombol sebelumnya.
		
		\item LED pada posisi ini akan berkedip cepat dan LED lainnya akan mati.
		Proses Audiometri dimulai.
		
	\end{enumerate}
	
	Proses Audiometri akan selesai ditandai dengan LED pada langkah 1 atau 7 kembali berkedip lambat.
	
	\newpage
	\subsection{Input Audiometri}
	
	Interaksi user saat proses Audiometri pada setiap variasi frekuensi dan amplitudo secara berulang hingga proses audiometri selesai.
	
	\begin{figure}[!ht]
		\centering
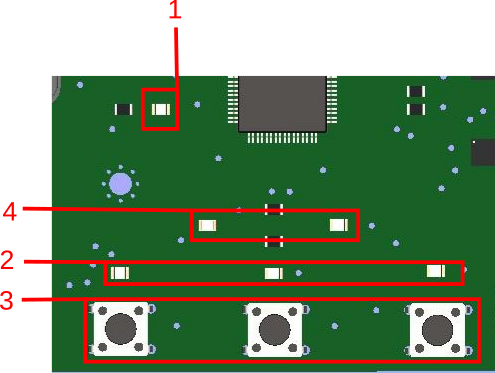
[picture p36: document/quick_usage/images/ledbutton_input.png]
		
		\caption{Urutan tombol dan LED untuk memulai}
	\end{figure}
	
	\begin{enumerate}
		\item Pastikan LED berkedip cepat sebagai indikator proses Audiometri sedang berjalan.
		
		\item Setiap LED pada grup ini akan berkedip satu kali secara berurutan.
		Salah satu diantara nya akan memberikan bunyi Tone
		
		\item Tekan satu Tombol pada grup ini sesuai LED yang menyala bersamaan dengan bunyi Tone terdengar.
		
		\item LED pada grup ini menyala salah satu. Hijau jika benar (LED, Tombol, dan Tone sesuai) dan Merah jika salah.
	\end{enumerate}

	\newpage
	\section{Formulir Survey Subyektif}
	
	Nama: ........................................\\
	
	\vspace*{20pt}
	\noindent Lingkari pilihan yang anda anggap paling cocok
	\vspace*{20pt}
	
	\noindent 1. Apakah anda sudah memahami konten manual penggunaan tersebut?\\
	\begin{itemize*}
		\item Tidak \hspace*{25pt}
		\item Kurang \hspace*{25pt}
		\item Cukup \hspace*{25pt}
		\item Lebih \hspace*{25pt}
		\item Penuh \hspace*{25pt}
	\end{itemize*}

	\vspace*{10pt}
	
	\noindent 2. Menurut anda, apakah manual tersebut menjelaskan penggunaan dengan baik?\\
	\begin{itemize*}
		\item Tidak \hspace*{25pt}
		\item Kurang \hspace*{25pt}
		\item Cukup \hspace*{25pt}
		\item Lebih \hspace*{25pt}
		\item Penuh \hspace*{25pt}
	\end{itemize*}

	\vspace*{10pt}

	\noindent 3. Menurut anda, apakah user interface (led-tombol) sudah nyaman digunakan?\\
	\begin{itemize*}
		\item Tidak \hspace*{25pt}
		\item Kurang \hspace*{25pt}
		\item Cukup \hspace*{25pt}
		\item Lebih \hspace*{25pt}
		\item Penuh \hspace*{25pt}
	\end{itemize*}

	\vspace*{10pt}
	
	\noindent 4. Menurut anda, apakah user interface (led-tombol) sudah cukup untuk proses penggunaan?\\
	\begin{itemize*}
		\item Tidak \hspace*{25pt}
		\item Kurang \hspace*{25pt}
		\item Cukup \hspace*{25pt}
		\item Lebih \hspace*{25pt}
		\item Penuh \hspace*{25pt}
	\end{itemize*}
	
	\vspace*{10pt}
	
	\noindent 5. Menurut anda, apakah dibutuhkan Display (LCD) sebagai pengganti LED indikator?\\
	\begin{itemize*}
		\item Tidak \hspace*{25pt}
		\item Kurang \hspace*{25pt}
		\item Cukup \hspace*{25pt}
		\item Lebih \hspace*{25pt}
		\item Penuh \hspace*{25pt}
	\end{itemize*}
	
	\vspace*{10pt}
	
	\noindent 6. Menurut anda, apakah dibutuhkan Touchscreen (TFT) sebagai pengganti tombol?\\
	\begin{itemize*}
		\item Tidak \hspace*{25pt}
		\item Kurang \hspace*{25pt}
		\item Cukup \hspace*{25pt}
		\item Lebih \hspace*{25pt}
		\item Penuh \hspace*{25pt}
	\end{itemize*}

	\vspace*{10pt}
	
	\noindent 7. Jika menurut anda Display LCD dibutuhkan, informasi apa yang wajib ditampilkan?\\
	...................................................................................................................................\\
	...................................................................................................................................\\
	...................................................................................................................................\\
	...................................................................................................................................\\
	...................................................................................................................................\\
	
	\noindent 8. Jika menurut anda Touchscreen dibutuhkan, informasi apa yang wajib dimasukkan?\\
	...................................................................................................................................\\
	...................................................................................................................................\\
	...................................................................................................................................\\
	...................................................................................................................................\\
	...................................................................................................................................\\
	
	\noindent 9. Menurut anda, apa yang perlu diperbaiki pada user interface yang sekarang telah tersedia?\\
	...................................................................................................................................\\
	...................................................................................................................................\\
	...................................................................................................................................\\
	...................................................................................................................................\\
	...................................................................................................................................\\
	
	\noindent 10. Menurut anda, apa yang perlu ditambahkan pada user interface untuk selanjutnya (selain Display/Touchscreen)?\\
	...................................................................................................................................\\
	...................................................................................................................................\\
	...................................................................................................................................\\
	...................................................................................................................................\\
	...................................................................................................................................\\
	
\end{document}

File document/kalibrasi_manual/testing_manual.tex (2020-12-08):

\documentclass[12pt,]{article}
\usepackage[utf8]{inputenc}
\usepackage[T1]{fontenc}
\usepackage{mathptmx}
\usepackage{geometry}
\usepackage{mathtools}
\usepackage[english]{babel}
\usepackage{graphicx}
\usepackage{stackengine}
\usepackage[os=win]{menukeys}
\usepackage{hyperref}
\usepackage{minted}
\usepackage{xcolor}
\usepackage{tikz}
\usepackage[yyyymmdd,hhmmss]{datetime}
\usepackage{etoolbox}
\usepackage[inline]{enumitem}

\newcommand{\WindowsLogo}{\raisebox{-0.1em}{}}
%\newcommand{\PowerLogo}{\raisebox{-0.1em}{\includegraphics[height=0.8em]{images/logo/power}}}
\newcommand{\WinKey}{\keys{\WindowsLogo}}	
\newcommand{\PowerKey}{\keys{\PowerLogo}}	

\patchcmd{\thebibliography}{\section*{\refname}}{}{}{}

\newcommand{\ShowOsVersion}{
	\immediate\write18{\unexpanded{foo=`uname -sro` && echo "${foo}" > tmp.tex}}
	\input{tmp}\immediate\write18{rm tmp.tex}
}

\newcommand{\ShowTexVersion}{
	\immediate\write18{\unexpanded{foo=`pdflatex -version | head -n1 | cut -d' ' -f1,2` && echo "${foo}" > tmp.tex}}
	\input{tmp}\immediate\write18{rm tmp.tex}
}

\addto\captionsenglish{\renewcommand{\contentsname}{Daftar Isi}}
\addto\captionsenglish{\renewcommand{\figurename}{Gambar}}

\hypersetup{
	colorlinks=true, %set true if you want colored links
	linktoc=all,     %set to all if you want both sections and subsections linked
	linkcolor=blue,  %choose some color if you want links to stand out
	urlcolor=blue,	 %url color
}

\geometry{
	a4paper,
	left=15mm,
	right=10mm,
	top=10mm,
	bottom=15mm,
}

\title{\LARGE \bf
	Panduan Ringkas Pengujian\\
	\small{(Handheld Audiometri Prototype)}
}

\author{Achmadi ST MT}

\date{}

\hypersetup{citecolor=black}

\definecolor{LightGray}{gray}{0.95}

%\pagecolor[rgb]{0.1,0.1,0.1}
%\color[rgb]{1,1,1}

\begin{document}
	\thispagestyle{empty}
	
	\begin{titlepage}
		\centering
		\vfill
		\vfill
		\maketitle
		\vfill
		
		\vfill
		\vfill
		Update: {\today} \currenttime \\
	\end{titlepage}
	
	%%%%%%%%%%%%%%%%%%%%%%%%%%%%%%%%%%%%%%%%%%%%%%%%%%%%%%%%%%%%%%%%%
	
	\newpage
	\tableofcontents
	
	%%%%%%%%%%%%%%%%%%%%%%%%%%%%%%%%%%%%%%%%%%%%%%%%%%%%%%%%%%%%%%%%%
	
	\newpage
	\section{Pendahuluan}
	
	\subsection{Tujuan}
	
	Tujuan dari kegiatan pengujian adalah mendapatkan nilai aktual SPL (dalam dB) yang dapat dibangkitan
	oleh unit protoype audiometri yang dibangun pada setiap kombinasi frekuensi dan skala amplitudo yang disiapkan.
	Pengujian ini membutuhkan \textit{un-echoic} untuk bisa mendapatkan nilai aktual pada SPL rendah tanpa tercampur gangguan lingkungan
	
	Hasil pengujian ini diharapkan dapat menjadi acuan dalam pengembangan prototype dan standarisasi sebelum digunakan massal.
	
	\newpage
	\section{Panduan}
	
	\subsection{Persiapan}
	
	\subsubsection{Hardware}
	
	Berikut adalah perangkat keras yang perlu disiapkan untuk pengujian ini:
	\begin{enumerate}
		\item Unit Prototype Audiometri yang akan diuji.
		\begin{figure}[!ht]
			\centering
			
			\caption{Unit Prototype}
		\end{figure}
	
		\item Kabel Micro-USB ke USB-A.
		\begin{figure}[!ht]
			\centering
			
			\caption{Kabel USB}
		\end{figure}
	
		\item Wired-Headphone dengan impedansi tiap channel antara $32\Omega$ hingga $300\Omega$
		\begin{figure}[!ht]
			\centering
			
			\caption{Wired Headphone}
		\end{figure}
	
		\newpage
		\item Setup Uji KEMAR dan telah terkalibrasi.\\
		\textbf{Catatan}: Diasumsikan bahwa operator telah cukup familiar dalam detil teknis persiapan 
		maupun penggunaan unit uji KEMAR.
		\begin{figure}[!ht]
			\centering
			
			\caption{Setup Kemar}
		\end{figure}
		
	\end{enumerate}

	\subsubsection{Software: Windows}
	
	Berikut adalah perangkat lunak yang perlu disiapkan untuk pengujian ini
	(panduan ini menggunakan Windows-7 32-bit sebagai contoh):
	
	\begin{enumerate}
		\item Install driver ARM USB-CDC.\\
		Untuk dapat menghubungkan unit prototype dengan komputer,
		diperlukan driver ARM USB-CDC untuk komunikasi serial.
		
		\begin{itemize}
			\item File installer (sesuaikan dengan bit OS).
			Dapat didownload di \url{http://intip.in/stm32tools}
			\begin{figure}[!ht]
				\centering
				
				\caption{Installer Driver}
			\end{figure}
		
			\item Instalasi driver (tanpa unit prototype terhubung) cukup mudah sebagaimana umumnya.
			\begin{figure}[!ht]
				\centering
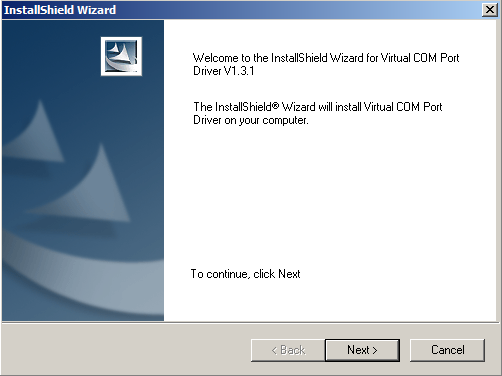
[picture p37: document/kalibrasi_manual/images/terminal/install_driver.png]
				
				\caption{Mulai instal driver}
			\end{figure}
		\end{itemize}
		
		\newpage
		\item Nyalakan dan hubungkan unit ke komputer.\\
		
		Berikut langkah-langkahnya:
		\begin{itemize}
			\item Hidupkan dengan switch pada sisi samping casing.
			\begin{figure}[!ht]
				\centering
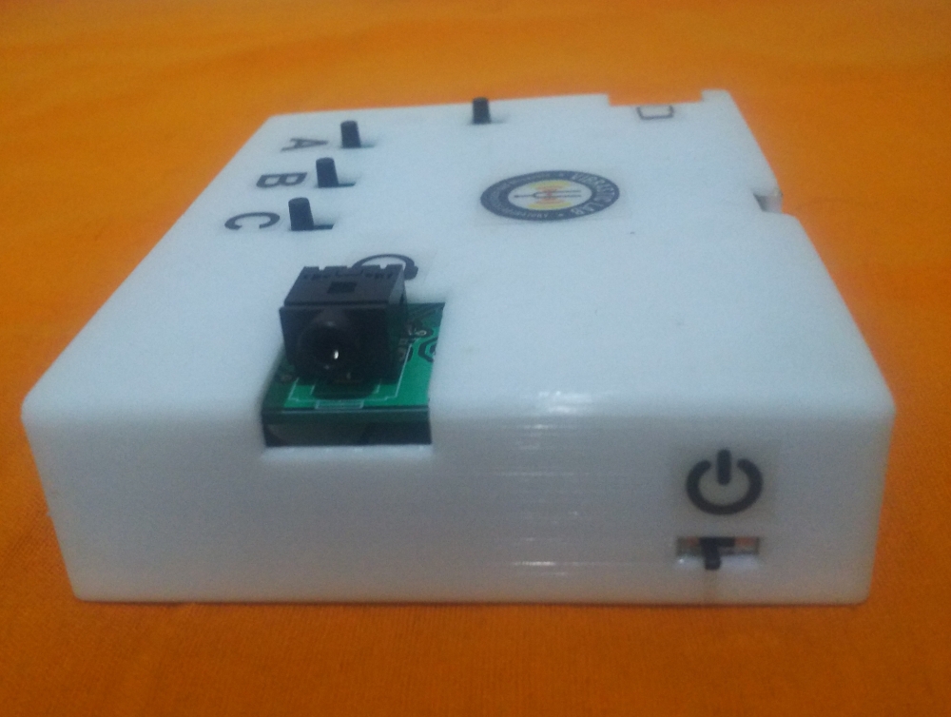
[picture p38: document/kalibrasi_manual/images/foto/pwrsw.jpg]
				
				\caption{Power Switch}
			\end{figure}
		
			\item Tunggu hingga LED biru, hijau, dan merah menyala
			bergantian sebagai tanda unit sudah standby
			
			\begin{figure}[!ht]
				\centering
				
				\caption{Unit Standby}
			\end{figure}
		
			\item Sambungkan unit prototype dengan komputer via kabel USB.
			
			\begin{figure}[!ht]
				\centering
				
				\caption{Konek Kabel USB}
			\end{figure}
			
		\end{itemize}
	
		\newpage
		\item Tunggu hingga driver selesai mengkonfigurasi otomatis
		
		\item Cek \textit{Device Manager} untuk mengetahui Nomor Serial-Port
		\begin{itemize}
			\item Buka run-command dialog dengan kombinasi keyboard (\keys{\WinKey + r})
			
			\item masukkan perintah \textbf{devmgmt.msc}.
			\begin{figure}[!ht]
				\centering
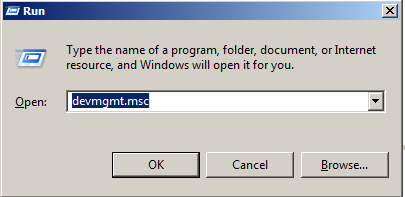
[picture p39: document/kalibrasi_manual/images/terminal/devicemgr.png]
				
				\caption{Memanggil Device Manager}
			\end{figure}
			
			\item Tekan (\keys{\return}) atau klik OK
			
			\item Cari entry \textit{Ports (COM and LPT)}.
			Catat nomor port untuk entry \textit{STMicroelectronics Virtual COM Port}.
			Dalam contoh ini, terkonfigurasi pada COM3.
			
			\begin{figure}[!ht]
				\centering
				
				\caption{Serial Komunikasi pada COM3}
			\end{figure}
		\end{itemize}
	
		\item Install Serial Terminal.
		Untuk dapat berkomunikasi via serial port, perlu diinstall serial terminal.
		Disini dicontohkan menggunakan \textit{Hercules}.
		
		\begin{itemize}
			\item Program terminal Hercules. Dapat didownload di \url{http://intip.in/stm32tools}
			\begin{figure}[!ht]
				\centering
				
				\caption{Hercules Terminal}
			\end{figure}
		
			\item Jalankan program Hercules.
			Jika muncul konfirmasi lisensi, cukup \textit{Close} saja.
			
			\item Pilih tab \textit{Serial}.
			\begin{figure}[!ht]
				\centering
				
				\caption{Serial Terminal}
			\end{figure}
			
		\end{itemize}
	
		\newpage
		\item Test Komunikasi Serial
		\begin{itemize}
			\item Hercules Serial Terminal
			\begin{figure}[!ht]
				\centering
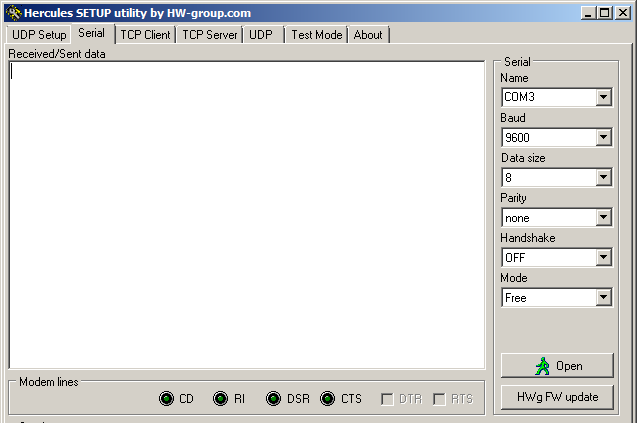
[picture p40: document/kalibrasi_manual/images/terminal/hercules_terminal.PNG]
				
				\caption{Hercules Serial Terminal}
			\end{figure}
		
			\item Setting Port pada Serial Terminal sebagai berikut
			\begin{itemize}
				\item Name     : COM3
				\item Baud     : 9600
				\item Data size: 8
				\item Parity   : none
			\end{itemize}
		
			\begin{figure}[!ht]
				\centering
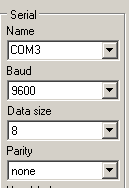
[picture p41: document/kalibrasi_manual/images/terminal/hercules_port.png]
				
				\caption{Pengaturan serial port}
			\end{figure}
		
			\item Klik Open (pastikan unit prototype sudah standby dan terhubung
			serta nama COM port sudah sesuai)
			
			\begin{figure}[!ht]
				\centering
				
				\caption{Open Serial Port}
			\end{figure}
			
			\item Kolom terminal akan menampilkan pesan:
			\begin{minted}[frame=lines,framesep=2mm,fontsize=\small]{text}
Serial port COM3 opened
			\end{minted}
			
			\newpage
			\item Selanjutnya, pada kolom terminal,
			masukkan perintah berikut dan diakhiri dengan (\keys{\return})
			\begin{minted}[frame=lines,framesep=2mm,fontsize=\small]{text}
info
			\end{minted}
			Serial akan menampilkan informasi kernel dan platform
			\begin{figure}[!ht]
				\centering
				
				\caption{Informasi Platform}
			\end{figure}
		\end{itemize}
	\end{enumerate}

	\subsubsection{Audio Analyzer}
	
	Untuk perangkat lunak Audio Analyzer, digunakan program \textit{Real-Time Analyzer} 
	yang merupakan bagian dari paket software DSFF3 buatan Yoshimasha.
	Jika membutuhkan versi trial dapat didownload di \url{http://intip.in/stm32tools}.
	
	Antar-muka Real-Time Analyzer yang digunakan adalah \textit{FFT-Analyzer} pada tab \textit{Octave band}.
	
	\begin{figure}[!ht]
		\centering
		
		\caption{Octave band pada FFT analyzer}
	\end{figure}

	Pada tampilan Octave-Band, klik satu bar frekuensi untuk mengetahui nilai SPL (dB)
	yang terisolasi dengan frekuensi lain.
	
	\newpage
	\subsubsection{Test Tone-Generation}
	Berikut adalah prosedur untuk mencoba \textit{tone-generation}:
	\begin{enumerate}
		\item Nyalakan unit prototype dan tunggu standby.
		Pastikan USB belum terhubung ke komputer.
		\item Sambungkan unit dengan headphone yang disiapkan
		\item Sambungkan USB ke komputer
		\item Cek nomor COM port pada Device manager
		\item Jalankan Hercules terminal
		\item Atur nama port sesuai COM port
		\item Klik \textbf{Open} pada Hercules terminal
		\item Masukkan perintah berikut:
		\begin{minted}[frame=lines,framesep=2mm,fontsize=\small]{text}
out 500 5
		\end{minted}
		\item Setelah tekan (\keys{\return}), maka pada salah satu headphone
		akan membangkitkan tone selama kurang lebih 5detik.
		\item Jika setelah selesai, tekan \textbf{Close} pada terminal,
		lepas USB, dan matikan unit prototype.

	\end{enumerate}

	\subsubsection{Perintah yang Tersedia}
	
	Berikut beberapa perintah yang dapat diinputkan ke unit prototype:
	
	\begin{itemize}
		\item \textbf{test}.
		Perintah ini untuk mencoba headphone dengan mengeluakan tone singkat kanan-kiri bergantian.
		Perintahnya adalah (diakhiri (\keys{\return})):
		\begin{minted}[frame=lines,framesep=2mm,fontsize=\small]{text}
test
		\end{minted}
		
		\item \textbf{info}.
		Perintah ini untuk menampilkan informasi platform.
		Dapat digunakan sebagai perintah uji untuk melihat serial dan chip sudah berkerja atau tidak.
		Perintahnya adalah (diakhiri (\keys{\return})):
		\begin{minted}[frame=lines,framesep=2mm,fontsize=\small]{text}
info
		\end{minted}
		
		\item \textbf{out}.
		Perintah untuk membangkitkan tone dengan frekuensi dan skala yang diinginkan selama 5detik.
		Perintah adalah perintah utama dalam proses pengujian ini.
		Pola perintahnya adalah (diakhiri (\keys{\return})):
		\begin{minted}[frame=lines,framesep=2mm,fontsize=\small]{text}
out <frekuensi> <amplitudo>
		\end{minted}
		dengan:
		\begin{itemize}
			\item frekuensi adalah nilai frekuensi (dalam Hz) antara 250 sampai 16000.
			\item amplitudo adalah skala amplitudo antara 1 sampai 9
		\end{itemize}
		Contoh untuk tone 500Hz pada skala amplitudo 6 (diakhiri (\keys{\return})):
		\begin{minted}[frame=lines,framesep=2mm,fontsize=\small]{text}
out 500 6
		\end{minted}
	\end{itemize}

	\newpage
	\subsubsection{Troubleshoot}
	
	Berikut beberapa masalah yang terkadang sering muncul:
	\begin{enumerate}
		\item Perintah serial tidak merespon apapun kecuali hanya menampilkan prompt seperti:
		\begin{minted}[frame=lines,framesep=2mm,fontsize=\small]{text}
ch>
		\end{minted}
		Ini bukanlah masalah melainkan hanya respon saat baru selesai startup.
		Solusinya cukup masukkan perintah yang diinginkan sekali lagi.
		
		\item Serial USB tidak terdaftar pada \textit{Device-Manager}.\\
		Kemungkinan sumber masalah:
		\begin{itemize}
			\item Kabel USB tidak tersambung baik atau tidak menyediakan jalur data D+/D-.\\
			\textbf{Solusi}: ganti kabel USB
			
			\item Kabel USB terhubung ke komputer sebelum unit nyala dan standby.\\
			\textbf{Solusi}: lepas kabel USB dari komputer kemudian matikan dan nyalakan ulang unit.
			Setelah standby maka baru disambungkan ke komputer.
		\end{itemize}
	
		\item Unit prototype frezze atau hank.\\
		Ditandai dengan LED yang tidak lagi berkedip bergantian atau perintah serial tidak lagi merespon.\\
		Kemungkinan sumber masalah adalah kondisi \textit{race} pada threading dan interrupt.\\
		\textbf{Solusi}: lepas kabel USB dari komputer kemudian matikan dan nyalakan ulang unit.
		Setelah standby maka baru disambungkan ke komputer.
	\end{enumerate}

	\subsubsection{Charging}
	
	Tersedia fitur battery \textit{charging} pada unit prototype.
	Untuk \textit{charging}, cukup dibutuhkan charger android 5volt dan kabel microUSB ke USB.
	\begin{figure}[!ht]
		\centering
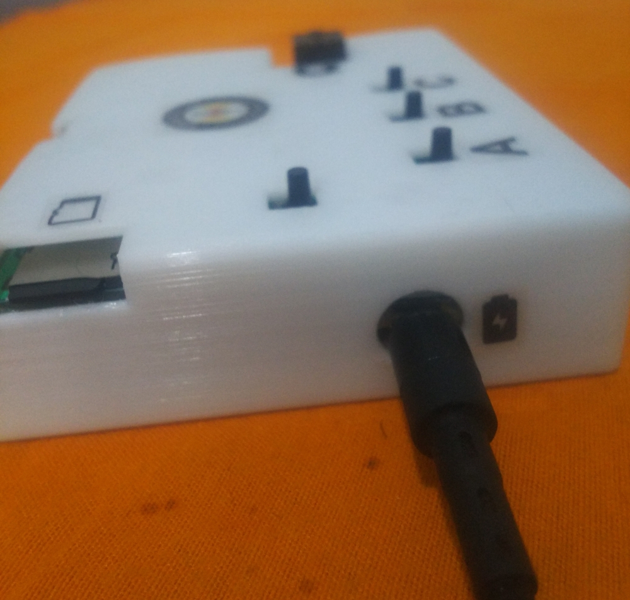
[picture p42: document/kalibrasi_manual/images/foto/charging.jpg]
		
		\caption{Port untuk charging}
	\end{figure}

	Berikut prosedur charging:
	\begin{enumerate}
		\item Pastikan unit dalam kondisi mati
		\item Hubungkan USB dengan charger 5 volt yang telah terhubung sumber AC
		\item LED merah dekat port charger akan menyala sebagai tanda proses charging berjalan
		\item Tunggu LED merah berganti biru sebagai tanda charging selesai
	\end{enumerate}

	\newpage
	\subsection{Pengujian}
	
	\subsubsection{Hasil}
	
	Hasil yang diharapkan adalah tabel SPL (dB) untuk setiap matrik frekuensi dan skala amplitudo.
	Dengan hasil tabel ini maka diharapkan ada acuan untuk pengaturan unit prototype sesuai standar yang digunakan pada nantinya.
	
	Berikut contoh tabel yang diharapkan:
	
	\begin{center}
		\begin{tabular}{|c|c|c|c|c|c|c|c|c|c|} 
			\hline
			Fq/Ap & 9 & 8 & 7 & 6 & 5 & 4 & 3 & 2 & 1\\ [0.5ex] 
			\hline\hline
			250Hz & X dB & X dB & X dB & X dB & X dB & X dB & X dB & X dB & X dB\\
			\hline
			500Hz & X dB & X dB & X dB & X dB & X dB & X dB & X dB & X dB & X dB\\
			\hline
			1000Hz & X dB & X dB & X dB & X dB & X dB & X dB & X dB & X dB & X dB\\
			\hline
			2000Hz & X dB & X dB & X dB & X dB & X dB & X dB & X dB & X dB & X dB\\
			\hline
			4000Hz & X dB & X dB & X dB & X dB & X dB & X dB & X dB & X dB & X dB\\
			\hline
			8000Hz & X dB & X dB & X dB & X dB & X dB & X dB & X dB & X dB & X dB\\
			\hline
			16000Hz & X dB & X dB & X dB & X dB & X dB & X dB & X dB & X dB & X dB\\
			\hline
		\end{tabular}
	\end{center}
	
	Tabel dalam format Excel 2003 (xls) dapat didownload di \url{https://intip.in/UjiAudiometri}
	
	\subsubsection{Perintah Serial}
	
	Perintah serial yang digunakan sebagaimana telah dijelaskan pada bab sebelumnya adalah perintah \textbf{out},
	dengan pola perintah:
	\begin{minted}[frame=lines,framesep=2mm,fontsize=\small]{text}
out <frekuensi> <amplitudo>
	\end{minted}
	dengan:
	\begin{itemize}
		\item frekuensi adalah nilai frekuensi (dalam Hz) antara 250 sampai 16000.
		\item amplitudo adalah skala amplitudo antara 1 sampai 9
	\end{itemize}

	\newpage
	\subsubsection{Contoh Prosedur}
	
	Berikut adalah contoh prosedur untuk satu nilai uji pada satu frekuensi dan satu skala amplitudo.
	Sebagai contoh adalah frekuensi 1000Hz pada skala amplitudo 6.
	Sebelum pengujian, kembali cek ulang persiapan meliputi:
	\begin{itemize}
		\item Unit prototype telah standby dan terhubung laptop via USB.
		\item Serial terminal telah bisa mengirim perintah dan mendapat respon.
		\item Headphone telah terpasang ke unit uji KEMAR dan terhubung unit prototype.
		\item Komputer dan unit KEMAR sudah terhubung dengan Audio Capture Device.
		\item Real-Time Analyzer pada window FFT Octave-band telah terkalibrasi dan sudah start.
	\end{itemize}

	Berikut contoh prosedur satu nilai:
	\begin{enumerate}
		\item masukkan perintah tone untuk nilai frekuensi dan skala amplitudo yang ditentukan.
		Contoh (1000Hz skala 6):
		\begin{minted}[frame=lines,framesep=2mm,fontsize=\small]{text}
out 1000 6
		\end{minted}
		
		\item Tone akan dibangkitkan selama 5detik.
		
		\item Pada window Octave-band, klik bar pada frekuensi 1000Hz.
		
			\begin{figure}[!ht]
			\centering
			
			\caption{Contoh Nilai Uji}
		\end{figure}
	
		Terlihat bahwa nilai hasil uji adalah 49.95 dB (atau 50dB).\\
		\textbf{Catatan}: Contoh gambar di atas dilakukan pada ruangan biasa dengan penuh gangguan.
		
		\item Catat nilai SPL tersebut pada tabel Hasil sesuai frekuensi dan skala amplitudo
		
		\item Setelah 5detik, tone akan berhenti.
		
		\item Pengujian dapat dilanjutkan pada kombinasi frekuensi dan skala amplitudo lainnya.
	\end{enumerate}
	
\end{document}

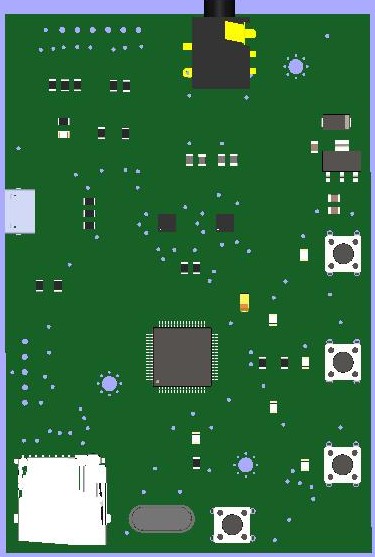
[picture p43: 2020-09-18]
document/quick_usage/images/layout_ori.jpg

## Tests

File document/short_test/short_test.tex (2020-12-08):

\documentclass[12pt,]{article}
\usepackage[utf8]{inputenc}
\usepackage[T1]{fontenc}
\usepackage{mathptmx}
\usepackage{geometry}
\usepackage{mathtools}
\usepackage[english]{babel}
\usepackage{graphicx}
\usepackage{stackengine}
\usepackage[os=win]{menukeys}
\usepackage{hyperref}
\usepackage{minted}
\usepackage{xcolor}
\usepackage{tikz}
\usepackage[yyyymmdd,hhmmss]{datetime}
\usepackage{etoolbox}
\usepackage[inline]{enumitem}

\newcommand{\WindowsLogo}{\raisebox{-0.1em}{}}
%\newcommand{\PowerLogo}{\raisebox{-0.1em}{\includegraphics[height=0.8em]{images/logo/power}}}
\newcommand{\WinKey}{\keys{\WindowsLogo}}	
\newcommand{\PowerKey}{\keys{\PowerLogo}}	

\patchcmd{\thebibliography}{\section*{\refname}}{}{}{}

\newcommand{\ShowOsVersion}{
	\immediate\write18{\unexpanded{foo=`uname -sro` && echo "${foo}" > tmp.tex}}
	\input{tmp}\immediate\write18{rm tmp.tex}
}

\newcommand{\ShowTexVersion}{
	\immediate\write18{\unexpanded{foo=`pdflatex -version | head -n1 | cut -d' ' -f1,2` && echo "${foo}" > tmp.tex}}
	\input{tmp}\immediate\write18{rm tmp.tex}
}

\addto\captionsenglish{\renewcommand{\contentsname}{Daftar Isi}}
\addto\captionsenglish{\renewcommand{\figurename}{Gambar}}

\hypersetup{
	colorlinks=true, %set true if you want colored links
	linktoc=all,     %set to all if you want both sections and subsections linked
	linkcolor=blue,  %choose some color if you want links to stand out
	urlcolor=blue,	 %url color
}

\geometry{
	a4paper,
	left=15mm,
	right=10mm,
	top=10mm,
	bottom=15mm,
}

\title{\LARGE \bf
	Laporan Singkat\\
	\small{(Microcomputer Audiometri Prototype)}
}

\author{Achmadi ST MT}

\date{}

\hypersetup{citecolor=black}

\definecolor{LightGray}{gray}{0.95}

%\pagecolor[rgb]{0.1,0.1,0.1}
%\color[rgb]{1,1,1}

\begin{document}
	\thispagestyle{empty}
	
	\begin{titlepage}
		\centering
		\vfill
		\vfill
		\maketitle
		\vfill
		
		\vfill
		\vfill
		Update: {\today} \currenttime \\
	\end{titlepage}
	
	%%%%%%%%%%%%%%%%%%%%%%%%%%%%%%%%%%%%%%%%%%%%%%%%%%%%%%%%%%%%%%%%%
	
	\section{Setup}
	
	\subsection{Unit Prototype}
	
	Unit prototype terdiri atas:
	\begin{itemize}
		\item Raspberry-Pi versi 3-B
		\begin{figure}[!ht]
			\centering
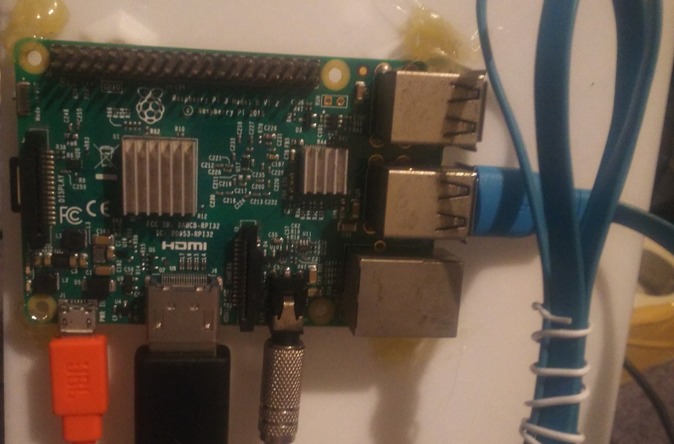
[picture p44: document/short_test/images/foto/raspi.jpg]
			
			\caption{RPi-3B}
		\end{figure}
		\item Waveshare LCD-TFT HDMI tipe C
		\begin{figure}[!ht]
			\centering
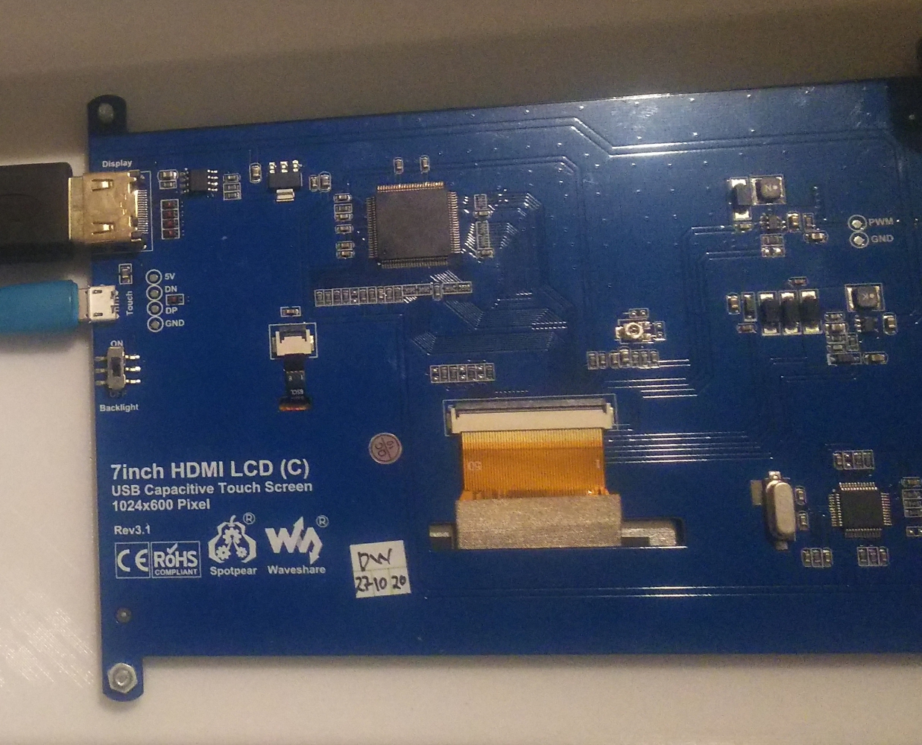
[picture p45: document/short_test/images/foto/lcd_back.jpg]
			
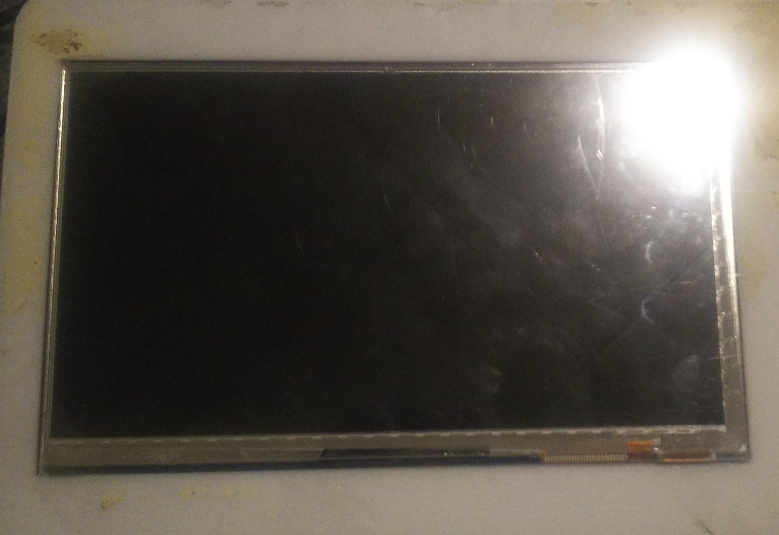
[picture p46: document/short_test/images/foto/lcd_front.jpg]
			
			\caption{LCD-TFT: (kiri) panel belakang dan (kanan) panel depan}
		\end{figure}
	\end{itemize}
	
	\newpage
	\subsection{Software}
	
	\subsubsection{Software Dasar}
	
	Software dasar yang digunakan adalah Pychoacoustics Lab yang \textit{source-tree} tersedia di:\\
	\url{https://github.com/sam81/pychoacoustics}
	
	Instalasi untuk Pacman-based Linux tersedia di:\\
	\url{https://github.com/mekatronik-achmadi/archmate-pkgbuild/tree/master/pychoacoustic}
	
	\begin{figure}[!ht]
		\centering
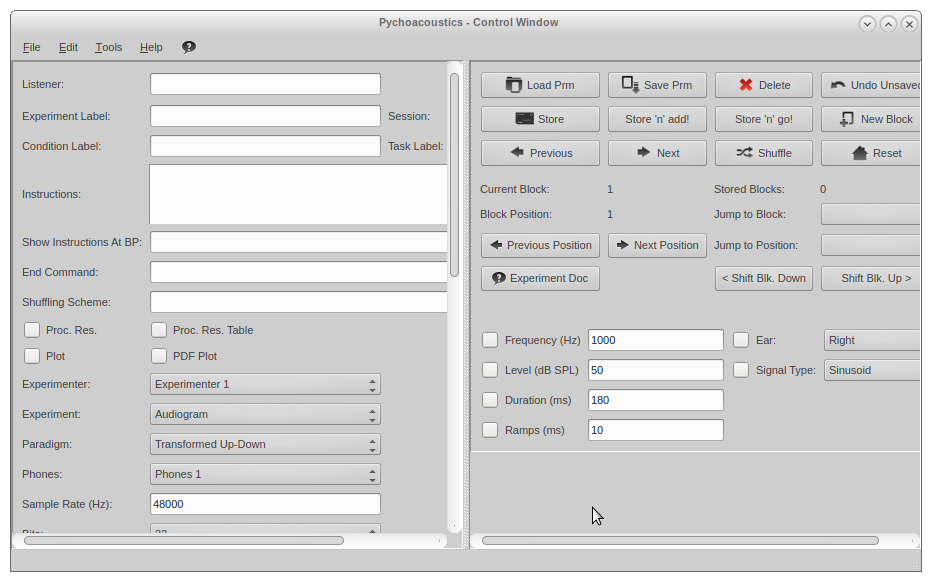
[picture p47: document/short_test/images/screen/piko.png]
		
		\caption{Pychoacoustics}
	\end{figure}

	\subsubsection{Software Uji}
	
	Untuk pengujian, digunakan dialog tone-generator yang menggunakan pustaka Python yang sama dengan software Pychoacoustics.
	
	Python Class dapat ditemukan di \url{https://github.com/VibrasticLab/pikoakustik/blob/stm32f401re_3pin/archlinuxarm/dialogPhones.py}.
	
	Dan skrip running dapat ditemukan di \url{https://github.com/VibrasticLab/pikoakustik/blob/stm32f401re_3pin/archlinuxarm/pychophone.py}
	
	\begin{figure}[!ht]
		\centering
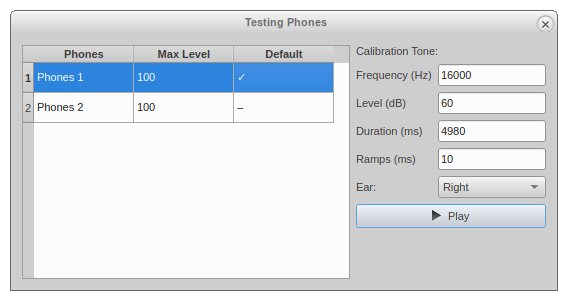
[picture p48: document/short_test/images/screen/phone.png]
		
		\caption{Dialog Tone-Generator}
	\end{figure}

	Pengaturan yang digunakan:
	\begin{itemize}
		\item Volume unit diatur maximal: Untuk sistem Linux yang menggunakan Pulseaudio-Alsa sebagai audio server, dapat menggunakan perintah:
		\begin{minted}[frame=lines,framesep=2mm,fontsize=\small]{text}
pactl set-default-sink alsa_output.platform-bcm2835_audio.stereo-fallback.2
pactl set-sink-volume @DEFAULT_SINK@ 100%
		\end{minted}
		
		\item Durasi 4980 ms. Sehingga dengan ditambah ramp di awal dan akhir sebesar 10ms, maka total menjadi 5 detik
		
		\item Frekuensi (dalam Hz) diurut mulai 250, 500, 1000, 2000, 4000, 8000, dan 16000.
		
		\item Level (dalam dB) untuk setiap frekuensi diurut mulai 90, 80, 70, 60, 50, 40, dan 30.
	\end{itemize}

	\newpage
	\subsection{Eksperimen}
	
	Berikut penjelasan setup eksperimen:
	
	\begin{itemize}
		\item Microphone yang digunakan adalah merek dBX.
		\item Headphone yang digunakan adalah Miniso dan BOSE.
		\begin{figure}[!ht]
			\centering
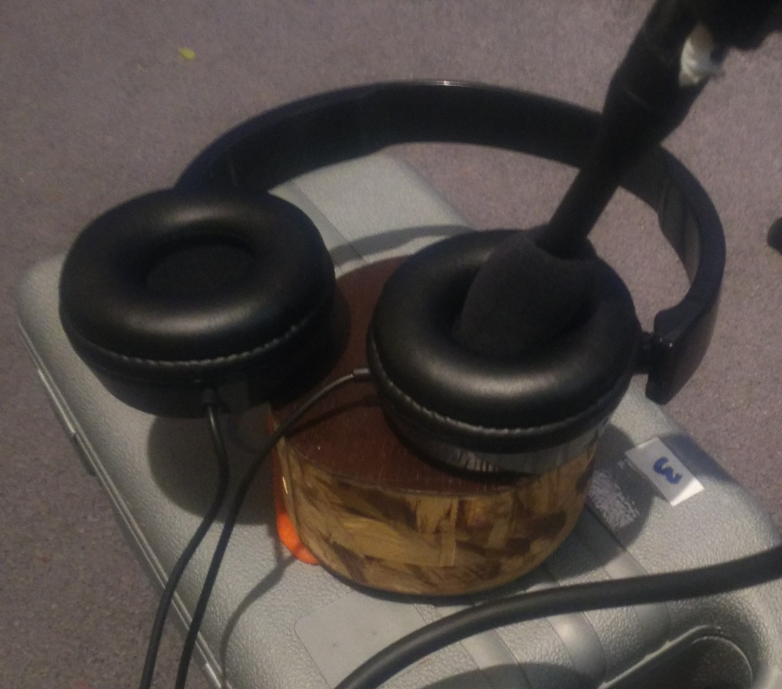
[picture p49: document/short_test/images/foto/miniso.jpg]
			
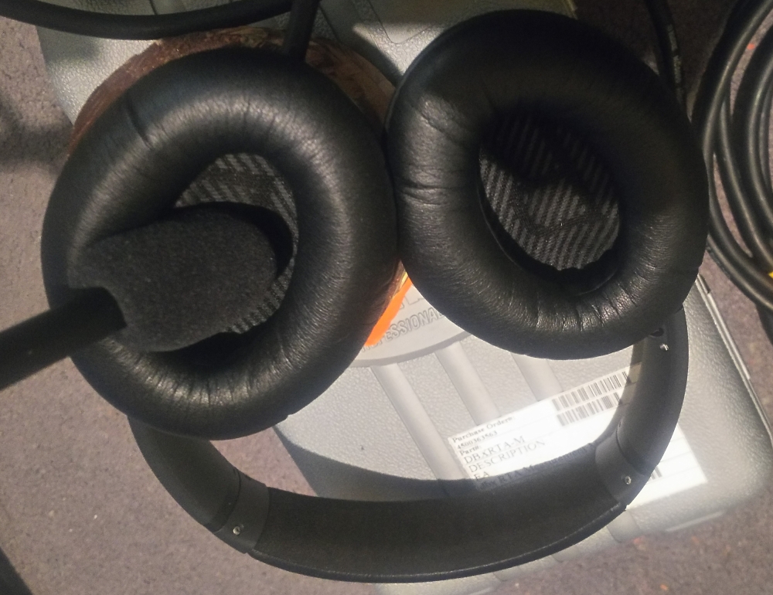
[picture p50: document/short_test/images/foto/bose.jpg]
			
			\caption{Headphone: (kiri) Miniso dan (kanan) BOSE}
		\end{figure}
		\item Audio Capture Device menggunakan Focusrite Scarlett 18i8.
		Input Gain diatur maximum.
		\begin{figure}[!ht]
			\centering
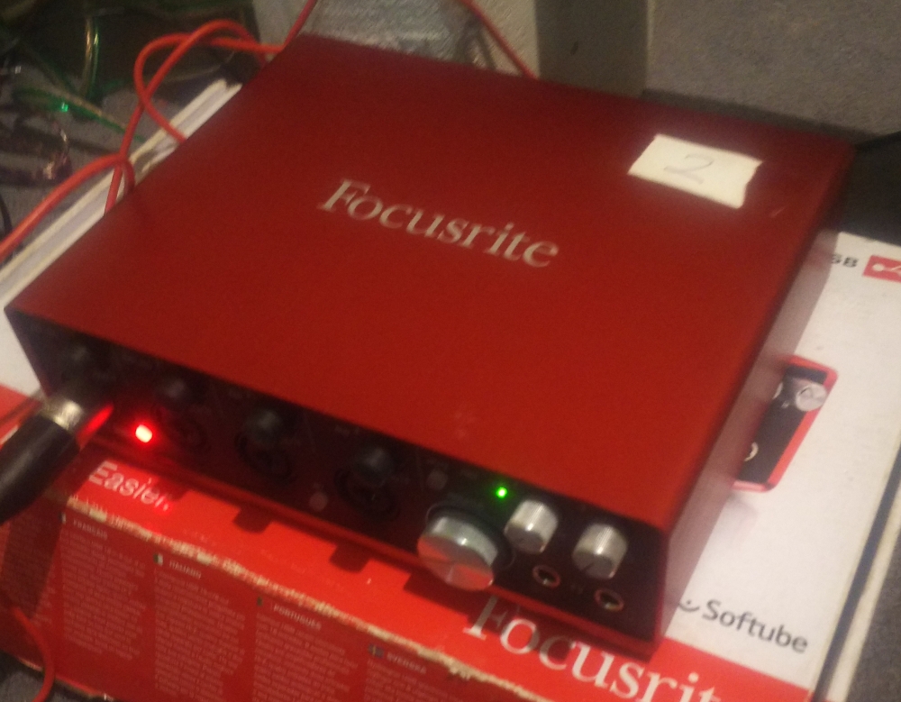
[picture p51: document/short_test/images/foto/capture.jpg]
			
			\caption{Scarlett 18i8}
		\end{figure}
	
		\item Software Capture menggunakan Real-Time Analyzer DSSF3 buatan Yoshimasha.
		Fungsi yang digunakan adalah FFT-Analyzer dengan A-weighting.
		
	\end{itemize}

	\subsection{Matrix Hasil yang diharapkan}
	
	Matrix hasil yang diharap dari hasil pengujian adalah nilai aktual (dalam SPL dB) sebagai berikut:
	
	\begin{center}
		\begin{tabular}{|c|c|c|c|c|c|c|c|} 
			\hline
			Fq/Ap & 90dB & 80dB & 70dB & 60dB & 50dB & 40dB & 30dB\\ [0.5ex] 
			\hline\hline
			250Hz & X dB & X dB & X dB & X dB & X dB & X dB & X dB \\
			\hline
			500Hz & X dB & X dB & X dB & X dB & X dB & X dB & X dB \\
			\hline
			1000Hz & X dB & X dB & X dB & X dB & X dB & X dB & X dB \\
			\hline
			2000Hz & X dB & X dB & X dB & X dB & X dB & X dB & X dB \\
			\hline
			4000Hz & X dB & X dB & X dB & X dB & X dB & X dB & X dB \\
			\hline
			8000Hz & X dB & X dB & X dB & X dB & X dB & X dB & X dB \\
			\hline
			16000Hz & X dB & X dB & X dB & X dB & X dB & X dB & X dB \\
			\hline
		\end{tabular}
	\end{center}

	\section{Hasil}
	
	\subsection{Ground Measurement}
	
	Berikut capture kondisi pengukuran tanpa \textit{tone-generation} apa pun:
	
	\begin{figure}[!ht]
		\centering
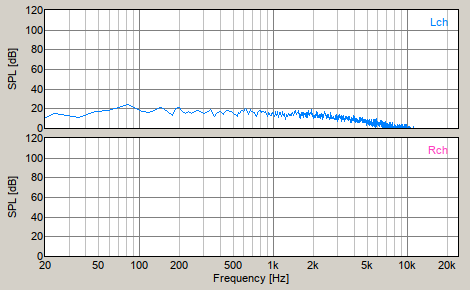
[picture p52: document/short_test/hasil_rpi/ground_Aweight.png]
		
		\caption{Ground Measurement}
	\end{figure}

	\newpage
	\subsection{Hasil Pengukuran}
	
	Berikut grafik yang ditarik dari file-file CSV hasil capture.
	Skrip Python untuk membuat grafiknya tersedia di \url{https://github.com/VibrasticLab/pikoakustik/tree/stm32f401re_3pin/document/short_test/hasil_rpi/python}
	
	\subsubsection{Miniso}
	
	Kumpulan CSV hasil pengukuran untuk headphone Miniso: \url{https://github.com/VibrasticLab/pikoakustik/tree/stm32f401re_3pin/document/short_test/hasil_rpi/miniso/}
	
	\begin{figure}[!ht]
		\centering
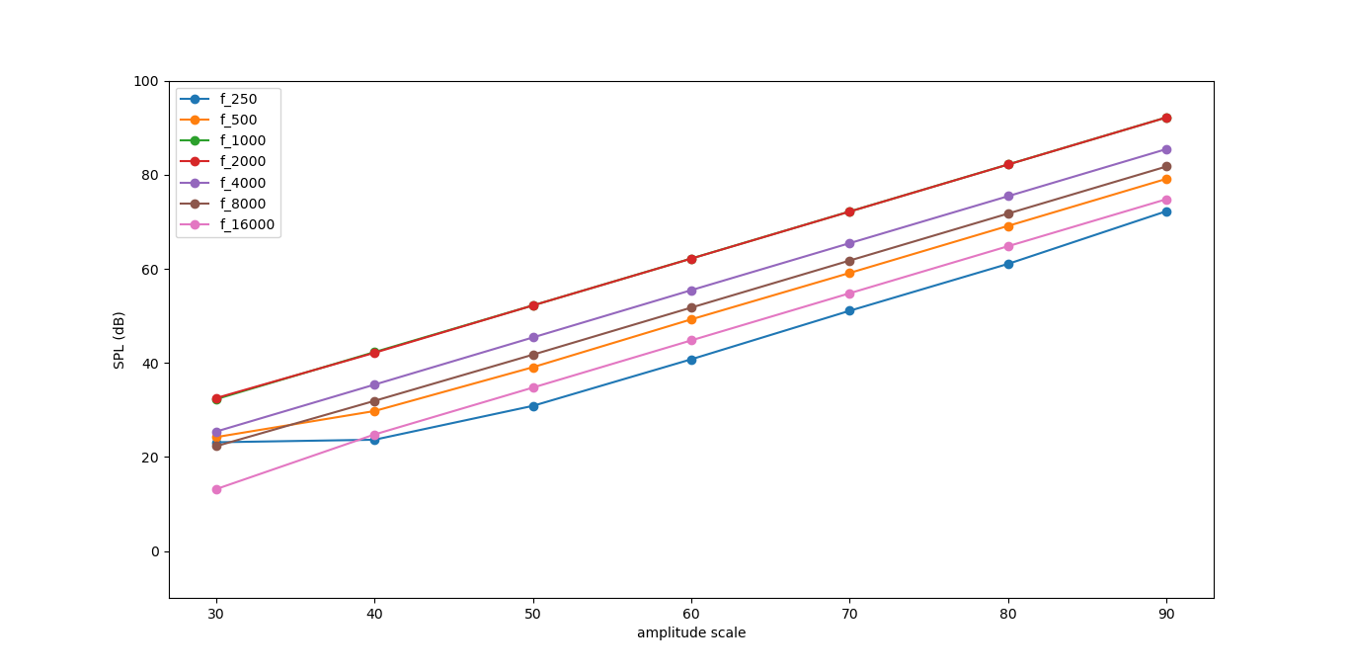
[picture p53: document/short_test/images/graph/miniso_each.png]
		
		\caption{Respon Aktual Level di setiap Frekuensi dan Level}
	\end{figure}

	\begin{figure}[!ht]
		\centering
		
		\caption{Respon maximum Level di semua Frekuensi}
	\end{figure}

	\newpage
	\subsubsection{BOSE}
	Kumpulan CSV hasil pengukuran untuk headphone BOSE: \url{https://github.com/VibrasticLab/pikoakustik/tree/stm32f401re_3pin/document/short_test/hasil_rpi/bose/}
	
	\begin{figure}[!ht]
		\centering
		
		\caption{Respon Aktual Level di setiap Frekuensi dan Level}
	\end{figure}
	
	\begin{figure}[!ht]
		\centering
		
		\caption{Respon maximum Level di semua Frekuensi}
	\end{figure}

	\newpage
	\subsubsection{Komparasi}
	
	Berikut grafik perbandingan level maximum di semua frekuensi untuk semua headphone.
	
	\begin{figure}[!ht]
		\centering
		
		\caption{Komparasi level maximum kedua headphone}
	\end{figure}
\end{document}

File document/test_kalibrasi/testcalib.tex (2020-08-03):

\documentclass[12pt,]{article}
\usepackage[utf8]{inputenc}
\usepackage[T1]{fontenc}
\usepackage{mathptmx}
\usepackage{geometry}
\usepackage{mathtools}
\usepackage[english]{babel}
\usepackage{graphicx}
\usepackage{stackengine}
\usepackage[os=win]{menukeys}
\usepackage{hyperref}
\usepackage{minted}
\usepackage{xcolor}
\usepackage{tikz}
\usepackage[yyyymmdd,hhmmss]{datetime}
\usepackage{etoolbox}

\patchcmd{\thebibliography}{\section*{\refname}}{}{}{}

\newcommand{\ShowOsVersion}{
	\immediate\write18{\unexpanded{foo=`uname -sro` && echo "${foo}" > tmp.tex}}
			\input{tmp}\immediate\write18{rm tmp.tex}
			}
			
\newcommand{\ShowTexVersion}{
			\immediate\write18{\unexpanded{foo=`pdflatex -version | head -n1 | cut -d' ' -f1,2` && echo "${foo}" > tmp.tex}}
	\input{tmp}\immediate\write18{rm tmp.tex}
}

\addto\captionsenglish{\renewcommand{\contentsname}{Daftar Isi}}

\hypersetup{
	colorlinks=true, %set true if you want colored links
	linktoc=all,     %set to all if you want both sections and subsections linked
	linkcolor=blue,  %choose some color if you want links to stand out
}

\geometry{
	legalpaper,
	left=15mm,
	right=10mm,
	top=10mm,
	bottom=15mm,
}

\title{\Large \bf
	Testing and Calibration Report\\
	\small{(Evaluation Purpose)}
}

\author{Achmadi ST MT}

\date{}

\hypersetup{citecolor=black}

%\pagecolor[rgb]{0.1,0.1,0.1}
%\color[rgb]{1,1,1}

\begin{document}
	\maketitle
	\thispagestyle{empty}
	
	\vspace*{600pt}
	\noindent This report written using: \\
	OS : \ShowOsVersion \\
	TeX : \ShowTexVersion \\
	Update: {\today} at \currenttime \\
	
	%%%%%%%%%%%%%%%%%%%%%%%%%%%%%%%%%%%%%%%%%%%%%%%%%%%%%%%%%%%%%%%%%
	
	\newpage
	\tableofcontents
	
	%%%%%%%%%%%%%%%%%%%%%%%%%%%%%%%%%%%%%%%%%%%%%%%%%%%%%%%%%%%%%%%%%
	
	\newpage
	\section{Proses Pengujian}
	
	\subsection{Persamaan}
	
	Persamaan yang digunakan untuk \textit{tone generation}:
	
	\[ Y = a.A.d.sin(2.\pi.f) \] dengan:
	\begin{itemize}
		\item \textbf{Y} adalah output sinus
		\item \textbf{a} adalah nilai atenuasi sebesar \textit{0.001}
		\item \textbf{A} adalah scaling amplitudo dari 1 hingga terkecil yang dapat didengar
		\item \textbf{d} adalah maksimum \textit{signed-32bit} positif sebesar \textit{32767}
		\item \textbf{$\pi$} adalah konstanta pi senilai \textit{3.141592653589793}
		\item \textbf(f) adalah rasio nilai antar index \textit{looping} dan panjang array.
		Panjang array berubah sesuai frekuensi yang akan dihasilkan
	\end{itemize}
	
	atau dalam format bahasa C:
	\begin{minted}[frame=lines,framesep=2mm,fontsize=\small]{c}
#define DEFAULT_ATTEN 0.01
#define I2S_BUFF_SIZE 512

uint16_t sine_gen(double freq,double ampl){
  uint16_t buffsize = (uint16_t) I2S_BUFF_SIZE/freq;	

  for(i=0;i<buffsize;i++){
    ysin = DEFAULT_ATTEN*ampl*32767*sin(2*3.141592653589793*((double)i/(double)buffsize));
  }
}
	\end{minted}
	
	Implementasinya dapat dicek ulang di URL berikut:\\
	\url{https://github.com/VibrasticLab/pikoakustik/blob/stm32f401re_3pin/firmware/ht_audio.c}
	
	\subsection{Total Audio Output}
	
	Audio DAC (Digital Analog Converter) melalui jalur I2S pada \textit{Left-Channel}.
	Sinyal Output ditentukan dalam persamaan berikut\cite{Maxim}:
	
	\[Out = In + C + G\] dengan:
	
	\begin{itemize}
		\item \textbf{Out} adalah sinyal elektrik output (dBV)
		\item \textbf{In} adalah nilai array data I2S (dBFS)
		\item \textbf{C} adalah output minimum tanpa \textit{additional gain} (dB)
		\item \textbf{G} adalah additional amplifier gain (dB) 
	\end{itemize}

	dimana nilai \textbf{In} pada 0dBFS mengacu kepada 0dBV\cite{Maxim} dan nilai G dipilih yang terkecil yaitu 3dB mengacu kepada tabel berikut\cite{Maxim}:
	
	\begin{center}
		\begin{tabular}{ |c|c|c| } 
			\hline
			Pin-GAIN & Resistor & I2S GAIN \\ 
			\hline
			GND & 100K$\Omega$ & 15 dB \\ 
			GND & 0K$\Omega$ & 12 dB \\ 
			NC & NC & 9 dB \\ 
			VDD & 0K$\Omega$ & 6 dB \\ 
			VDD & 100K$\Omega$ & 3 dB \\ 
			\hline
		\end{tabular}\\
		\hfill \break
		Tabel 1: Pengaturan pin GAIN terhadap additional gain.
	\end{center}

	\newpage
	\subsection{Output Device}
	
	Dalam pengujian ini digunakan 4 (empat) merek headphone dengan spesifikasi resistansi (bukan impedansi) sebagaimana tabel berikut:
	
	\begin{center}
		\begin{tabular}{ |c|c|c| } 
			\hline
			Merek & Resistansi & Keterangan \\ 
			\hline
			Kennion & 520 $\Omega$ & Volume Max \\ 
			\hline
			Miniso & 34 $\Omega$ & \\ 
			\hline
			Sanheiser & 320 $\Omega$ & Tercantum 300 $\Omega$ \\ 
			\hline
			Bose & Non-Direct Speaker & \\ 
			\hline
		\end{tabular}\\
		\hfill \break
	Tabel 2: Hasil ukur resistansi headphone yang akan diuji.
	\end{center}
	
	Metode pengukurannya adalah mengukur hambatan Jack TRS headphone pada pin Left-Ground (Tip-Sleeve) atau Right-Ground (Ring-Sleeve).
	Pengukuran menggunakan multimeter merek VIPER DT830B.
	
	\begin{figure}[!ht]
		\centering
		
		\caption{Ilustrasi pengukuran resistansi headphone}
	\end{figure}

	\subsection{Setup Pengujian}
	
	Setup pengujian secara ringkas adalah:
	\begin{enumerate}
		\item Microphone merek \textbf{dbx} dipasang di sisi kiri dan kanan headphone yang diuji.
		Digunakan karpet sebagai penghalang kanan-kiri.
		
		\item Jack Audio 3.5m dari headphone disambungkan ke unit Audiometri.
		Sambungkan pula kabel USB dari unit Audiometri.
		
		\item Output microphone disambungkan ke audio interface \textbf{Focusrite Scarlett 18i8}.
		Digunakan Input Gain pada nilai maximum.
		
		\item Data USB dari audio interface dihubungkan ke laptop.
		Sambungkan pula USB dari unit Audiometri ke laptop.
		
		\item Software audio interface di laptop adalah \textbf{Realtime Analyzer} versi 5.2.0.26 yang
		merupakan paket dari software \textbf{DSSF3} buatan Yoshimasha Electronic Inc.
		Pembobotan yang digunakan adalah \textbf{A-Weighting}.
		
		\item Unit Audiometri kemudian dinyalakan dengan tegangan 5v dari USB laptop.
		
		\begin{figure}[!ht]
			\centering
			
			
			
			\caption{Setup pengujian pada langkah 1, 2, dan 3}
		\end{figure}
		
		\newpage
		\item Jalankan serial terminal untuk berkomunikasi antara laptop dan unit Audiometri.
		Software serial terminal yang digunakan adalah \textbf{minicom} pada port \textit{/dev/ttyACM0} atau \textit{/dev/ttyACM1}.
		
		\item Perintah yang dikirim ke unit Audiometri untuk menjalankan fungsi \textit{tone generator}:
\begin{minted}[frame=lines,framesep=2mm,fontsize=\small]{bash}
tone <0/1> <frequency> <amplitude>
\end{minted}
		dengan:
		\begin{itemize}
			\item \textbf{0/1} adalah pilihan channel Left (\textbf{0}) atau Right (\textbf{1}).
			
			\item \textbf{frequency} adalah skala ukuran array untuk menentukan frekuensi.
			Frekuensi yang tersedia (dalam Hz) adalah \textbf{250, 500, 1000, 2000, 4000} dan \textbf{8000}.
			Skala frekuensi yang bersesuaian adalah \textbf{0.625, 1.25, 2.5, 5, 10} dan \textbf{20}.
			
			\item \textbf{amplitude} adalah skala amplitudo yang akan dikirim.
			Skala yang digunakan adalah \textbf{1, 0.5, 0.25, 0.125, 0.0625, 0.0312, 0.0156, 0.0078} dan \textbf{0.0039}.
			Nilai skala \textbf{0.0031} adalah batas minimum dimana dibawah skala itu hanya akan terdengar noise tanpa tone.
		\end{itemize}
		
		sehingga contoh perintahnya untuk tone frekuensi 500Hz dan skala amplitudo 1 di \textit{Left channel}:
\begin{minted}[frame=lines,framesep=2mm,fontsize=\small]{bash}
tone 0 1.25 1
\end{minted}

		\begin{figure}[!ht]
			\centering
			
			
			\caption{Contoh perintah dan hasil pada analyzer}
		\end{figure}
	\end{enumerate}

	\subsection{Hasil Tes}
	
	Dengan asumsi bahwa chip Audio DAC pada Left dan Right channel adalah chip yang sama,
	kemudian mendapat sinyal array I2S yang sama pula,
	maka pengujian ini dilakukan hanya pada Left Channel saja.
	
	Seluruh grafik di-\textit{generate} menggunakan skrip Python yang dapat ditemukan di:\\
	\url{https://github.com/VibrasticLab/pikoakustik/tree/stm32f401re_3pin/document/test_kalibrasi/hasil/python/graphplot.py}
	
  	\subsubsection{Miniso}
  	
  	Kumpulan data hasil uji headphone ini (format CSV) dapat ditemukan di sini:\\
  	\url{https://github.com/VibrasticLab/pikoakustik/tree/stm32f401re_3pin/document/test_kalibrasi/hasil/miniso}
  	
  	\begin{figure}[!ht]
  		\centering
  		
  		
  		\caption{headphone Miniso dengan resistansi tiap channel 34 $\Omega$}
  	\end{figure}
	
	\newpage
	\begin{figure}[!ht]
		\centering
		
		\caption{amplitudo maksimal setiap frekuensi}
	\end{figure}

	\begin{figure}[!ht]
		\centering
		
		\caption{nilai SPL tiap skala amplitudo di setiap skala frekuensi}
	\end{figure}

	\subsubsection{Kenion}
	
	Headphone merek Kenion yang digunakan disini memiliki pengaturan volume dan diatur maksimum
	
	Kumpulan data hasil uji headphone ini (format CSV) dapat ditemukan di sini:\\
	\url{https://github.com/VibrasticLab/pikoakustik/tree/stm32f401re_3pin/document/test_kalibrasi/hasil/kenion}
	
	\begin{figure}[!ht]
		\centering
		
		
		\caption{headphone Kenion dengan resistansi tiap channel 520 $\Omega$ (minimum)}
	\end{figure}
	
	\newpage
	\begin{figure}[!ht]
		\centering
		
		\caption{amplitudo maksimal setiap frekuensi}
	\end{figure}
	
	\begin{figure}[!ht]
		\centering
		
		\caption{nilai SPL tiap skala amplitudo di setiap skala frekuensi}
	\end{figure}

	\subsubsection{Senheiser}
	
	Kumpulan data hasil uji headphone ini (format CSV) dapat ditemukan di sini:\\
	\url{https://github.com/VibrasticLab/pikoakustik/tree/stm32f401re_3pin/document/test_kalibrasi/hasil/senheiser}
	
	\begin{figure}[!ht]
		\centering
		
		
		\caption{headphone Senheiser dengan resistansi tiap channel 520 $\Omega$ (minimum)}
	\end{figure}
	
	\newpage
	\begin{figure}[!ht]
		\centering
		
		\caption{amplitudo maksimal setiap frekuensi}
	\end{figure}
	
	\begin{figure}[!ht]
		\centering
		
		\caption{nilai SPL tiap skala amplitudo di setiap skala frekuensi}
	\end{figure}
	
	\subsubsection{Bose}
	
	Kumpulan data hasil uji headphone ini (format CSV) dapat ditemukan di sini:\\
	\url{https://github.com/VibrasticLab/pikoakustik/tree/stm32f401re_3pin/document/test_kalibrasi/hasil/bose}
	
	\begin{figure}[!ht]
		\centering
		
		
		\caption{headphone Bose}
	\end{figure}

	\newpage
	\begin{figure}[!ht]
		\centering
		
		\caption{amplitudo maksimal setiap frekuensi}
	\end{figure}
	
	\begin{figure}[!ht]
		\centering
		
		\caption{nilai SPL tiap skala amplitudo di setiap skala frekuensi}
	\end{figure}

	\newpage
	\section{Development}
	
	Berikut beberapa poin masalah maupun langkah pengembangan selanjutnya
	
	\subsection{Left-Right Isolation}
	
	Struktur jack audio 3.5mm secara umum untuk headphone diilustrasikan sebagai berikut:
	
	\begin{figure}[!ht]
		\centering
		
		\caption{Ilustrasi koneksi speaker ke jack audio 3.5mm}
	\end{figure}

	dan implementasi secara elektronik:
	
	\begin{figure}[!ht]
		\centering
		
		\caption{skema koneksi speaker ke chip codec}
	\end{figure}

	Chip MAX98357A pada dasarnya adalah audio codec \textbf{mono} namun mampu menerima stereo PCM.
	Sementara untuk penggunaan stereo yang direkomendasikan datasheet MAX98357A adalah \cite{Maxim}: 
	
	\begin{figure}[!ht]
		\centering
		
		\caption{skema untuk PCM stereo}
	\end{figure}

	Implimentasi untuk skema pada datasheet tidak memungkinkan mengingat pin output negatif (OUTN) pada headphone konvensional menyatu untuk channel Left dan Right.
	
	\newpage
	Dengan menyatunya output, maka terjadi fenomena "bocor" daya di-channel yang tidak diaktifkan:
	
	\begin{figure}[!ht]
		\centering
		
		\caption{bocor daya pada channel Right saat channel Left digunakan}
	\end{figure}

	Menurut datasheet MAX98357A, disediakan pin SD\_MODE untuk men-\textit{shutdown} chip yang digunakan tanpa perlu memutus daya.
	Saat kondisi shutdown, output chip codec di-set ke kondisi \textit{high-impedance} \cite{Maxim}.
	Namun dengan terdeteksi nya "bocor" daya ini maka sepertinya impedansi chip saat shutdown tidak cukup besar untuk mem-\textit{block} daya
	dari chip lain yang sedang memberi daya ke speaker.
	
	Solusi yang memungkinkan:
	\begin{itemize}
		\item Mencari dan Mengganti induktor output (L-Left dan L-Right sebagaimana pada gambar 8) ke nilai yang lebih tinggi untuk menambah impedansi chip saat shutdown.\\
		Drawbacks:
		\begin{itemize}
			\item Jika nilai terlalu tinggi, daya Pulse-Width Modulation (PWM) sebagai carrier dikhawatirkan turun drastis
			
			\item Dikhawatirkan lebih \textit{susceptible} terhadap interference dan menyebabkan noise lain.
		\end{itemize}
		Kedua drawback di atas belum teruji dan juga tidak mengacu ke referensi dokumen tertentu. Solusi ini yang saat ini sedang diusahakan.
		
		\item Mengganti chip audio codec ke stereo yang lebih advance dan digunakan secara populer di perangkat \textit{mobile}.
		Kandidat yang dipilih saat ini adalah chip MAX98090\cite{max98090} dan ADAU1373\cite{adau1373}.\\
		Drawbacks:
		\begin{itemize}
			\item Mengganti chip audio codec akan menyebabkan development mundur beberapa langkah (terutama durasi impor).
			
			\item Walaupun standar PCM I2S yang digunakan sama, namum tetap diperlukan pengujian untuk memastikan kompatibilitas (terutama pengaturan clock).
			
			\item Baik MAX98090 dan ADAU1373 tidak hanya menyediakan output PCM/I2S codec, melainkan juga input codec disertai ADC dan DAC yang bisa dikonfigurasi.
			Kedua chip ini lebih mirip seperti \textit{sound-card on chip} dibandingkan seperti \textit{simple output codec} yang saat ini telah digunakan.
			
			\item Chip ADAU1373 hanya tersedia dalam paket BGA (Ball Grid Array) dimana sepertinya manufaktur PCB lokal maupun kemampuan assembly lokal saat ini
			masih terbatas sampai QFP (TQFP/LQGP/PLCC).
			
			\item Pengujian pada laptop dan handphone yang tersedia juga tetap menunjukkan fenomena bocor serupa dengan berbeda nilai amplitudo.
		\end{itemize}

	\end{itemize}

	\subsection{Amplitude Variance}
	
	Berdasarkan grafik pada gambar 6, 9, dan 12, dapat diketahui bahwa penurunan (atenuasi) SPL memiliki pola grafik yang sama di setiap frekuensi.
	Namun berdasarkan grafik 5, 8, dan 11, dapat diketahui bahwa rentang dan maksimum SPL berbeda-beda di setiap frekuensi dan berbeda setiap merek headphone.
	
	Sehingga masalah yang perlu diperhatikan adalah:
	\begin{itemize}
		\item Apakah diperlukan rentang dan maksimum SPL sama (datar) untuk semua frekuensi?
		\item Jika benar, maka diperlukan attenuasi programmatical untuk setiap skala frekuensi (?)
		\item Jika demikian, maka nilai attenuasi yang diterapkan mengikuti grafik headphone yang mana?
	\end{itemize}
	
	\newpage
	\subsection{Lowest Amplitude}
	
	Kondisi lingkungan pengukuran yang saat ini digunakan memiliki bising setidaknya hingga 20 dB pada frekuensi 250 Hz:
	
	\begin{figure}[!ht]
		\centering
		
		\caption{Bising dasar pengukuran lingkungan (Weighting Flat)}
	\end{figure}

	Maka pada kondisi ini, semua hasil pengukuran dengan output (atau hasil grafik skrip python) pada nilai 20dB ke bawah, 
	menjadi cenderung meragukan.
	
	Sehingga masalah yang perlu diperhatikan:
	\begin{itemize}
		\item Berapa nilai standar SPL untuk audiometri di setiap frekuensi nya?
		\item Jika bernilai 20dB atau kurang, maka lingkungan pengukuran yang digunakan saat ini tidak mencukupi (?)
	\end{itemize}
	
	\subsection{Bose Compatibility}
	
	Headphone merek Bose yang tersedia saat ini memiliki perbedaan hasil ukur dibandingkan headphone lain yang telah diuji disini.
	Berikut beberapa perbedaan yang telah diketahui:
	
	\begin{enumerate}
		\item Speaker headphone tidak terhubung langsung ke jack Audio, melainkan telah melalui elektronik tambahan.
		Ini diketahui dari perbedaan resistansi antara pin Ground-Left dan Left-Ground (probe multimeter ditukar).
		
		\item Muncul tone frekuensi tinggi tambahan pada SPL rendah:
		\begin{figure}[!ht]
			\centering
			
			\caption{Tone pada 16kHz}
		\end{figure}

		\item Headphone ini satu-satunya yang mampu menghasilkan tone hingga 16kHz.
		\begin{figure}[!ht]
			\centering
			
			\caption{Tone pada 16kHz}
		\end{figure}
	\end{enumerate}
	
	\newpage
	\section{Referensi}
	\label{}
	
	\bibliographystyle{IEEEtran}
	\bibliography{/home/achmaday/Documents/BibTex/library.bib}
%	\bibliography{/home/viblab/Documents/BibTex/library.bib}	
		
\end{document}

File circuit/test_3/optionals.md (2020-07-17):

### Optional (Unsoldered) components

#### External Clock related
- Y-XTALL
- C-XTAL1
- C-XTAL2

#### Audio DAC related
- C-SN1
- C-SPL1
- C-SPR1

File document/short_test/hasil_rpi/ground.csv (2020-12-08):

FFT | Power Spectrum
Frequency[Hz] | Level-L[dB] | Level-R[dB]
11.719 | 49.149 | -5.7094
23.438 | 50.041 | -19.751
35.156 | 37.643 | -15.687
46.875 | 37.616 | -8.3392
58.594 | 34.988 | -9.7638
70.313 | 34.357 | -14.368
82.031 | 36.432 | -16.167
93.75 | 36.266 | -15.652
105.47 | 33.209 | -16.063
117.19 | 28.106 | -16.889
128.91 | 25.374 | -16.51
140.63 | 25.113 | -10.699
152.34 | 22.699 | -10.471
164.06 | 22.153 | -14.952
175.78 | 16.218 | -14.593
187.5 | 22.573 | -15.639
199.22 | 26.681 | -18.003
210.94 | 21.093 | -19.083
222.66 | 14.937 | -17.746
234.38 | 17.35 | -20.002
246.09 | 14.947 | -16.227
257.81 | 15.736 | -17.004
269.53 | 15.549 | -21.447
281.25 | 7.8383 | -22.868
292.97 | 11.307 | -23.167
304.69 | 13.543 | -21.764
316.41 | 13.293 | -20.231
328.13 | 16.007 | -18.485
339.84 | 14.131 | -16.545
351.56 | 12.873 | -16.638
363.28 | 13.515 | -18.647
375 | 15.507 | -21.107
386.72 | 17.895 | -22.778
398.44 | 17.91 | -18.02
410.16 | 16.135 | -20.448
421.88 | 17.075 | -20.464
433.59 | 16.476 | -18.901
445.31 | 16.81 | -19.653
457.03 | 12.58 | -18.508
468.75 | 11.535 | -19.819
480.47 | 9.7778 | -20.417
492.19 | 11.38 | -20.669
503.91 | 15.156 | -21.513
515.63 | 14.414 | -20.409
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

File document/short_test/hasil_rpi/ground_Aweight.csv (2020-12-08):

FFT | Power Spectrum
Frequency[Hz] | Level-L[dB] | Level-R[dB]
11.719 | -4.2595 | -62.053
23.438 | 15.712 | -53.553
35.156 | 11.592 | -40.313
46.875 | 17.315 | -28.453
58.594 | 18.583 | -26.442
70.313 | 20.976 | -27.684
82.031 | 24.326 | -25.751
93.75 | 20.609 | -28.373
105.47 | 17.726 | -22.46
117.19 | 16.482 | -20.735
128.91 | 17.99 | -20.078
140.63 | 21.37 | -15.147
152.34 | 20.113 | -14.312
164.06 | 16.116 | -15.113
175.78 | 13.025 | -16.248
187.5 | 20.692 | -16.844
199.22 | 21.389 | -18.11
210.94 | 17.693 | -20.133
222.66 | 15.255 | -14.222
234.38 | 16.886 | -13.469
246.09 | 14.863 | -15.352
257.81 | 17.617 | -14.391
269.53 | 18.054 | -13.877
281.25 | 16.828 | -14.292
292.97 | 15.809 | -17.236
304.69 | 15.64 | -16.121
316.41 | 16.33 | -17.994
328.13 | 17.338 | -15.679
339.84 | 19.614 | -14.688
351.56 | 16.085 | -13.871
363.28 | 12.533 | -14.516
375 | 14.823 | -16.463
386.72 | 16.358 | -16.088
398.44 | 17.514 | -15.851
410.16 | 15.984 | -10.52
421.88 | 14.612 | -14.01
433.59 | 15.989 | -12.668
445.31 | 17.88 | -9.2395
457.03 | 18.427 | -10.045
468.75 | 17.475 | -11.149
480.47 | 17.621 | -11.192
492.19 | 16.582 | -11.368
503.91 | 14.778 | -11.731
515.63 | 14.065 | -10.153
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

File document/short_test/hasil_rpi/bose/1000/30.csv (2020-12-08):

FFT | Power Spectrum
Frequency[Hz] | Level-L[dB] | Level-R[dB]
11.719 | -3.4795 | -61.84
23.438 | 16.62 | -54.719
35.156 | 12.95 | -42.332
46.875 | 15.262 | -28.02
58.594 | 19.018 | -26.386
70.313 | 17.987 | -31.609
82.031 | 22.088 | -27.816
93.75 | 23.112 | -27.181
105.47 | 19.902 | -25.976
117.19 | 15.662 | -20.965
128.91 | 18.766 | -21.288
140.63 | 23.465 | -15.244
152.34 | 19.886 | -10.682
164.06 | 14.201 | -13.873
175.78 | 15.21 | -15.736
187.5 | 20.544 | -18.212
199.22 | 23.426 | -17.05
210.94 | 17.733 | -19.277
222.66 | 16.449 | -18.275
234.38 | 19.906 | -15.574
246.09 | 18.547 | -13.541
257.81 | 15.243 | -13.371
269.53 | 16.846 | -15.514
281.25 | 17.973 | -18.359
292.97 | 15.369 | -18.138
304.69 | 16.425 | -16.892
316.41 | 14.293 | -15.48
328.13 | 16.996 | -15.853
339.84 | 16.474 | -14.512
351.56 | 14.78 | -13.623
363.28 | 14.743 | -14.924
375 | 15.43 | -13.494
386.72 | 16.998 | -15.83
398.44 | 17.56 | -13.119
410.16 | 15.336 | -12.408
421.88 | 15.861 | -13.048
433.59 | 14.837 | -13.555
445.31 | 16.294 | -10.387
457.03 | 15.018 | -10.449
468.75 | 18.492 | -10.887
480.47 | 18.588 | -9.9728
492.19 | 14.717 | -10.002
503.91 | 14.433 | -9.4463
515.63 | 18.107 | -9.7721
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

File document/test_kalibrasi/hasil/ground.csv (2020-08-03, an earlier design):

FFT | Power Spectrum
Frequency[Hz] | Level-L[dB] | Level-R[dB]
11.719 | -22.748 | -23.869
23.438 | -2.4377 | -3.2596
35.156 | -2.8895 | -3.6307
46.875 | 0.66895 | -1.7917
58.594 | 3.6379 | -0.81715
70.313 | 6.8405 | 2.4451
82.031 | 7.0675 | 4.3566
93.75 | 9.3546 | 8.1274
105.47 | 10.445 | 7.9568
117.19 | 7.6399 | 3.1805
128.91 | 6.7137 | 8.3447
140.63 | 9.6648 | 13.515
152.34 | 9.5531 | 12.291
164.06 | 5.2638 | 9.3213
175.78 | 6.1062 | 10.5
187.5 | 7.6671 | 11.653
199.22 | 8.7706 | 9.2774
210.94 | 4.5573 | 6.5587
222.66 | 8.3399 | 10.494
234.38 | 11.941 | 11.993
246.09 | 9.3557 | 9.3615
257.81 | 3.0015 | 5.531
269.53 | 5.4035 | 6.7476
281.25 | 6.3908 | 6.5342
292.97 | 4.3285 | 7.002
304.69 | 4.3796 | 5.4886
316.41 | 6.5824 | 4.5128
328.13 | 7.4344 | 6.2991
339.84 | 5.6362 | 8.5542
351.56 | 0.21426 | 8.8421
363.28 | 2.7731 | 8.09
375 | 6.9925 | 6.5848
386.72 | 6.348 | 8.2308
398.44 | 4.5687 | 7.6085
410.16 | 7.4632 | 4.7053
421.88 | 10.672 | 6.4767
433.59 | 8.6368 | 8.4024
445.31 | 3.0569 | 8.8227
457.03 | 3.9279 | 5.8401
468.75 | 6.0628 | 5.335
480.47 | 4.5289 | 5.9173
492.19 | 3.5217 | 7.7628
503.91 | 6.5538 | 7.2532
515.63 | 6.2328 | 7.3328
527.34 | 7.7609 | 6.5223
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

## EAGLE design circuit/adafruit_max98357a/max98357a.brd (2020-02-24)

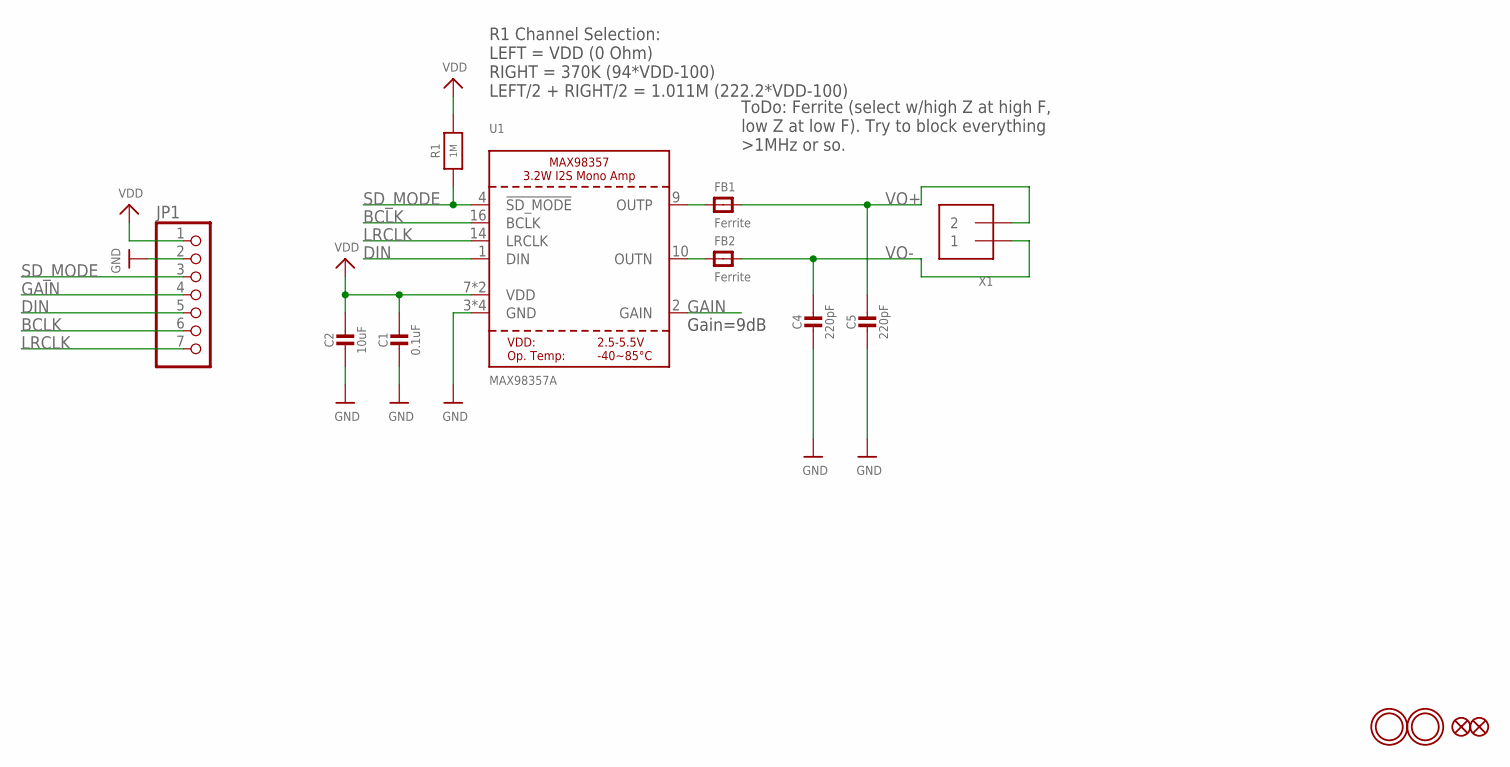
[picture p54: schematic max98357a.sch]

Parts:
C1: 0.1uF; 0805-NO
C2: 10uF; 0805-NO
C4, C5: 220pF; 0805-NO
FB1, FB2: Ferrite; 0805-NO
FID1, FID2: FIDUCIAL""; FIDUCIAL_1MM
JP1: HEADER-1X7THICKER; 1X07_ROUND_76
R1: 1M; 0805-NO
U1: MAX98357A; QFN16_3MM
U$9, U$10: MOUNTINGHOLE2.5; MOUNTINGHOLE_2.5_PLATED
X1: TERMBLOCK_1X2; TERMBLOCK_1X2-3.5MM

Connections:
BCLK: JP1.6, U1.16 (BCLK)
DIN: JP1.5, U1.1 (DIN)
GAIN: JP1.4, U1.2 (GAIN)
GND: C1.2, C2.2, C4.2, C5.2, JP1.2, U1.3 (GND), U1.11 (GND), U1.15 (GND), U1.THERMAL (GND)
LRCLK: JP1.7, U1.14 (LRCLK)
unnamed: FB2.1, U1.10 (OUTN)
unnamed: FB1.1, U1.9 (OUTP)
SD_MODE: JP1.3, R1.1, U1.4 (!SD_MODE)
VDD: C1.1, C2.1, JP1.1, R1.2, U1.7 (VDD), U1.8 (VDD)
VO+: C5.1, FB1.2, X1.2
VO-: C4.1, FB2.2, X1.1

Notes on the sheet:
R1 Channel Selection: LEFT = VDD (0 Ohm) RIGHT = 370K (94*VDD-100) LEFT/2 + RIGHT/2 = 1.011M (222.2*VDD-100)
ToDo: Ferrite (select w/high Z at high F, low Z at low F). Try to block everything >1MHz or so.
Gain=9dB

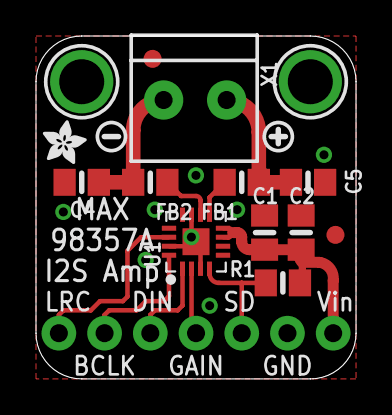
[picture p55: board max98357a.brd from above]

Board: 2 copper layers, 17.8 x 19.1 mm, 18 parts (1 on the bottom side), 11 nets.

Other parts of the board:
U$6: SYMBOL_PLUS
U$11: SYMBOL_MINUS
U$14: ADAFRUIT_2.5MM
U$15: PCBFEAT-REV-040

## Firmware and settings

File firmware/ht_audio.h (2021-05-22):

/*
    Embedded Audiometri - Copyright (C) 2020 Achmadi

    github.com/mekatronik-achmadi/ or mekatronik-achmadi@gmail.com

    Licensed under the Apache License, Version 2.0 (the "License");
    you may not use this file except in compliance with the License.
    You may obtain a copy of the License at

        http://www.apache.org/licenses/LICENSE-2.0

    Unless required by applicable law or agreed to in writing, software
    distributed under the License is distributed on an "AS IS" BASIS,
    WITHOUT WARRANTIES OR CONDITIONS OF ANY KIND, either express or implied.
    See the License for the specific language governing permissions and
    limitations under the License.
*/

/**
 * @file    ht_audio.h
 * @brief   Audio Generator header.
 *
 * @addtogroup Audio
 * @{
 */

#ifndef HT_AUDIO_H
#define HT_AUDIO_H

#include "user_conf.h"

/**
 * @brief GPIO Port to enables Audio DAC
 */
#define AUDIO_IO    GPIOC

/**
 * @brief Pin to enables LEFT Audio DAC on GPIOC.9
 */
#define AUDIO_L     9

/**
 * @brief Pin to enables RIGHT Audio DAC on GPIOC.8
 */
#define AUDIO_R     8

/**
 * @brief Play Left Audio DAC
 */
#define OUT_LEFT    0

/**
 * @brief Play Right Audio DAC
 */
#define OUT_RIGHT   1

/**
 * @brief Default Attenuation scale
 * @details Dont increase as it will make noise more prominent
 */
#define DEFAULT_ATTEN 0.01

/**
 * @brief Default Minimum threshold of 16-bit amplitude
 */
#define DEFAULT_AMPL_THD 1

/**
 * @brief I2S protocol buffer size
 * @details If I2S-SPI and MMC-SPI use same DMA stream, set to 512.
 *          Please check DMA stream ID on both SPI peripherals.
 */
#define I2S_BUFF_SIZE   512

/**
 * @brief Total buffer size
 * @details Just fill it below 44100
 */
#define TOTAL_BUFF_SIZE I2S_BUFF_SIZE*16

/**
 * @brief Wheter use Left/Right or Mono array
 */
#define USE_STEREO_ARRAY TRUE

/**
 * @brief Global Duration for Testing
 * @details Range is 1 to 250 while 100 means 1000ms
 */
#define TEST_DURATION   10

/**
 * @brief Smallest signal scale can produced as far for now
 * @details Note this use DEFAULT_ATTEN at 0.01
 * @details So signal value is SMALLEST_DB*DEFAULT_ATTEN*32767=1
 */
#define SMALLEST_DB     0.0031

/**
 * @brief First dB scale at first step on audiotest
 */
#define FIRSTTEST_DB     1

/**
 * @brief Initiate Audio driver via I2S
 */
void ht_audio_Init(void);

/**
 * @brief Generate sine wave with only zero
 */
void ht_audio_Zero(void);

/**
 * @brief Generate sine wave tone from halving formula with Frequency and Amplitude
 * @details This function intended to be actual implementaion of sample preparation
 * @param[in] double Sine wave sample frequency in linear scaling from 400Hz (0.25,0.5,1,2,4,8,16,32) -> 500Hz=1.25
 * @param[in] double Sine wave sample amplitude in linear scaling from 100dB (1 ~ 0.0001 or use ht_audio_Zero())
 */
void ht_audio_Tone(double freq, double ampl);

/**
 * @brief Generate sine wave tone from halving formula with Frequency and Amplitude
 * @details This function intended to be actual implementaion of sample preparation
 * @param[in] double Sine wave sample frequency in linear scaling from 400Hz (0.25,0.5,1,2,4,8,16,32) -> 500Hz=1.25
 * @param[in] double Sine wave sample amplitude scale in linear scaling from 9 to 1 (9 is loudest)
 */
void ht_audio_ToneScale(double freq, double scale);

/**
 * @brief Play Audio via I2S
 * @details Play I2S Transmit buffer in loop
 * @param[in] uint8_t Duration to play loop (milliseconds)
 */
void ht_audio_Play(uint16_t duration);

/**
 * @brief Disable both DAC channel
 * @details Must called after every @p ht_audio_Play()
 */
void ht_audio_DisableCh(void);

/**
 * @brief Enable DAC Left Channel
 */
void ht_audio_LeftCh(void);

/**
 * @brief Enable DAC Right Channel
 */
void ht_audio_RightCh(void);

/**
 * @brief Generate tone for testing
 */
void ht_audio_TestTone(void);

/**
 * @brief Test Audio DAC Left then Right
 */
void ht_audio_TestBoth(void);

/**
 * @brief Test Audio DAC Left only
 */
void ht_audio_TestLeft(void);

/**
 * @brief Test Audio DAC Right only
 */
void ht_audio_TestRight(void);

#endif // HT_AUDIO_H
/** @} */

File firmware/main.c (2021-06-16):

/*
    Embedded Audiometri - Copyright (C) 2020 Achmadi

    github.com/mekatronik-achmadi/ or mekatronik-achmadi@gmail.com

    Licensed under the Apache License, Version 2.0 (the "License");
    you may not use this file except in compliance with the License.
    You may obtain a copy of the License at

        http://www.apache.org/licenses/LICENSE-2.0

    Unless required by applicable law or agreed to in writing, software
    distributed under the License is distributed on an "AS IS" BASIS,
    WITHOUT WARRANTIES OR CONDITIONS OF ANY KIND, either express or implied.
    See the License for the specific language governing permissions and
    limitations under the License.
*/

/**
 * @file    main.c
 * @brief   Main code.
 *
 * @addtogroup Main
 * @{
 */

#include "ch.h"
#include "hal.h"
#include "chprintf.h"

#include "user_conf.h"

#include "ht_audio.h"
#include "ht_exti.h"
#include "ht_led.h"
#include "ht_console.h"
#include "ht_mmc.h"
#include "ht_metri.h"

extern uint8_t mode_status;
extern uint8_t mode_led;

/**
 * @brief status to control LED thread start
 */
static uint8_t stt_readyAll = FALSE;

static THD_WORKING_AREA(waRunLed, 128);
#define ThdFunc_RunLED THD_FUNCTION

/**
 * @brief Thread for System Running Indicator
 * @details Smallest Thread to check either system in Run or Freeze
 */
static ThdFunc_RunLED(thdRunLed, arg) {
  (void)arg;
  chRegSetThreadName("run led");

  while (true) {

#if USER_TEST_STATE
    if(mode_led==LED_FAIL){
        led_result_off();

        palClearPad(GPIOA, LED_RUN);
        chThdSleepMilliseconds(200);

        palSetPad(GPIOA, LED_RUN);
        chThdSleepMilliseconds(200);

        palClearPad(GPIOA, LED_RUN);
        chThdSleepMilliseconds(200);

        palSetPad(GPIOA, LED_RUN);
        chThdSleepMilliseconds(200);

 #if USER_LED_BUTTON
        led_result_off();
        led_resultYES();
        chThdSleepMilliseconds(200);

        led_result_off();
        led_resultNO();
        chThdSleepMilliseconds(200);
 #else
        chThdSleepMilliseconds(400);
 #endif
    }
    else if(mode_led==LED_READY){
        palTogglePad(GPIOA, LED_RUN);

 #if USER_LED_BUTTON
        led_result_off();
        led_resultYES();
        chThdSleepMilliseconds(200);

        led_result_off();
        led_resultNO();
        chThdSleepMilliseconds(200);
 #else
        chThdSleepMilliseconds(400);
 #endif
    }
#else
    if(mode_led==LED_FAIL){
        palClearPad(GPIOA, LED_RUN);
        chThdSleepMilliseconds(50);
        palSetPad(GPIOA, LED_RUN);
        chThdSleepMilliseconds(100);
        palClearPad(GPIOA, LED_RUN);
        chThdSleepMilliseconds(50);
        palSetPad(GPIOA, LED_RUN);
        chThdSleepMilliseconds(1500);
    }
    else if(mode_led==LED_READY){
        palTogglePad(GPIOA, LED_RUN);
        chThdSleepMilliseconds(500);
    }
    else if(mode_led==LED_CFILE){
        palSetPad(GPIOA, LED_RUN);
        chThdSleepMilliseconds(1);
    }
    else if(mode_led==LED_METRI){
        palTogglePad(GPIOA, LED_RUN);
        chThdSleepMilliseconds(50);
    }
#endif

  }
}

/**
 * @brief Main Function as start entry
 * @return Nothing
 */
int main(void){
    halInit();
    chSysInit();

    palSetPadMode(GPIOA,LED_RUN,PAL_MODE_OUTPUT_PUSHPULL);
    palClearPad(GPIOA,LED_RUN);

#if USER_LED_BUTTON
    ht_led_Init();
    ht_led_Test();
    ht_exti_Init();
#endif

#if USER_MMC
   ht_mmc_Init();
   ht_mmc_initCheck();
#endif

#if USER_SERIAL
 ht_commUSB_Init();

 #if USER_IOT
   ht_commUART_Init();
 #endif
#endif

#if USER_AUDIO
    ht_audio_Init();
 #if USER_AUDIO_STARTUP
    ht_audio_TestBoth();
 #endif
#endif

#if USER_METRI
    ht_metri_Init();
#endif

    while(1){

#if USER_SERIAL
 ht_commUSB_shInit();

 #if USER_IOT
    ht_commUART_shInit();
 #endif
#endif
        if(stt_readyAll==FALSE){
            chThdSleepMilliseconds(500);
            chThdCreateStatic(waRunLed, sizeof(waRunLed),	NORMALPRIO, thdRunLed, NULL);
            ht_comm_Msg("All System Ready\r\n");
            stt_readyAll = TRUE;
        }

        chThdSleepMilliseconds(500);
    }
}
/** @} */

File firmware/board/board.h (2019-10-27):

/*
    ChibiOS - Copyright (C) 2006..2015 Giovanni Di Sirio

    Licensed under the Apache License, Version 2.0 (the "License");
    you may not use this file except in compliance with the License.
    You may obtain a copy of the License at

        http://www.apache.org/licenses/LICENSE-2.0

    Unless required by applicable law or agreed to in writing, software
    distributed under the License is distributed on an "AS IS" BASIS,
    WITHOUT WARRANTIES OR CONDITIONS OF ANY KIND, either express or implied.
    See the License for the specific language governing permissions and
    limitations under the License.
*/

/**
 * @file    board.h
 * @brief   Platform Board header.
 *
 * @addtogroup Platform
 * @{
 */

#ifndef _BOARD_H_
#define _BOARD_H_

/*
 * Setup for STMicroelectronics NUCLEO-F401RE board.
 */

/*
 * Board identifier.
 */
#define BOARD_ST_NUCLEO_F401RE
#define BOARD_NAME                  "STMicroelectronics NUCLEO-F401RE"


/*
 * Board oscillators-related settings.
 * NOTE: LSE not fitted.
 * NOTE: HSE not fitted.
 */
#if !defined(STM32_LSECLK)
#define STM32_LSECLK                0U
#endif

#if !defined(STM32_HSECLK)
#define STM32_HSECLK                0U
#endif

/*
 * Board voltages.
 * Required for performance limits calculation.
 */
#define STM32_VDD                   300U

/*
 * MCU type as defined in the ST header.
 */
#define STM32F401xE

/*
 * IO pins assignments.
 */
#define GPIOA_PIN0                  0U
#define GPIOA_PIN1                  1U
#define GPIOA_PIN2                  2U
#define GPIOA_PIN3                  3U
#define GPIOA_PIN4                  4U
#define GPIOA_LED_GREEN             5U
#define GPIOA_PIN6                  6U
#define GPIOA_PIN7                  7U
#define GPIOA_PIN8                  8U
#define GPIOA_PIN9                  9U
#define GPIOA_PIN10                 10U
#define GPIOA_OTG_FS_DM             11U
#define GPIOA_OTG_FS_DP             12U
#define GPIOA_SWDIO                 13U
#define GPIOA_SWCLK                 14U
#define GPIOA_PIN15                 15U

#define GPIOB_PIN0                  0U
#define GPIOB_PIN1                  1U
#define GPIOB_PIN2                  2U
#define GPIOB_PIN3                  3U
#define GPIOB_PIN4                  4U
#define GPIOB_PIN5                  5U
#define GPIOB_PIN6                  6U
#define GPIOB_PIN7                  7U
#define GPIOB_PIN8                  8U
#define GPIOB_PIN9                  9U
#define GPIOB_PIN10                 10U
#define GPIOB_PIN11                 11U
#define GPIOB_PIN12                 12U
#define GPIOB_PIN13                 13U
#define GPIOB_PIN14                 14U
#define GPIOB_PIN15                 15U

#define GPIOC_PIN0                  0U
#define GPIOC_PIN1                  1U
#define GPIOC_PIN2                  2U
#define GPIOC_PIN3                  3U
#define GPIOC_PIN4                  4U
#define GPIOC_PIN5                  5U
#define GPIOC_PIN6                  6U
#define GPIOC_PIN7                  7U
#define GPIOC_PIN8                  8U
#define GPIOC_PIN9                  9U
#define GPIOC_PIN10                 10U
#define GPIOC_PIN11                 11U
#define GPIOC_PIN12                 12U
#define GPIOC_BUTTON                13U
#define GPIOC_PIN14                 14U
#define GPIOC_PIN15                 15U

#define GPIOD_PIN0                  0U
#define GPIOD_PIN1                  1U
#define GPIOD_PIN2                  2U
#define GPIOD_PIN3                  3U
#define GPIOD_PIN4                  4U
#define GPIOD_PIN5                  5U
#define GPIOD_PIN6                  6U
#define GPIOD_PIN7                  7U
#define GPIOD_PIN8                  8U
#define GPIOD_PIN9                  9U
#define GPIOD_PIN10                 10U
#define GPIOD_PIN11                 11U
#define GPIOD_PIN12                 12U
#define GPIOD_PIN13                 13U
#define GPIOD_PIN14                 14U
#define GPIOD_PIN15                 15U

#define GPIOE_PIN0                  0U
#define GPIOE_PIN1                  1U
#define GPIOE_PIN2                  2U
#define GPIOE_PIN3                  3U
#define GPIOE_PIN4                  4U
#define GPIOE_PIN5                  5U
#define GPIOE_PIN6                  6U
#define GPIOE_PIN7                  7U
#define GPIOE_PIN8                  8U
#define GPIOE_PIN9                  9U
#define GPIOE_PIN10                 10U
#define GPIOE_PIN11                 11U
#define GPIOE_PIN12                 12U
#define GPIOE_PIN13                 13U
#define GPIOE_PIN14                 14U
#define GPIOE_PIN15                 15U
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

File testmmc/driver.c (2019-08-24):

#include "ch.h"
#include "hal.h"
#include "chprintf.h"
#include "ff.h"

#include "../driver.h"

//================================================================================

static uint16_t led_delay = 10;

static THD_WORKING_AREA(waLed1, 128);
static THD_FUNCTION(thdLed1, arg) {

  (void)arg;
  chRegSetThreadName("led1");
  while (true) {
    palTogglePad(GPIOA, 5);
    chThdSleepMilliseconds(led_delay);
  }
}

static void led_start(void){
    palSetPadMode(GPIOA,5,PAL_MODE_OUTPUT_PUSHPULL);
    palClearPad(GPIOA,5);

    chThdCreateStatic(waLed1, sizeof(waLed1),	NORMALPRIO, thdLed1, NULL);
}

//================================================================================

#define LED_TRUE    0 //PA.0
#define LED_FALSE   1 //PA.1
#define LED_ANSA    4 //PA.4
#define LED_ANSB    0 //PB.0

#define LED_AMPL    2 //PA.2
#define LED_FREQ    3 //PA.3

#define LED_M1      15 //PB.15
#define LED_M2      5 //PB.5
#define LED_M3      4 //PB.4
#define LED_M4      13 //PB.13
#define LED_M5      14 //PB.14

static void indicator_start(void){
    palSetPadMode(GPIOA,LED_TRUE,PAL_MODE_OUTPUT_PUSHPULL);
    palSetPadMode(GPIOA,LED_FALSE,PAL_MODE_OUTPUT_PUSHPULL);
    palSetPadMode(GPIOA,LED_ANSA,PAL_MODE_OUTPUT_PUSHPULL);
    palSetPadMode(GPIOB,LED_ANSB,PAL_MODE_OUTPUT_PUSHPULL);
    
    palSetPad(GPIOA,LED_TRUE);
    palSetPad(GPIOA,LED_FALSE);
    palSetPad(GPIOA,LED_ANSA);
    palSetPad(GPIOB,LED_ANSB);

    palSetPadMode(GPIOA,LED_AMPL,PAL_MODE_OUTPUT_PUSHPULL);
    palSetPadMode(GPIOA,LED_FREQ,PAL_MODE_OUTPUT_PUSHPULL);

    palSetPadMode(GPIOB,LED_M1,PAL_MODE_OUTPUT_PUSHPULL);
    palSetPadMode(GPIOB,LED_M2,PAL_MODE_OUTPUT_PUSHPULL);
    palSetPadMode(GPIOB,LED_M3,PAL_MODE_OUTPUT_PUSHPULL);
    palSetPadMode(GPIOB,LED_M4,PAL_MODE_OUTPUT_PUSHPULL);
    palSetPadMode(GPIOB,LED_M5,PAL_MODE_OUTPUT_PUSHPULL);
}

//================================================================================

#define MMC_SPI_OK 0
#define MMC_SPI_FAIL 1
#define MMC_SPI_ERROR 2

#define USE_MMC_CHK 1

MMCDriver MMCD1;

static bool filesystem_ready=true;
static uint8_t mmc_spi_status_flag=MMC_SPI_OK;

static SPIConfig hs_spicfg = {NULL, GPIOA, 4, 0};
static SPIConfig ls_spicfg = {NULL, GPIOA, 4, SPI_CR1_BR_2 | SPI_CR1_BR_1};
static MMCConfig mmccfg = {&SPID3, &ls_spicfg, &hs_spicfg};

#if USE_MMC_CHK
static void mmc_check(void){
    FATFS FatFs;
    FRESULT err;
    uint32_t clusters;
    FATFS *fsp;

    mmc_spi_status_flag=MMC_SPI_OK;
    filesystem_ready=false;

    if(mmcConnect(&MMCD1)) { filesystem_ready = true; }

    err = f_mount(&FatFs, "", 0);
    if(err == FR_OK){ filesystem_ready = true; }

    if (!filesystem_ready) { mmc_spi_status_flag=MMC_SPI_FAIL;return; }

    mmc_spi_status_flag=MMC_SPI_ERROR;
    err = f_getfree("/", &clusters, &fsp);

    if(err == FR_OK){
        mmc_spi_status_flag=MMC_SPI_OK;
        palClearPad(GPIOA,LED_TRUE);
    }
    else if(err == FR_DISK_ERR){ palClearPad(GPIOA,LED_FALSE); }
    else if(err == FR_INT_ERR){ palClearPad(GPIOA,LED_ANSA); }
    else if(err == FR_NOT_READY){ palClearPad(GPIOA,LED_ANSB); }

    f_mount(0, "", 0);
}
#endif

static void mmc_test(void){
    char buffer[36];

    FATFS *FatFs;
    FIL Fil;
    UINT bw;

    FRESULT err;

    FatFs = malloc(sizeof (FatFs));

#if USE_MMC_CHK
    mmc_check();
#endif

    if( (filesystem_ready==true) && (mmc_spi_status_flag==MMC_SPI_OK) ){
        chsnprintf(buffer,36,"Test");

        f_mount(FatFs, "", 0);

        f_open(&Fil, "tes.txt", FA_WRITE | FA_CREATE_ALWAYS);
        f_lseek(&Fil, f_size(&Fil));
        err = f_write(&Fil, buffer, strlen(buffer), &bw);
        f_close(&Fil);

        if(err == FR_INVALID_OBJECT ){ led_delay=500; }
        else if(err == FR_WRITE_PROTECTED ){led_delay=50;}

        f_mount(0, "", 0);
        free(FatFs);
    }
}

static void mmc_start(void){
    palSetPadMode(GPIOC, 12, PAL_MODE_ALTERNATE(5)); //MOSI
    palSetPadMode(GPIOC, 11, PAL_MODE_ALTERNATE(5)); //MISO
    palSetPadMode(GPIOC, 10, PAL_MODE_ALTERNATE(5)); //SCK
    palSetPadMode(GPIOA, 15, PAL_MODE_OUTPUT_PUSHPULL); //NSS
    palSetPad(GPIOA, 15);

    mmcObjectInit(&MMCD1);
    mmcStart(&MMCD1, &mmccfg);
    chThdSleepMilliseconds(100);

    palSetPadMode(GPIOA,5,PAL_MODE_OUTPUT_PUSHPULL);
    palClearPad(GPIOA,5);
}

static void mmc_pintest(void){
    palSetPadMode(GPIOC, 12, PAL_MODE_INPUT_PULLUP); //MISO
    chThdSleepMilliseconds(100);

    if(palReadPad(GPIOC,12)){
        palClearPad(GPIOA,LED_TRUE);
    }
    else{
        palClearPad(GPIOA,LED_FALSE);
    }
}

//================================================================================

// ============================= Platform Calling ===================

void system_init(void){
	halInit();
	chSysInit();

    indicator_start();
//    mmc_pintest();
    mmc_start();
    mmc_test();

    led_start();
}

void driver_init(void){chThdSleepMilliseconds(100);}
void sample_prep(
    double FR, // Frequency (Hz)
    double DUR, //Duration (s)
    int AMP) //Amplitudo
{ (void) FR;(void) DUR;(void) AMP; chThdSleepMilliseconds(100); }
void play_wave(void){chThdSleepMilliseconds(100);}
void system_loop(void){chThdSleepMilliseconds(100);}

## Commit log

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2019-07-22 Sampling rate fix on 44100
    [driver.c]
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2019-07-26 board stm32f401 nucleo expansion
    [piko_stm32f4nucl.kicad_pcb, piko_stm32f4nucl.sch]
2019-07-26 pcb design for stm32f401nucl
    [piko_stm32f4nucl.kicad_pcb, piko_stm32f4nucl.sch]
2019-07-27 stm32f401 nucleo PCB
    [piko_stm32f4nucl.kicad_pcb, piko_stm32f4nucl.sch]
2019-07-27 PCB stm32f401 nucleo
    [piko_stm32f4nucl.kicad_pcb, piko_stm32f4nucl.sch]
2019-07-27 progress nucleo board
    [piko_stm32f4nucl.kicad_pcb]
2019-07-27 update polygon
    [piko_stm32f4nucl.kicad_pcb]
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2019-08-16 mmc not reply
    [piko_stm32f4nucl.kicad_pcb, piko_stm32f4nucl.sch]
2019-08-16 mmc spi still failed
    [driver.c]
2019-08-16 SPI3 MMC not working
    [driver.c, mcuconf.h]
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2019-10-29 REWRITE !!!!!!!
    [piko_stm32f4nucl.kicad_pcb, piko_stm32f4nucl.sch]
2019-10-30 test 0 PCB
    [piko_stm32f4nucl.kicad_pcb, piko_stm32f4nucl.sch]
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2019-11-06 dokumentasi kegiatan ITB
    [BaseZero.csv, FreqResp_JBL.csv, arr_rev_sine.csv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]
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2019-11-11 update dokumen log harian
    [BaseZero.csv, FreqResp_JBL.csv, arr_rev_sine.csv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]
2019-11-13 dokumentasi log harian ITB
    [fft_sine0p25.csv, fft_sine0p5.csv, fft_sine1.csv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]
2019-12-10 read file still not work
    [ht_comm.c, ht_mmc.c, ht_mmc.h]
2019-12-16 new PCB
    [end_stm32f401re.kicad_pcb, end_stm32f401re.sch]
2019-12-18 PCB next proto design
    [end_stm32f401re.kicad_pcb, end_stm32f401re.sch]
2019-12-19 branch based on main chip
    [BaseZero.csv, FreqResp_JBL.csv, arr_rev_sine.csv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]
2020-01-02 new simplified pcb
    [end_stm32f401re.kicad_pcb, end_stm32f401re.sch]
2020-01-03 test 2 ok
    [end_stm32f401re.kicad_pcb, end_stm32f401re.sch]
2020-01-03 test 2 progress
    [end_stm32f401re.kicad_pcb, end_stm32f401re.sch]
2020-01-03 PCB board and test
    [end_stm32f401re.kicad_pcb, end_stm32f401re.sch]
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2020-01-04 capek uuuyyyy
    [end_stm32f401re.kicad_pcb, end_stm32f401re.sch]
2020-01-04 out audio pake induktor/capasitor
    [end_stm32f401re.kicad_pcb, end_stm32f401re.sch]
2020-01-07 3 varian PCB test
    [end_stm32f401re.kicad_pcb, end_stm32f401re.sch]
2020-01-07 add diode on power reg
    [end_stm32f401re.kicad_pcb, end_stm32f401re.sch]
2020-01-14 nucleo64 board
    [nucleo64.kicad_pcb, nucleo64.sch]
2020-01-14 RESET to START
    [end_stm32f401re.kicad_pcb, end_stm32f401re.sch]
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2020-01-30 revisi microUSB
    [end_stm32f401re.kicad_pcb, end_stm32f401re.sch]
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2020-02-02 UART replaced by USB-CDC
    [akustik.ioc, halconf.h, ht_comm.c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]
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2020-02-03 shorten i2s test duration
    [ht_audio.h]
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2020-02-08 checking save file error
    [ht_comm.c, ht_exti.c, ht_metri.h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]
2020-02-24 basic platform OK
    [end_stm32f401re.kicad_pcb, end_stm32f401re.sch]
2020-02-24 non doxygen document on separate repository
    [BaseZero.csv, FreqResp_JBL.csv, arr_rev_sine.csv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]
2020-02-24 drop other 2p design
    [end_stm32f401re.kicad_pcb, end_stm32f401re.sch, nucleo64.kicad_pcb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]
2020-02-24 adafruit max98357a
    [max98357a.brd, max98357a.sch]
2020-02-24 create new PCB
    [end_stm32f401re.kicad_pcb]
2020-02-24 update skema to 3pin
    [end_stm32f401re.sch]
2020-02-24 add IoT module
    [end_stm32f401re.kicad_pcb, end_stm32f401re.sch]
2020-02-25 designed complete
    [end_stm32f401re.kicad_pcb, end_stm32f401re.sch]
2020-02-25 design 3 completed
    [end_stm32f401re.kicad_pcb]
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2020-02-25 ready to print
    [end_stm32f401re.kicad_pcb]
2020-02-25 ready to manufactured
    [end_stm32f401re.sch]
2020-03-09 small revision
    [end_stm32f401re.kicad_pcb]
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2020-04-19 PCB revision
    1. Microsd use TF model
    2. Diode moved before AMS1117
    [end_stm32f401re.kicad_pcb, end_stm32f401re.sch]
2020-04-22 SVG Box
    [end_stm32f401re.kicad_pcb]
2020-04-23 varian board untuk experimental
    [board_stm32f401re.kicad_pcb, board_stm32f401re.sch]
2020-04-23 nucleo based prototype
    [board_stm32f401re.kicad_pcb, board_stm32f401re.sch]
2020-04-23 update addon board
    [board_stm32f401re.sch]
2020-04-23 wrong microsd socket
2020-04-23 new add on board
    [board_stm32f401re.kicad_pcb, board_stm32f401re.sch]
2020-04-25 add ESP on board module
    [board_stm32f401re.kicad_pcb, board_stm32f401re.sch, end_stm32f401re.sch]
2020-05-28 USB and MMC after reset still wrong
    [ht_comm.c, ht_mmc.c]
2020-05-29 MMC work but buggy
    [akustik.ioc, main.c]
2020-05-30 rework some MMC API
    [ht_comm.c, ht_mmc.c]
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2020-06-01 MMC_NSS on PA.15 not PA.14 you IDIOT!!!
    [board_stm32f401re.kicad_pcb, board_stm32f401re.sch]
2020-06-16 RNG not work but acceptable
    [ht_mmc.c, user_conf.h]
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2020-06-25 VREF (P13) need VDD
    [end_stm32f401re.kicad_pcb, end_stm32f401re.sch]
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2020-07-01 Board revision
    [end_stm32f401re.kicad_pcb, end_stm32f401re.sch]
2020-07-01 add teardrop
    [end_stm32f401re.kicad_pcb]
2020-07-02 fix incorrect number interrupt
    [ht_exti.c]
2020-07-16 thereis noise on output
    [ht_audio.h, ht_comm.c, ht_exti.c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]
2020-07-17 update PCB
    [end_stm32f401re.kicad_pcb, end_stm32f401re.sch]
2020-07-17 noise on unactivated still exist
    [ht_comm.c]
2020-07-29 dokumen kalibrasi
    [0.0039.csv, 0.0078.csv, 0.0156.csv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]
2020-08-01 dokumen progress
    [lrc.sch]
2020-08-03 kenion data
    [0.0039.csv, 0.0078.csv, 0.0156.csv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]
2020-08-03 dokumen laporan progres
    [0.0039.csv, 0.0078.csv, 0.0156.csv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]
2020-09-15 reset button
    [end_stm32f401re.kicad_pcb, end_stm32f401re.sch]
2020-10-07 add Mic to Sch
    [end_stm32f401re.sch]
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2020-10-08 output print
    [end_stm32f401re.kicad_pcb]
2020-11-20 something wrong with MMC
    [user_conf.h]
2020-11-21 3D print STL
    [bottom-rpi.stl, bottom.stl, top-rpi.stl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]
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2020-12-02 prototype fix
2020-12-04 top casing without holder handler
    [top_noholder.stl]
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2020-12-08 short test rpi
    [1000.csv, 16000.csv, 2000.csv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]
2021-01-18 box 3D paten
    [box.FCStd, pwr_sw.kicad_pcb, pwr_sw.sch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]
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2021-05-21 tabel data ITB lanjutan
    [Pengujian Audiometry Hari 1.xlsx, Pengujian Audiometry Hari 2.xlsx, Pengujian Audiometry Hari 3.xlsx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]
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2021-07-14 some design
    [end_stm32f401re-B_Cu.gbr, end_stm32f401re-F_Cu.gbr]
2021-07-26 untrack fabricate PCB
    [end_stm32f401re-B_Cu.gbr, end_stm32f401re-F_Cu.gbr]
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

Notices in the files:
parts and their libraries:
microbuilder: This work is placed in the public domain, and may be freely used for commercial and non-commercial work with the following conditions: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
